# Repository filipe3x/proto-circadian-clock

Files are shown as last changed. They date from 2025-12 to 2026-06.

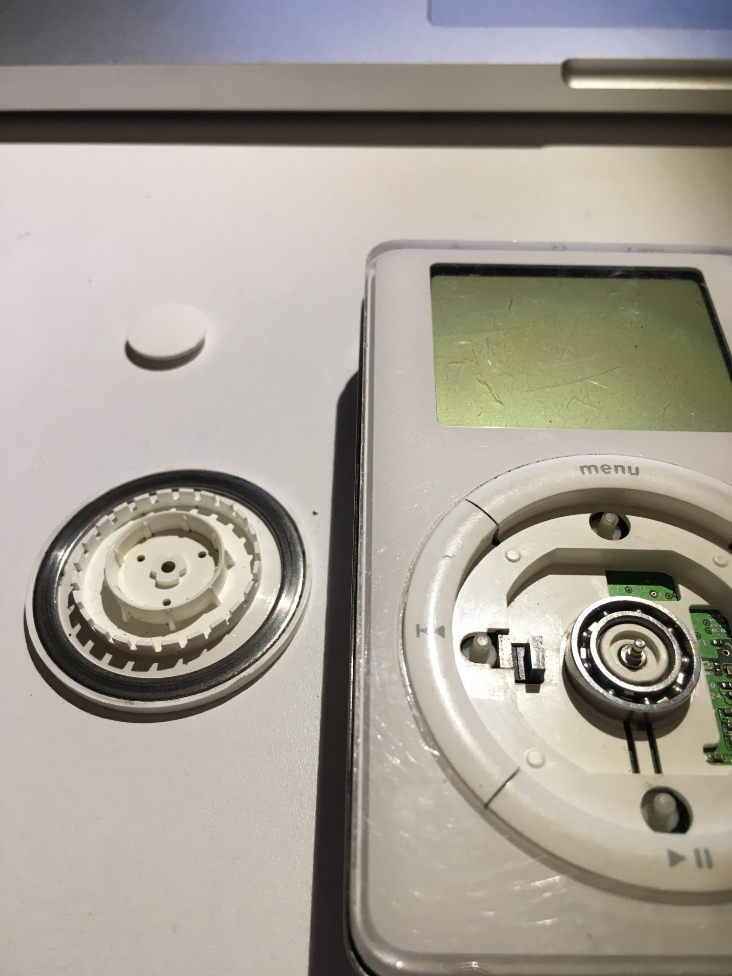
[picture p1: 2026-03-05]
product/click wheel ipod 1gen.JPG

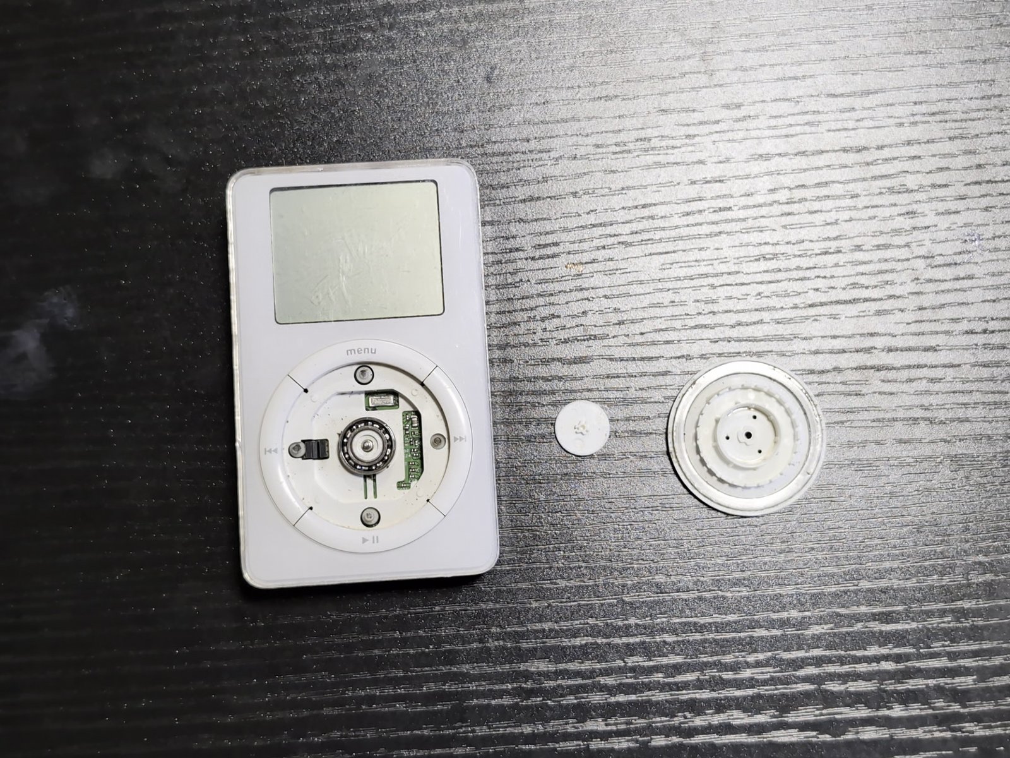
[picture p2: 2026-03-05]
product/click wheel ipod 1gen _2.jpg

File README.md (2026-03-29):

# 🌅 Proto Circadian Clock

An ESP32-powered LED clock that simulates the natural solar light cycle to support healthy circadian rhythms. The display gradually transitions from warm red tones at sunrise/sunset to bright white at midday, mimicking natural daylight patterns.

## Features

- **Automatic Solar Simulation** - Real-time color temperature based on astronomical sun position
- **Red Light Therapy Mode** - Pure red light for evening relaxation
- **Multi-WiFi Support** - Connects to multiple configured networks with automatic fallback
- **Offline Operation** - Works without internet using RTC or internal clock
- **NTP Synchronization** - Keeps time accurate via internet time servers
- **Low Power** - Disconnects WiFi after sync to save energy
- **Startup Sound & Alerts** - Retro-style 8-bit chiptune sounds on boot (can be disabled via captive portal)

## Hardware Requirements

| Component | Specification |
|---|---|
| Microcontroller | ESP32 Dev Module (4MB Flash) |
| Display | P10 32×16 RGB LED Panel (HUB75, 1/4 scan, SMD3535) |
| RTC (Optional) | DS3231 module |
| Button | Momentary push button |
| Buzzer (Optional) | MLT-5030 piezo buzzer or similar (passive, 3V, 5×5mm) |
| Power | 5V 2A minimum |

## Wiring

### Pinout Absoluto ESP32 — Todos os GPIOs

```
┌─────────────────────────────────────────────────────────────────┐
│                    ESP32-WROOM-32E  PINOUT                      │
├───────┬──────────────┬──────────┬───────────────────────────────┤
│ GPIO  │ Função       │ Direção  │ Notas                        │
├───────┼──────────────┼──────────┼───────────────────────────────┤
│       │ ── HUB75 (Painel P10 RGB) ──                           │
│  4    │ LAT          │ Output   │ Latch                        │
│  5    │ C            │ Output   │ Row select bit 2             │
│ 12    │ G2           │ Output   │ Green lower                  │
│ 13    │ B2           │ Output   │ Blue lower                   │
│ 14    │ R2           │ Output   │ Red lower                    │
│ 15    │ OE           │ Output   │ Output Enable (active LOW)   │
│ 16    │ CLK          │ Output   │ Pixel clock                  │
│ 17    │ D            │ Output   │ Row select bit 3             │
│ 19    │ B            │ Output   │ Row select bit 1             │
│ 23    │ A            │ Output   │ Row select bit 0             │
│ 25    │ R1           │ Output   │ Red upper                    │
│ 26    │ G1           │ Output   │ Green upper                  │
│ 27    │ B1           │ Output   │ Blue upper                   │
├───────┼──────────────┼──────────┼───────────────────────────────┤
│       │ ── I2C (RTC + OLED) ──                                 │
│ 21    │ SDA          │ Bidi     │ DS3231 (0x68) + SSD1306 (0x3C) │
│ 22    │ SCL          │ Bidi     │ Barramento partilhado        │
├───────┼──────────────┼──────────┼───────────────────────────────┤
│       │ ── Input (partilhado — ver INPUT_MODE) ──              │
│ 34    │ ENC_A/BTN_A  │ Input    │ Pull-up 10kΩ ext. Encoder A ou Botão A │
│ 35    │ ENC_B/BTN_B  │ Input    │ Pull-up 10kΩ ext. Encoder B ou Botão B │
│ 36    │ BTN_L        │ Input    │ Pull-up 10kΩ ext. Exclusivo DevKit     │
│ 39    │ ENC_BTN/BTN_R│ Input    │ Pull-up 10kΩ ext. Enc Click ou Botão R │
├───────┼──────────────┼──────────┼───────────────────────────────┤
│       │ ── Outros ──                                           │
│  0    │ BOOT Button  │ Input    │ INPUT_PULLUP, modo cycle     │
│  2    │ LED_BUILTIN  │ Output   │ LED azul onboard             │
│ 18    │ BUZZER       │ Output   │ PWM → R 1kΩ → Q1 MMBT2222A  │
│ 33    │ VBUS_SENSE   │ Input    │ ADC1_CH5, deteção 20V        │
│  1    │ DEBUG TX     │ Output   │ UART0 TX (USB-UART)          │
│  3    │ DEBUG RX     │ Input    │ UART0 RX (USB-UART)          │
├───────┼──────────────┼──────────┼───────────────────────────────┤
│       │ ── Não disponíveis ──                                  │
│ 6-11  │ Flash SPI    │ —        │ Reservados internamente      │
│ 20    │ Não exposto  │ —        │ Indisponível na maioria dos devkits │
│ 24    │ Não existe   │ —        │ Não existe no ESP32          │
│ 28-31 │ Não expostos │ —        │ Não expostos em devkits      │
├───────┼──────────────┼──────────┼───────────────────────────────┤
│       │ ── Livre ──                                            │
│ 32    │ RESERVA      │ I/O      │ ADC1_CH4, touch — I2S DIN ou expansão │
└───────┴──────────────┴──────────┴───────────────────────────────┘
```

**Total: 28 GPIOs utilizados, 1 livre (GPIO 32), 10 indisponíveis.**

### Input Mode — GPIOs Partilhados

Os GPIOs 34, 35 e 39 servem dois modos de input (mesmo circuito elétrico):

```cpp
#define INPUT_MODE 0  // Click Wheel — encoder magnético AS5600 I2C (brilho + modo)
#define INPUT_MODE 1  // DevKit Buttons — 4 botões táteis (A/B/L/R)
```

Ver `DEVKIT_DISPLAY_BUTTONS.md` e `product/CLICK_WHEEL.md` para detalhes.

### ESP32 → P10 Panel (HUB75)

```
ESP32          P10 Panel
─────          ─────────
GPIO 25   →    R1
GPIO 26   →    G1
GPIO 27   →    B1
GPIO 14   →    R2
GPIO 12   →    G2
GPIO 13   →    B2
GPIO 23   →    A
GPIO 19   →    B
GPIO 5    →    C
GPIO 17   →    D
GPIO 4    →    LAT
GPIO 15   →    OE
GPIO 16   →    CLK
GND       →    GND
```

### I2C — RTC DS3231 + OLED SSD1306 (barramento partilhado)

```
ESP32          DS3231 (0x68)     SSD1306 (0x3C)
─────          ──────            ──────────────
GPIO 21   →    SDA          →    SDA
GPIO 22   →    SCL          →    SCL
3.3V      →    VCC          →    VCC
GND       →    GND          →    GND
```

> **Nota:** O OLED (SSD1306) é opcional, montado no verso da PCB (modo DevKit).
> Não conflitua com o RTC — endereços I2C diferentes.

### Button

```
GPIO 0    →    Button   →    GND
```

### Buzzer (Optional)

```
ESP32          Buzzer Circuit
─────          ──────────────
GPIO 18   →    R1 (1kΩ)   →   Base (NPN)
                               │
                               ├── Collector → Buzzer+ → 5V
                               │
                               └── Emitter → GND

D1 (1N4148) across Buzzer (cathode to +5V)
```

Recommended transistor: 2N2222 or BC547

**Note:** GPIO 18 is used because GPIO 6-11 are internally connected to the ESP32 flash SPI and unavailable.

## Software Dependencies

### ESP32 Board Package

In Arduino IDE, add this URL to **File → Preferences → Additional Board Manager URLs**:
```
https://espressif.github.io/arduino-esp32/package_esp32_index.json
```

Then install **esp32** by Espressif Systems via **Tools → Board → Boards Manager**.

> ⚠️ **Important:** Use **ESP32 Arduino 2.0.x** (tested with 2.0.14), NOT version 3.x.
> The ESP32-HUB75-MatrixPanel-I2S-DMA library has compatibility issues with ESP32 Arduino 3.x
> due to breaking changes in the ESP-IDF 5.x I2S and DMA APIs. Version 2.0.x uses ESP-IDF 4.4
> which provides stable support for HUB75 LED panels.

### Arduino Libraries

Install via **Sketch → Include Library → Manage Libraries**:

| Library | Version | Author | Description |
|---|---|---|---|
| **ESP32-HUB75-MatrixPanel-I2S-DMA** | 3.0.x | mrcodetenz (mrfaptastic) | LED matrix driver |
| **RTClib** | 2.1.x | Adafruit | RTC DS3231 support |
| **Dusk2Dawn** | 1.0.x | DM Kishi | Solar calculations |
| **ESPAsyncWebServer** | 1.2.x | me-no-dev | Async web server for captive portal |
| **AsyncTCP** | 1.1.x | me-no-dev | Async TCP for ESP32 |

### Manual Installation

The P10 panel wrapper library (not in Library Manager):

```bash
cd ~/Arduino/libraries/
git clone https://github.com/filipe3x/P10_32x16_QuarterScan.git
```

## Configuration

### Location Settings

Edit these constants in `clock.ino`:

```cpp
// Your location (for solar calculations)
const float LATITUDE = 41.5362;    // Your latitude
const float LONGITUDE = -8.7813;   // Your longitude
const int TIMEZONE_OFFSET = 0;     // Hours from UTC

// Shift the solar cycle (e.g., -1 to wake up earlier)
const int SOLAR_OFFSET_HOURS = 1;
```

### WiFi Credentials

Copy `wifi_credentials.h.example` to `wifi_credentials.h` and add your networks:

```bash
cp wifi_credentials.h.example wifi_credentials.h
```

Then edit `wifi_credentials.h`:

```cpp
WiFiCredentials wifiNetworks[] = {
  {"YourNetwork1", "password1"},
  {"YourNetwork2", "password2"},
};
```

**Note:** `wifi_credentials.h` is ignored by git to keep your passwords private.

## Installation

1. Install [Arduino IDE](https://www.arduino.cc/en/software) with ESP32 board support
2. Install required libraries (see above)
3. Open `clock.ino`
4. Select board: **ESP32 Dev Module**
5. Set upload speed: **921600**
6. Configure your location and WiFi credentials
7. Upload to ESP32

## Usage

### Operating Modes

Press the button (GPIO 0) to cycle through modes:

| Mode | Description |
|---|---|
| **AUTO_SOLAR** | Automatic color based on sun position |
| **THERAPY_RED** | Constant red light for therapy/relaxation |
| **OFF** | Display turned off |

### Startup Sound

If buzzer is installed, the clock plays a retro-style 8-bit startup melody on boot. The sound can be:

- **Enabled/Disabled** via the captive portal web interface
- **Customized** with different chiptune melodies (NES/GameBoy style)
- **Future use** as alarm/notification sounds

The buzzer uses PWM to generate classic pulse wave tones with configurable duty cycles (12.5%, 25%, 50%) for authentic retro sound.

### Status Indicators (Boot)

| Color | Status |
|---|---|
| 🟢 Green | RTC + WiFi + NTP synced (perfect) |
| 🔵 Blue | WiFi + NTP synced (good) |
| 🟡 Yellow | RTC + WiFi, NTP failed |
| 🟣 Purple | RTC only, offline |
| 🟠 Orange | WiFi only, no valid time |
| 🔴 Red | Fully offline |

### Solar Color Schedule (Example: Winter, Portugal)

| Time | Elevation | Color | Brightness |
|---|---|---|---|
| 06:00 | -25° | Off | 0% |
| 07:30 | -12° | Deep red | 18% |
| 08:00 | -6° | Orange | 28% |
| 09:00 | 0° | Warm orange | 40% |
| 12:00 | 30° | Bright white | 100% |
| 18:00 | 0° | Warm orange | 40% |
| 21:00 | -12° | Deep red | 18% |
| 22:00 | -18° | Off | 0% |

## Troubleshooting

### Display not working
- Check 5V power supply (minimum 2A)
- Verify all HUB75 connections
- Ensure P10_32x16_QuarterScan library is installed

### RTC not detected
- System works without RTC (uses NTP)
- Check I2C connections (SDA=21, SCL=22)
- Verify 3.3V power (NOT 5V)
- Check CR2032 battery

### WiFi not connecting
- System works offline with RTC
- Check credentials in `wifiNetworks[]`
- Increase `WIFI_TIMEOUT_MS` for slow networks

### Wrong time/colors
- Verify `LATITUDE` and `LONGITUDE`
- Check `TIMEZONE_OFFSET` (0 for Portugal/UK)
- Adjust `SOLAR_OFFSET_HOURS` if needed

## Serial Monitor

Connect at **115200 baud** to see:
- Boot sequence and connectivity status
- Solar information (sunrise/sunset times)
- Elevation and color updates every 5 minutes
- Mode changes

## Roadmap

Potential future enhancements:

- **Dawn Simulator Mode** - Gradual wake-up light 30 min before alarm
- **Brightness Adjustment** - Manual or ambient sensor-based control
- **Web Interface** - Configuration via WiFi AP mode
- **Multiple Profiles** - Different settings per day of week
- **Home Assistant Integration** - MQTT control

## Authors

- **Filipe Marques** ([@filipe3x](https://github.com/filipe3x)) - Creator and maintainer
- **Claude** (Anthropic) - AI pair programming assistant

## License

MIT License - Feel free to use and modify.

## Contributing

Pull requests welcome! Please test on actual hardware before submitting.

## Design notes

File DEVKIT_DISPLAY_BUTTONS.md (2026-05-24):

# DevKit Display + Buttons — Ecrã I2C e 4 Botões no Verso da PCB

## Conceito

Transformar a PCB do Proto Circadian Clock num **kit de desenvolvimento Arduino** adicionando no lado oposto (bottom side):

- **1x Ecrã OLED monocromático** (I2C, partilha SDA/SCL com o RTC DS3231)
- **4x Copper contact pads** (A, B, L, R) com borrachas condutivas — estilo gamepad, perfil baixo, ideal para case 3D printed

OLED hand-soldered via header. Botões sem componentes a soldar — pads de cobre expostos na PCB + rubber domes (borracha condutiva) pressionados pelo case 3D printed.

> **Compatibilidade com Click Wheel:** O encoder magnético AS5600 (documentado em `product/CLICK_WHEEL.md`) usa o barramento I2C (0x36) — não consome GPIOs 34/35. Apenas o GPIO 39 (botão central do encoder) é partilhado com BTN_R. Uma flag de compilação (`INPUT_MODE`) seleciona o firmware adequado. Ver [secção 8](#8-partilha-de-pinos-com-click-wheel) para detalhes.

---

## 1. GPIOs Disponíveis (ESP32 Dev Module)

### Pinos Ocupados

| GPIO | Função | GPIO | Função |
|---|---|---|---|
| 0 | BOOT Button | 17 | HUB75 D |
| 1 | DEBUG TX | 18 | Buzzer |
| 2 | LED_BUILTIN | 19 | HUB75 B |
| 3 | DEBUG RX | 21 | I2C SDA |
| 4 | HUB75 LAT | 22 | I2C SCL |
| 5 | HUB75 C | 23 | HUB75 A |
| 6-11 | Flash SPI (N/A)  | 25 | HUB75 R1 |
| 12 | HUB75 G2 | 26 | HUB75 G1 |
| 13 | HUB75 B2 | 27 | HUB75 B1 |
| 14 | HUB75 R2 | 33 | VBUS_SENSE (ADC) |
| 15 | HUB75 OE | | |
| 16 | HUB75 CLK | | |

### Pinos Livres

| GPIO | Tipo | Notas |
|---|---|---|
| **32** | Input/Output | ADC1_CH4, touch, totalmente livre |
| **34** | Input only | ADC1_CH6, sem pull-up interno |
| **35** | Input only | ADC1_CH7, sem pull-up interno |
| **36** | Input only | SVP, ADC1_CH0, sem pull-up interno|
| **39** | Input only | SVN, ADC1_CH3, sem pull-up interno|

**Total: 5 GPIOs livres** — 4 para botões, 1 de reserva.

> **Nota:** GPIO 34-39 são input-only e **não têm pull-up interno**. Precisam de resistências pull-up externas (10kΩ) na PCB.

---

## 2. Ecrã OLED — SSD1306 0.96" 128x64 I2C

### Porquê SSD1306?

| Critério | SSD1306 0.96" |
|---|---|
| Interface | I2C (2 fios, partilha com RTC) |
| Resolução | 128×64 pixels |
| Endereço I2C | 0x3C (default) — sem conflito com DS3231 @ 0x68 |
| Alimentação | 3.3V ou 5V |
| Preço JLCPCB | ~$0.80-1.50 (módulo) |
| Tamanho | 27×27mm (ecrã ativo) |
| Biblioteca Arduino | Adafruit SSD1306 ou U8g2 (bem suportadas) |
| Consumo | ~20mA típico |

### Alternativas Consideradas

| Ecrã | Pros | Contras |
|---|---|---|
| SSD1306 0.91" 128×32 | Mais pequeno, barato | Menos resolução vertical  |
| SH1110 1.3" 128×64 | Maior, melhor leitura | Mais caro, ocupa espaço |
| ST7567 128×64 COG | Sem moldura, fino | Mais complexo, SPI melhor |

**Recomendação:** SSD1306 0.96" 128×64 — melhor relação preço/funcionalidade/disponibilidade.

### Ligação Elétrica

```
ESP32 GPIO 21 (SDA) ──── SDA  ┐
ESP32 GPIO 22 (SCL) ──── SCL  ├── OLED SSD1306 (0x3C)
3.3V ────────────────── VCC   │
GND ─────────────────── GND   ┘

(Mesmo barramento I2C que o DS3231 @ 0x68 — sem conflito)
```

**Pull-ups I2C:** O módulo DS3231 típico já inclui pull-ups de 4.7kΩ. A maioria dos módulos OLED também inclui. Se ambos tiverem, ficam em paralelo (~2.35kΩ) — funciona bem a 100/400kHz. Se usar OLED bare (sem módulo), adicionar 4.7kΩ a SDA e SCL.

---

## 3. Botões — 4x Copper Contact Pads + Rubber Domes (A, B, L, R)

### Conceito

Em vez de tactile switches soldados, cada botão é um par de **pads de cobre expostos** (sem solder mask) na PCB. Uma **borracha condutiva (rubber dome com carbon pill)** faz ponte entre os dois pads quando pressionada. É o mesmo princípio usado em comandos de TV, GameBoy, e calculadoras.

```
   Case 3D printed
   ┌─────────────────┐
   │   ┌────────┐    │  ← Botão moldado no case (guiado, solto)
   │   │  cap   │    │
   └───┤        ├────┘
       └───┬────┘
       ┌───▼────┐
       │ RUBBER │        ← Dome de borracha condutiva (carbon pill na base)
       │  DOME  │
   ────┤●  gap ●├─── PCB (bottom side)
       pad1   pad2       ← Dois pads cobre expostos, sem solder mask
```

**Vantagens para case 3D printed:**
- Perfil ultra-baixo (~1-2mm vs ~9.5mm de um tactile switch)
- Sem componentes a soldar nos botões — só as resistências pull-up
- Feel customizável pela dureza/forma da borracha
- Silencioso (sem click mecânico)
- O case 3D imprime os botões integrados ou como peças soltas guiadas

### Atribuição de Pinos

| Botão | GPIO | Tipo | Partilhado com Click Wheel? | Função Sugerida |
|---|---|---|---|---|
| **A** | 34 | Input only | Não (AS5600 usa I2C) | Confirmar / Select |
| **B** | 35 | Input only | Não (AS5600 usa I2C) | Cancelar / Back |
| **L** | 36 | Input only | Não — exclusivo DevKit | Esquerda / Menos |
| **R** | 39 | Input only | Sim — ENCODER_BTN | Direita / Mais |

> GPIO 32 fica de reserva para expansão futura (ex: I2S DIN para MAX98357A, sensor adicional).
>
> **Nota:** O encoder AS5600 da click wheel (`product/CLICK_WHEEL.md`) usa I2C (0x36) — não consome GPIOs 34/35. Apenas o GPIO 39 (botão central) é partilhado. A seleção é feita por `#define INPUT_MODE` no firmware.

### Circuito por Botão

```
3.3V ─── R (10kΩ) ──┬── GPIO 34/35/36/39
                     │
                   pad 1 ┐
                          ├── rubber dome (ponte condutiva quando premido)
                   pad 2 ┘
                     │
                    GND
```

- **Repouso:** Pull-up mantém GPIO HIGH (3.3V). Os pads não se tocam.
- **Premido:** Carbon pill na base do rubber dome faz ponte pad1↔pad2 → GPIO puxa para GND → lê LOW.

**Importante:** GPIO 34-39 **não têm pull-up interno**, portanto as resistências de 10kΩ são obrigatórias. Sem elas, o pino flutua quando o contacto está aberto.

### Debounce

Rubber domes têm transição mais suave que switches mecânicos — menos bounce. Debounce por software (20-50ms) no firmware é suficiente. Não são necessários condensadores.

---

## 4. BOM (Bill of Materials)

### Componentes na PCB (assembly JLCPCB)

| # | Componente | Qtd | JLCPCB Part | Tipo | Notas |
|---|---|-----|---|---|---|
| 1 | Resistência 10kΩ 0603 | 4 | C25804 | Basic | Pull-up para GPIO 34/35/36/39 |

> **Nota:** Os contact pads dos botões são apenas cobre exposto na PCB — não há componente a montar. A JLCPCB fabrica os pads automaticamente ao produzir a PCB (são áreas sem solder mask definidas nos Gerbers).

### Componentes hand-solder (comprados à parte)

| # | Componente | Qtd | Fonte | Preço Est. |
|---|---|-----|---|---|
| 2 | OLED 0.96" 128×64 SSD1306 I2C | 1 | AliExpress / LCSC | ~$1.00 |
| 3 | Header fêmea 1×4 2.54mm | 1 | C124413 (JLCPCB) ou AliExpress | ~$0.05 |
| 4 | Rubber dome pads 6-8mm (com carbon pill) | 4 | AliExpress "conductive rubber dome button" | ~$0.50/pack 50un |

### Custo Estimado por Placa

| Item | Custo |
|---|---|
| 4× Resistências | ~$0.01  |
| OLED SSD1306 | ~$1.00  |
| Header 1×4 | ~$0.05  |
| 4× Rubber domes | ~$0.04  |
| **Total** | **~$1.10** |

> Sem tactile switches. Sem condensadores de debounce. O custo de "botões" é essencialmente $0 na PCB — só os rubber domes comprados à parte (~$0.01/unidade em packs).

---

## 5. Implementação no KiCad

### 5.1 Esquemático

1. **Adicionar símbolos:**
   - `SSD1306` (ou genérico `OLED_I2C_128x64`) — ligar SDA, SCL, VCC, GND
   - 4× `SW_Push` — um por botão
   - 4× `R` (10kΩ) — pull-ups
   - Ligar aos global labels `SDA`, `SCL`, `3V3`, `GND` existentes
   - Criar net labels: `BTN_A` (GPIO34), `BTN_B` (GPIO35), `BTN_L` (GPIO36), `BTN_R` (GPIO39)

2. **Ligação ao ESP32:**
   ```
   OLED:
     SDA → Net "SDA" (já ligada a GPIO21)
     SCL → Net "SCL" (já ligada a GPIO22)
     VCC → 3V3
     GND → GND

   Botões:
     BTN_A → GPIO34 (via R pull-up a 3V3)
     BTN_B → GPIO35 (via R pull-up a 3V3)
     BTN_L → GPIO36 (via R pull-up a 3V3)
     BTN_R → GPIO39 (via R pull-up a 3V3)
   ```

### 5.2 Footprints e Estratégia Bottom Side

#### Footprints a usar

| Componente | Footprint KiCad | Library | Notas |
|---|---|---|---|
| Header OLED 1×4 | `Connector_PinHeader_2.54mm:PinHeader_1x04_P2.54mm_Vertical` | Built-in | THT, furos ø1.0mm |
| Contact pad (botão) | **Custom** — criar no Footprint Editor | — | 2 pads SMD expostos por botão |
| Resistência pull-up | `Resistor_SMD:R_0603_1608Metric_Pad0.98x0.95mm_HandSolder` | Built-in | SMD no bottom layer |

> O header OLED é THT — os furos atravessam a PCB e fazem de via automática entre F.Cu e B.Cu.
> Os contact pads e resistências são SMD no B.Cu (bottom).

#### Criar o footprint custom do contact pad

Não existe um footprint standard no KiCad para rubber dome pads. É fácil criar:

**Footprint Editor → File → New Footprint → nome: `ContactPad_RubberDome_8mm`**

1. **Pad 1** (sinal — GPIO):
   - Type: SMD
   - Shape: Roundrect (cantos arredondados)
   - Size: 3mm × 4mm
   - Layer: `B.Cu`
   - Net: GPIO (34/35/36/39)
   - Solder Mask: expandir 0.1mm (expõe o cobre — **essencial**)

2. **Pad 2** (GND):
   - Type: SMD
   - Shape: Roundrect
   - Size: 3mm × 4mm
   - Layer: `B.Cu`
   - Net: GND
   - Solder Mask: expandir 0.1mm

3. **Gap entre pads:** ~1mm (centro a centro: 4mm)

4. **Contornos:**
   - `B.CrtYd`: retângulo 8mm × 6mm (courtyard)
   - `B.SilkS`: label do botão (ex: "A", "B", "L", "R")
   - `B.Fab`: contorno do rubber dome (referência, ø8mm)

```
  Footprint (visto de baixo — B.Cu):
  ┌─────────────────────────┐
  │                         │  B.CrtYd (8×6mm)
  │   ┌───────┐ ┌───────┐  │
  │   │       │ │       │  │
  │   │ pad 1 │ │ pad 2 │  │  ← Cobre exposto (sem solder mask)
  │   │ GPIO  │ │  GND  │  │    3mm × 4mm cada, gap 1mm
  │   │       │ │       │  │
  │   └───────┘ └───────┘  │
  │         "A"             │  B.SilkS
  └─────────────────────────┘
```

> **Solder mask override** é o passo crítico. Sem ele, a máscara verde cobre os pads e o rubber dome não faz contacto com o cobre. No KiCad: Pad Properties → Solder Mask Override → `0.1` (mm).

#### Colocar footprints no bottom layer no KiCad

1. **Tools → Update PCB from Schematic** para importar os novos componentes
2. Os footprints aparecem no top layer por defeito
3. Selecionar o componente no PCB editor
4. Premir **`F`** (atalho para Flip) — o componente passa para B.Cu
5. Verificar: o componente aparece **espelhado** e em **azul** (cor do B.Cu)

O que acontece ao fazer Flip:
- **Silk screen** → B.SilkS (impresso no verso)
- **Courtyard** → B.CrtYd
- **Pads SMD** → B.Cu (bottom copper)
- **Pads THT** (header OLED) → mantêm furos em ambos os layers

#### Resistências SMD no bottom

As resistências 0603 ficam no B.Cu junto aos contact pads. Ao fazer Flip:
- Pads em B.Cu, silk em B.SilkS
- Traces roteados em B.Cu ligando: 3.3V → R pull-up → pad 1 (GPIO) do contact pad
- Via para ligar ao GPIO do ESP32 no top layer

### 5.3 PCB Layout (Bottom Side)

```
┌──────────────────────────────────────────┐
│              BOTTOM SIDE                 │
│          (visto de baixo)                │
│                                          │
│  R_L ─(L)                     (R)─ R_R  │  ← Contact pads + resistências
│                                          │
│           ┌──────────────┐               │
│           │    OLED      │               │
│           │   128×64     │               │
│           │   0.96"      │               │
│           │  [GND VCC    │               │
│           │   SCL SDA]   │               │  ← Header 1×4 THT
│           └──────────────┘               │
│                                          │
│  R_B ─(B)                     (A)─ R_A  │  ← Contact pads + resistências
│                                          │
└──────────────────────────────────────────┘

Legenda:
  (X)  = Contact pad (2 pads cobre expostos, ø~8mm total)
  R_X  = Resistência 10kΩ 0603 SMD (B.Cu)
  Tudo em B.Cu — perfil ~0mm (flush com a PCB)
```

#### Routing Strategy

Todos os componentes dos botões são SMD no bottom — routing inteiro em B.Cu:

```
    F.Cu (top layer)
    ┌─────────────────────────────────┐
    │  ESP32 GPIO34 ──┐               │
    │  3.3V ──────────┼──┐            │
    └─────────────────┼──┼────────────┘
                    [via][via]          ← Vias top→bottom
    ┌─────────────────┼──┼────────────┐
    │                 ▼  ▼            │
    │           ┌─[R 10k]─┐          │
    │           │          │          │
    │           ▼          │          │   B.Cu (bottom layer)
    │     ┌──────────┐     │          │
    │     │●pad1  pad2●│────┘          │
    │     │  GPIO   GND│              │   ← Contact pads (cobre exposto)
    │     └──────────┘                │
    │                                 │
    └─────────────────────────────────┘
```

Vantagem: routing dos botões **não interfere** com os traces HUB75 do top layer.

### 5.4 Passos no KiCad (Step-by-Step)

**Passo 1 — Criar o footprint custom (uma vez):**

1. **Footprint Editor → File → New Footprint**
2. Nome: `ContactPad_RubberDome_8mm`
3. **Add Pad** (pad 1):
   - Number: `1`, Type: `SMD`, Shape: `Roundrect`
   - Size X: `3`, Size Y: `4`, Layer: `B.Cu`
   - Pad Properties → Solder Mask Expansion (override): `0.1` mm
4. **Add Pad** (pad 2):
   - Number: `2`, Type: `SMD`, Shape: `Roundrect`
   - Size X: `3`, Size Y: `4`, Layer: `B.Cu`
   - Position X: `4` (offset 4mm do pad 1 → gap de 1mm)
   - Solder Mask Expansion (override): `0.1` mm
5. Adicionar contorno em `B.CrtYd` (8mm × 6mm)
6. Adicionar label em `B.SilkS` (referência: `%R`)
7. **File → Save** na library local do projeto

**Passo 2 — Esquemático:**

1. **Place → Add Symbol** → `SW_Push` → colocar 4 instâncias (representam o contacto)
2. **Place → Add Symbol** → `R` → colocar 4 instâncias (10kΩ)
3. **Place → Add Symbol** → `Conn_01x04` → colocar 1 (header OLED)
4. **Ligar** cada botão:
   ```
   3V3 ── R(10k) ──┬── net BTN_x (→ GPIO)
                    │
                  [SW]     ← Símbolo SW_Push (representa rubber dome)
                    │
                   GND
   ```
5. **Ligar** connector OLED: pin 1 → GND, pin 2 → 3V3, pin 3 → SCL, pin 4 → SDA
6. **Anotar** (Tools → Annotate Schematic)
7. **Atribuir footprints** (Tools → Assign Footprints):
   - SW1-SW4 → `ContactPad_RubberDome_8mm` (custom)
   - R → `R_0603_1608Metric_Pad0.98x0.95mm_HandSolder`
   - J_OLED → `PinHeader_1x04_P2.54mm_Vertical`

**Passo 3 — PCB:**

8. **Tools → Update PCB from Schematic** — componentes aparecem agrupados
9. **Selecionar todos os novos componentes** (contact pads + resistências + header)
10. **Premir `F`** para fazer Flip para o bottom layer
    - Contact pads e resistências: ficam em B.Cu (azul)
    - Header OLED (THT): furos visíveis em ambos os lados, silk em B.SilkS
11. **Posicionar** conforme layout da secção 5.3:
    - Header OLED centrado
    - Contact pads L/R nas laterais, A/B em baixo
    - Resistências junto ao contact pad de cada botão
12. **Rotear traces** (tecla `X`):
    - Selecionar layer B.Cu antes de começar
    - Traçar: via do GPIO (top→bottom) → R pull-up → pad 1 do contact pad
    - Traçar: pad 2 do contact pad → GND
    - Tecla `V` durante routing para adicionar via se necessário
13. **Adicionar plano GND no bottom** (se não existir): Place → Zone → B.Cu → net GND
14. **DRC** (Inspect → Design Rules Check) antes de gerar Gerbers
15. **3D Viewer** (View → 3D Viewer) — verificar:
    - Contact pads e OLED no verso (bottom)
    - Pads de cobre visíveis (cor cobre, sem máscara verde)
    - ESP32 e HUB75 no top

---

## 6. Firmware — Exemplo de Código

### Flag de Modo de Input

```cpp
// Em board_config.h — adicionar:
// ============================================================
// INPUT MODE — Seleciona hardware de input
// ============================================================
// O GPIO 39 é partilhado entre:
//   - Click Wheel (encoder magnético AS5600 I2C + botão central) — ver product/CLICK_WHEEL.md
//   - DevKit Buttons (4 botões táteis A/B/L/R)
// O AS5600 comunica via I2C (0x36), GPIO 34/35 ficam livres no modo click wheel.
// Apenas o firmware muda.
//
//   0 = INPUT_CLICK_WHEEL  — AS5600 I2C + click (brilho + modo)
//   1 = INPUT_DEVKIT_BUTTONS — 4 botões táteis (A/B/L/R)
//
#ifndef INPUT_MODE
  #define INPUT_MODE 1  // Default: DevKit buttons
#endif

#define INPUT_CLICK_WHEEL    0
#define INPUT_DEVKIT_BUTTONS 1

#if !BOARD_MATRIXPORTAL_S3
  // GPIO 36 é sempre exclusivo do DevKit (não usado pela click wheel)
  #define BTN_L_PIN   36   // Input only, pull-up externo (SVP)

  #if INPUT_MODE == INPUT_DEVKIT_BUTTONS
    #define BTN_A_PIN   34   // Partilhado com ENCODER_A
    #define BTN_B_PIN   35   // Partilhado com ENCODER_B
    #define BTN_R_PIN   39   // Partilhado com ENCODER_BTN
    #define DEVKIT_BUTTON_COUNT 4
  #elif INPUT_MODE == INPUT_CLICK_WHEEL
    #define AS5600_I2C_ADDR 0x36
    #define ENCODER_BTN_PIN 39
    #define CLICK_WHEEL_ENABLED 1
    // GPIO 34, 35, 36 ficam livres como botões auxiliares
  #endif
#endif
```

### Inicialização do OLED

```cpp
#include <Wire.h>
#include <Adafruit_GFX.h>
#include <Adafruit_SSD1306.h>

#define OLED_WIDTH  128
#define OLED_HEIGHT 64
#define OLED_I2C_ADDR 0x3C

Adafruit_SSD1306 oled(OLED_WIDTH, OLED_HEIGHT, &Wire, -1);

void setupOLED() {
  // I2C já inicializado pelo RTC (Wire.begin(21, 22))
  if (oled.begin(SSD1306_SWITCHCAPVCC, OLED_I2C_ADDR)) {
    oled.clearDisplay();
    oled.setTextSize(1);
    oled.setTextColor(SSD1306_WHITE);
    oled.setCursor(0, 0);
    #if INPUT_MODE == INPUT_DEVKIT_BUTTONS
      oled.println("DevKit Ready");
    #else
      oled.println("Click Wheel Ready");
    #endif
    oled.display();
  }
}
```

### Setup e Loop (DevKit Buttons)

```cpp
#if INPUT_MODE == INPUT_DEVKIT_BUTTONS

void setupDevKitButtons() {
  // Todos input-only com pull-up externo
  pinMode(BTN_A_PIN, INPUT);
  pinMode(BTN_B_PIN, INPUT);
  pinMode(BTN_L_PIN, INPUT);
  pinMode(BTN_R_PIN, INPUT);
}

bool readButton(uint8_t pin) {
  return digitalRead(pin) == LOW;  // Active LOW com pull-up
}

void loopDevKitButtons() {
  static uint32_t lastDebounce = 0;
  if (millis() - lastDebounce < 50) return;

  if (readButton(BTN_A_PIN)) { lastDebounce = millis(); /* Confirmar */ }
  if (readButton(BTN_B_PIN)) { lastDebounce = millis(); /* Cancelar  */ }
  if (readButton(BTN_L_PIN)) { lastDebounce = millis(); /* Esquerda  */ }
  if (readButton(BTN_R_PIN)) { lastDebounce = millis(); /* Direita   */ }
}

#endif // INPUT_DEVKIT_BUTTONS
```

> **Click Wheel mode:** Quando `INPUT_MODE == INPUT_CLICK_WHEEL`, usa-se o AS5600 via I2C (ver `product/CLICK_WHEEL.md` — setupClickWheel, handleClickWheel com polling I2C). Os GPIOs 34, 35 e 36 ficam disponíveis como botões auxiliares.

---

## 7. Considerações de Design

### Compatibilidade I2C

| Dispositivo | Endereço | Conflito? |
|---|---|---|
| DS3231 RTC  | 0x68 | Não |
| SSD1306 OLED| 0x3C | Não |
| AS5600 | 0x36 | Não |
| LIS3DH (S3) | 0x19 | N/A (outra placa) |

Os endereços não conflituam. O barramento I2C suporta múltiplos dispositivos sem problemas a 400kHz (Fast Mode).

### Consumo Energético Adicional

| Componente | Consumo |
|---|---|
| SSD1306 OLED | ~20mA |
| 4× Pull-ups | ~1.3mA total (0.33mA cada quando premido) |
| **Total extra** | **~21mA** |

Negligível comparado com o painel P10 (~2-5A).

### Mecânica e Case 3D Printed

- O OLED de 0.96" (27×27mm) cabe no verso de uma PCB para painel P10
- **Contact pads são flush com a PCB** — perfil ~0mm (só o cobre)
- **Rubber domes** adicionam ~1-2mm de altura — muito menos que tactile switches (~9.5mm)
- Altura total no verso: ~10mm (OLED com header) + ~2mm (rubber domes)
- O **case 3D printed** deve ter:
  - Cavidade para o OLED (recesso ~11mm de profundidade)
  - Botões moldados ou peças soltas que pressionam os rubber domes
  - Guias para alinhar os rubber domes com os contact pads

```
Case 3D (corte lateral):

   ┌────────────┐
   │  Botão cap │ ← Peça solta no case, guiada por paredes
   └─────┬──────┘
         │
   ┌─────▼──────┐
   │ Rubber dome│ ← Assente sobre os contact pads
   └────────────┘
   ═══●══gap══●═══ ← PCB bottom (pads cobre expostos)
   ════════════════ ← PCB top
   ┌────────────┐
   │  ESP32 /   │ ← Componentes top side
   │  HUB75     │
   └────────────┘
```

### Riscos e Mitigações

| Risco | Mitigação |
|---|---|
| Pull-ups duplos (RTC + OLED módulo) | Valor efetivo ~2.35kΩ, OK para I2C 400kHz |
| GPIO 36/39 glitch (errata ESP32) | Resolvido em rev. 3 do ESP32; adicionar 100nF |
| OLED interfere com refresh do P10 | I2C opera a 400kHz, P10 usa HUB75 paralelo — sem interferência |
| Rubber dome desalinhado | Case 3D deve ter guias de posicionamento para os domes |
| Oxidação dos contact pads | Aplicar ENIG (gold) ou HASL nos pads; solder mask override garante cobre exposto |

---

## 8. Partilha de Pinos com Click Wheel

### Mapa de Partilha

| GPIO/Bus | Pull-up | Click Wheel (`INPUT_MODE=0`) | DevKit Buttons (`INPUT_MODE=1`) |
|---|---|---|---|
| **I2C** (21/22) | Já existente (RTC) | AS5600 @ 0x36 (rotação) | — |
| **34** | 10kΩ externo | _(livre)_ | BTN_A (confirmar) |
| **35** | 10kΩ externo | _(livre)_ | BTN_B (cancelar)  |
| **36** | 10kΩ externo | _(livre)_ — BTN extra | BTN_L (esquerda)  |
| **39** | 10kΩ externo | ENCODER_BTN (click central)  | BTN_R (direita) |

### Porquê funciona sem conflito

1. **AS5600 no barramento I2C** — O encoder magnético comunica via I2C (endereço 0x36), partilhando o barramento com RTC (0x68) e OLED (0x3C). Sem conflito de endereços.
2. **GPIO 39 partilhado** — O botão central do click wheel e o BTN_R do DevKit partilham o mesmo GPIO com circuito idêntico (pull-up 10kΩ + active LOW).
3. **GPIO 34/35 livres no modo click wheel** — Com AS5600 no I2C, os GPIO 34/35 ficam livres e podem ser usados como botões auxiliares.
4. **Seleção por firmware** — `#define INPUT_MODE 0` ou `1` em `board_config.h`. Sem alteração de hardware para o botão central.

### PCB: AS5600 no I2C, botão no GPIO 39

```
              3.3V
               │
            R 10kΩ         ← Pull-up GPIO 39 (partilhado)
               │
         ┌─────┼─────┐
         │     │     │
      [DOME]  [SW]   ├── GPIO 39
      (BTN_R) (knob) │
         │     │     │
        GND   GND    │
                     ESP32

    I2C Bus (GPIO 21/22):
    ┌────┬────┬────┐
    │RTC │OLED│AS5600│  ← 0x68, 0x3C, 0x36
    └────┴────┴────┘
```

### GPIO 34/35/36 — Livres no modo Click Wheel

O AS5600 usa I2C para rotação + GPIO 39 para click. Os GPIOs 34, 35 e 36 ficam todos disponíveis como botões auxiliares no modo click wheel (ex: toggle OLED, menu rápido, presets de brilho).

---

## 9. Resumo

Esta adição transforma a PCB existente num kit de desenvolvimento versátil:

- **Custo:** ~$1.14 extra por placa (botões) | ~$1.60 extra (click wheel AS5600 + ímã)
- **Pinos usados:** 4 GPIOs (34, 35, 36, 39) — todos input-only
- **Partilha:** Apenas GPIO 39 partilhado com click wheel (botão central). AS5600 usa I2C (0x36)
- **I2C:** OLED + AS5600 partilhados com RTC, sem conflito de endereços (0x3C / 0x36 / 0x68)
- **Funcionalidade original:** 100% preservada
- **GPIO 32:** Livre para expansão futura (I2S DIN, sensor, output)

| Modo | Componentes | Input |
|---|---|---|
| `INPUT_DEVKIT_BUTTONS` | OLED (header hand-solder) + 4 rubber domes sobre contact pads (bottom) | A, B, L, R — navegação tipo gamepad |
| `INPUT_CLICK_WHEEL` | AS5600 encoder magnético (top, SMD) + ímã + OLED (bottom) | Rotação (brilho) + click (modo) + 3 BTN extra |

O ecrã OLED permite debug visual, menus de configuração, e display de informações sem necessitar de Serial Monitor. A mesma PCB serve como relógio circadiano (com click wheel AS5600) ou como dev board Arduino (com contact pads + rubber domes e ecrã), com case 3D printed.

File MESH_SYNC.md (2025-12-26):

# Proto Circadian Clock - Mesh Sync

Sistema de sincronização automática entre múltiplos dispositivos Proto Circadian Clock usando ESP-NOW.

## Visão Geral

Quando tens vários Proto Circadian Clocks na mesma casa/espaço, eles sincronizam-se automaticamente:
- **Mudança de modo instantânea** - Quando mudas o modo num dispositivo, todos os outros mudam imediatamente
- **Descoberta automática** - Novos dispositivos são detectados automaticamente
- **Sem configuração** - Funciona out-of-the-box, sem router WiFi necessário
- **Economia de energia** - WiFi desliga-se automaticamente quando não há outros dispositivos

## Modo Híbrido (Economia de Energia)

O mesh usa uma **máquina de estados adaptativa** para poupar energia:

```
┌─────────────────────────────────────────────────────────────────┐
│                     MÁQUINA DE ESTADOS                          │
├─────────────────────────────────────────────────────────────────┤
│                                                                 │
│   ┌──────────────┐                      ┌──────────────┐        │
│   │   MESH_OFF   │◄────────────────────►│ MESH_ACTIVE  │        │
│   │  (WiFi OFF)  │    encontrou peers   │  (WiFi ON)   │        │
│   │   ~0mA WiFi  │◄────────────────────►│   ~95mA      │        │
│   └──────┬───────┘    perdeu peers      └──────────────┘        │
│          │            (5 min timeout)          ▲                │
│          │ Timer 60s                           │                │
│          ▼                                     │                │
│   ┌──────────────┐                             │                │
│   │MESH_SCANNING │─────────────────────────────┘                │
│   │ (WiFi ON 3s) │     peers responderam                        │
│   │   ~95mA      │                                              │
│   └──────────────┘                                              │
│                                                                 │
└─────────────────────────────────────────────────────────────────┘
```

### Configuração

```cpp
#define MESH_SCAN_INTERVAL_MS 60000   // Scan a cada 60s quando sozinho
#define MESH_SCAN_DURATION_MS 3000    // 3s de escuta durante scan normal
#define MESH_INITIAL_SCAN_MS 65000    // 65s no primeiro scan (garante descoberta)
#define MESH_IDLE_TIMEOUT_MS 300000   // 5 min sem peers = desligar mesh
```

### Scan Inicial Longo

Para garantir que dispositivos se encontram mesmo que os scans estejam dessincronizados:

```
Boot:     ████████████████████████████████████████████████████████████████░░░░░░███░░░░░░
          ←───────────────── 65s ────────────────────────────────────────→     ←3s→
          Primeiro scan (longo, > 1 ciclo)                                     Seguintes
```

**Porquê 65s?** É maior que o intervalo de scan (60s), garantindo que apanha pelo menos um ciclo completo de qualquer outro dispositivo na rede.

### Consumo por Estado

| Estado | WiFi | Consumo | Duração |
|---|---|---|---|
| MESH_OFF | Desligado | ~20mA (só CPU+display) | 57s |
| MESH_SCANNING (inicial) | Ligado | ~95mA | 65s (só no boot) |
| MESH_SCANNING (normal) | Ligado | ~95mA | 3s |
| MESH_ACTIVE | Ligado | ~95mA | Contínuo |

**Consumo médio quando sozinho (após boot):**
```
(20mA × 57s + 95mA × 3s) / 60s = 23.75mA ≈ 24mA
```

**Comparação:**
| Cenário | Antes | Agora | Redução |
|---|---|---|---|
| 1 dispositivo sozinho | 95mA | 24mA | **75%** |
| 2+ dispositivos | 95mA | 95mA | 0% |

## Como Funciona

### Device ID Único

Cada ESP32 tem um identificador único de fábrica (eFuse MAC):
```
Chip ID: A4:CF:12:XX:XX:XX
```
Este ID é gravado no chip durante o fabrico e nunca muda.

### Timestamp de Primeira Instalação

Na primeira vez que o dispositivo arranca, guarda um timestamp em memória não-volátil (NVS):
```cpp
myFirstBootTime = now.unixtime() - 1577836800;  // Segundos desde 2020
```
Este timestamp determina a "antiguidade" do dispositivo.

### Eleição de Master

O dispositivo **mais antigo** (com o `firstBootTime` mais baixo) torna-se automaticamente o **Master**:

```
Dispositivo A: firstBootTime = 1000  → MASTER
Dispositivo B: firstBootTime = 2000  → SLAVE
Dispositivo C: firstBootTime = 3000  → SLAVE
```

Se o Master desaparecer (desligado >5 min), o próximo mais antigo assume.

## Protocolo ESP-NOW

### Porquê ESP-NOW?

| Característica | ESP-NOW | WiFi tradicional |
|---|---|---|
| Necessita router | Não | Sim |
| Latência | <10ms | 50-200ms |
| Alcance | ~200m | ~50m |
| Consumo | Baixo | Alto |
| Setup | Zero | Configuração |

### Tipos de Mensagem

```cpp
MSG_DISCOVERY  // Anúncio de presença (broadcast a cada 30s)
MSG_SETTINGS   // Definições + modo atual
MSG_REQUEST    // Pedido de definições (novo dispositivo)
MSG_ACK        // Confirmação de receção
```

### Estrutura da Mensagem

```cpp
struct MeshMessage {
  uint32_t magic;          // "PCLK" - identifica mensagens nossas
  uint8_t version;         // Versão do protocolo
  uint8_t msgType;         // Tipo de mensagem
  uint8_t senderId[6];     // ID do remetente
  uint32_t firstBootTime;  // Antiguidade do dispositivo
  uint16_t msgId;          // ID para ACKs
  SyncSettings payload;    // Dados (modo, lat, lon, etc)
};
```

**Tamanho total:** ~32 bytes por mensagem

## Fluxo de Sincronização

### 1. Descoberta

```
┌──────────────────────────────────────────────┐
│  Dispositivo A (novo) arranca                │
│                                              │
│  A → Broadcast DISCOVERY ─────────────────►  │
│                           ┌─────────────┐    │
│                           │ B (master)  │    │
│                           │ C (slave)   │    │
│                           └─────────────┘    │
│                                              │
│  A ← DISCOVERY de B e C ◄─────────────────   │
│  A regista B e C como peers                  │
│  A determina: B é mais antigo → B é master   │
│  A → REQUEST settings a B ─────────────────► │
│  A ← SETTINGS de B ◄───────────────────────  │
└──────────────────────────────────────────────┘
```

### 2. Mudança de Modo (Sync Imediato)

```
┌──────────────────────────────────────────────┐
│  Utilizador pressiona botão no dispositivo C │
│                                              │
│  C: currentMode = THERAPY_RED                │
│  C → Broadcast SETTINGS (modo=THERAPY_RED)   │
│                                              │
│  A recebe: aplica modo imediatamente         │
│  B recebe: aplica modo imediatamente         │
│                                              │
│  A → ACK (com backoff aleatório)             │
│  B → ACK (com backoff aleatório)             │
│                                              │
│  Resultado: Todos em THERAPY_RED em <50ms    │
└──────────────────────────────────────────────┘
```

### 3. Prevenção de Colisões (ACKs)

Quando múltiplos dispositivos recebem um broadcast, usam **backoff baseado no ID** para evitar colisões:

```cpp
uint8_t slot = deviceId[5] % 10;  // 0-9 baseado no ID
int backoff = 10 + (slot * 15) + random(0, 20);  // 10-170ms
```

```
t=0ms    Master envia SETTINGS
t=25ms   Slave A (slot 1) → ACK
t=55ms   Slave B (slot 3) → ACK
t=85ms   Slave C (slot 5) → ACK
         ↑ Sem colisões!
```

## Definições Sincronizadas

| Definição | Sync imediato | Fonte |
|---|---|---|
| Modo (AUTO/RED/OFF) | Sim | Qualquer dispositivo |
| Latitude | Eventual | Só master |
| Longitude | Eventual | Só master |
| Timezone | Eventual | Só master |
| Solar Offset | Eventual | Só master |

---

## Análise de Tráfego de Rede (Spam)

### Configuração Atual

| Parâmetro | Valor |
|---|---|
| `BROADCAST_INTERVAL_MS` | 30.000ms (30s) |
| Tamanho mensagem | ~32 bytes |
| Timeout de peer | 300.000ms (5 min) |

### Tráfego por Dispositivo

| Tipo | Frequência | Quem envia | Bytes/msg |
|---|---|---|---|
| DISCOVERY | 30s | Todos | 32 |
| SETTINGS | 30s | Só master | 32 |
| ACK | Por SETTINGS | Slaves | 32 |

### Cálculo de Tráfego Total

**Cenário: 1 Master + 4 Slaves (5 dispositivos)**

```
Por ciclo de 30s:
├── 5× DISCOVERY (todos)     = 160 bytes
├── 1× SETTINGS (master)     = 32 bytes
├── 4× ACK (slaves)          = 128 bytes
└── Total por ciclo          = 320 bytes

Por hora:  320 × 120 = 38.4 KB
Por dia:   38.4 × 24 = 922 KB ≈ 0.9 MB
```

### Escala com Número de Dispositivos

| Dispositivos | Msgs/hora | KB/hora | MB/dia |
|---|---|---|---|
| 2 | 360 | 11.5 | 0.27 |
| 5 | 840 | 26.9 | 0.65 |
| 10 | 1560 | 49.9 | 1.20 |
| 20 | 2880 | 92.2 | 2.21 |

### Avaliação

| Métrica | Estado | Comentário |
|---|---|---|
| Largura de banda | ✅ OK | <100 KB/hora é negligível |
| Colisões 802.11 | ⚠️ Baixo risco | Backoff mitiga |
| Interferência WiFi | ✅ OK | Canal 1 fixo, baixo duty cycle |
| Bateria (se aplicável) | ⚠️ Problema | Ver secção de energia |

### Otimizações Possíveis

#### Opção 1: Aumentar Intervalo de Broadcast
```cpp
#define BROADCAST_INTERVAL_MS 60000  // 60s em vez de 30s
```
**Impacto:** Reduz tráfego 50%, aumenta tempo de descoberta

#### Opção 2: Adaptive Broadcast
```cpp
// Se não há peers, broadcast mais frequente (descoberta)
// Se há peers estáveis, broadcast menos frequente
if (numPeers == 0) {
  interval = 10000;   // 10s - modo descoberta
} else if (allPeersStable) {
  interval = 120000;  // 2min - modo estável
} else {
  interval = 30000;   // 30s - modo normal
}
```

#### Opção 3: Eliminar ACKs para Broadcasts
Os ACKs para broadcasts periódicos são redundantes - a próxima mensagem serve como heartbeat implícito.
```cpp
// Em handleSettings:
// Não enviar ACK para broadcasts periódicos
// Só enviar ACK para mudanças de modo explícitas
```

#### Opção 4: Compressão de Discovery
Combinar DISCOVERY + SETTINGS numa só mensagem:
```cpp
// Reduz msgs/ciclo de 2 para 1 (master)
MSG_HEARTBEAT = DISCOVERY + modo atual
```

---

## Análise de Consumo de Energia

### Estados de Energia do ESP32

| Estado | Corrente | Descrição |
|---|---|---|
| Active (CPU + WiFi TX) | ~240mA | A transmitir |
| Active (CPU + WiFi RX) | ~95-100mA | A escutar |
| Modem Sleep | ~20mA | CPU ativo, WiFi off |
| Light Sleep | ~0.8mA | CPU pausado, WiFi off |
| Deep Sleep | ~10µA | Quase tudo off |

### Consumo Atual (Modo Híbrido Implementado)

**Solução implementada:** Máquina de estados que desliga WiFi quando não há peers.

```
Quando SOZINHO (1 dispositivo):
├── MESH_OFF: ~20mA (57s)
├── MESH_SCANNING: ~95mA (3s)
└── Consumo médio: ~24mA

Quando COM PEERS (2+ dispositivos):
├── MESH_ACTIVE: ~95mA contínuo
└── Sync instantâneo (<50ms)
```

### Impacto em Bateria

| Bateria | Capacidade | Autonomia (95mA) |
|---|---|---|
| 18650 (1S) | 2500mAh | 26 horas |
| 2× 18650 | 5000mAh | 52 horas |
| USB powerbank 10Ah | 10000mAh | 4-5 dias |

**Conclusão:** Inviável para operação a bateria sem otimizações.

### Comparação: Com vs Sem Mesh

| Modo | Corrente média | Autonomia (2500mAh) |
|---|---|---|
| Sem mesh (display only) | ~50mA | 50 horas |
| Com mesh (atual) | ~95mA | 26 horas |
| Com mesh otimizado | ~25mA | 100 horas |

### Estratégias de Otimização

#### Nível 1: Modem Sleep entre Broadcasts (Fácil)
```cpp
// Após enviar/receber, desligar modem por 25s
WiFi.setSleep(WIFI_PS_MAX_MODEM);

// Problema: Perde mensagens durante sleep
// Solução: Janelas de escuta sincronizadas
```
**Redução:** 95mA → ~30mA

#### Nível 2: Light Sleep com Wake Periódico (Médio)
```cpp
// Dormir 29s, acordar 1s para escutar/enviar
esp_sleep_enable_timer_wakeup(29000000);  // 29s
esp_light_sleep_start();

// Ao acordar:
initMeshSync();
delay(1000);  // Janela de escuta
sendDiscovery();
```
**Redução:** 95mA → ~5mA médio

#### Nível 3: Deep Sleep com ESP-NOW Wake (Avançado)
```cpp
// O ESP32 pode acordar com ESP-NOW em deep sleep
// mas requer configuração específica do RTC
esp_now_set_wake_window(50);  // 50ms janela
esp_wifi_set_inactive_time(ESP_IF_WIFI_STA, 1);
```
**Redução:** 95mA → ~0.5mA médio

### Trade-offs

| Otimização | Consumo | Latência sync | Complexidade |
|---|---|---|---|
| Atual | 95mA | <50ms | Baixa |
| Modem Sleep | 30mA | <1s | Baixa |
| Light Sleep | 5mA | <30s | Média |
| Deep Sleep | 0.5mA | <60s | Alta |

### Recomendação por Caso de Uso

| Caso | Alimentação | Recomendação |
|---|---|---|
| Ligado à corrente | 5V USB | Manter atual (simplicidade) |
| Powerbank ocasional | USB | Modem Sleep |
| Bateria permanente | 18650 | Light Sleep mínimo |
| Solar/bateria longa | Painel | Deep Sleep obrigatório |

---

## Debug Serial

O sistema produz logs detalhados via Serial (115200 baud):

```
=== DEVICE ID ===
Chip ID: A4:CF:12:XX:XX:XX
Raw: 0xXXXXXXXXXXXX
Primeira instalacao! Timestamp: 157234567

=== MESH SYNC ===
[MESH] ESP-NOW inicializado
[MESH] Device ID: A4:CF:12:XX:XX:XX
[MESH] First Boot: 157234567
[MESH] Estado: MASTER (default)
[MESH] Discovery broadcast (age: 157234567, peers: 0)

[MESH] Novo peer: B8:27:EB:XX:XX:XX (age: 157234590)
[MESH] Peer ESP-NOW adicionado
[MESH] Estado alterado: MASTER

[MESH] Mode change broadcast: 1
[MESH] Modo sync: AUTO_SOLAR -> THERAPY_RED
```

## Limitações

1. **Máximo 10 peers** - Pode ser aumentado em `MAX_PEERS`
2. **Canal fixo (1)** - Todos os dispositivos devem usar o mesmo canal
3. **Sem encriptação** - Mensagens não são cifradas (podia adicionar-se)
4. **Alcance ~200m** - Linha de vista; paredes reduzem significativamente
5. **Consumo elevado** - Não otimizado para bateria (ver análise acima)

## Resumo de Impacto

| Vetor | Estado Atual | Severidade | Ação Recomendada |
|---|---|---|---|
| Spam de rede | ~40 KB/hora | ✅ Baixa | Nenhuma (aceitável) |
| Colisões | Backoff implementado | ✅ Baixa | Monitorar em produção |
| Consumo energia (sozinho) | ~24mA | ✅ OK | Modo híbrido implementado |
| Consumo energia (com peers) | ~95mA | ⚠️ Média | Aceitável para sync instantâneo |
| Latência sync | <50ms | ✅ Excelente | Manter |

## Extensões Futuras

- [ ] Encriptação de mensagens (ESP-NOW suporta CCMP)
- [ ] Modo "follow the sun" - Um dispositivo partilha elevação solar calculada
- [ ] Sync de brightness individual
- [ ] OTA update coordenado entre dispositivos
- [ ] Heartbeat visual (LED pisca quando recebe de peer)
- [ ] **Light Sleep entre broadcasts** (prioridade se bateria)
- [ ] **Adaptive broadcast interval** (menos tráfego quando estável)
- [ ] **Eliminar ACKs redundantes** (heartbeat implícito)

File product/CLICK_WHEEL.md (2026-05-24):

# Click Wheel — Design & Implementação

## Contexto

Click wheel ao estilo iPod para o relógio circadiano. Controla brilho (rotação) e modo (botão central).

O iPod 1G era **capacitivo e completamente liso** — sem detents mecânicos. O "click" era o botão central. O prazer vinha do **momentum em software**. Este design segue o mesmo princípio: encoder magnético + ímã, sem detents.

> **Nota histórica:** A versão anterior deste design usava **2× ITR8307** (sensores ópticos reflectivos IR) com um disco óptico de 96 slots para gerar quadratura em GPIO 34/35. Após avaliação mais atenta, o AS5600 foi escolhido por ser mais simples (1 chip I2C vs 2 sensores + disco + 2 resistências), sem partes mecânicas de precisão (disco óptico), e com resolução 12-bit nativa (4096 posições) sem necessidade de quadratura em software. O custo é semelhante (~$1.50 vs ~$0.20 sensores + disco custom de ~€5–15).

---

## Hardware

### AS5600 — Encoder magnético absoluto 12-bit

O AS5600 (ams-OSRAM) é um encoder rotativo magnético contactless com saída I2C. Mede o ângulo absoluto (0–360°, resolução 0.0879°) de um ímã diametralmente magnetizado posicionado acima do chip.

| Parâmetro | Valor |
|---|---|
| Resolução | 12-bit (4096 posições/volta) |
| Interface | I2C (endereço fixo **0x36**) |
| Alimentação | 3.3V (VDD: 3.0–3.6V) |
| Consumo | ~6.5mA típico |
| Air gap (ímã ↔ chip) | 0.5–3.0mm |
| Ímã recomendado | Diametralmente magnetizado, ø6mm × 2.5mm |
| Package | SOIC-8 (SOP-8) |
| Tempo de resposta | ~150µs (modo rápido I2C 400kHz) |
| Temperatura | -40°C a +125°C |
| Saída alternativa | Analógica (0–VDD) ou PWM no pin OUT |

### Pinout do AS5600 (SOIC-8)

```
         ┌────────┐
   SCL  1│        │8  DIR
   SDA  2│ AS5600 │7  VDD
   PGO  3│        │6  (pad GND)
   GND  4│        │5  OUT
         └────────┘
```

| Pin | Nome | Ligação |
|-----|---|---|
| 1 | SCL | GPIO 22 (barramento I2C partilhado) |
| 2 | SDA | GPIO 21 (barramento I2C partilhado) |
| 3 | PGO | Não ligado (flutuante) — só para programação OTP |
| 4 | GND | GND |
| 5 | OUT | Não ligado (usa-se I2C para leitura) |
| 6 | (pad) | GND (pad térmico/eléctrico) |
| 7 | VDD | 3.3V (com 100nF decoupling) |
| 8 | DIR | GND (CW incrementa ângulo) ou VDD (CCW) |

### Esquemático — Typical Application

```
ESP32 GPIO 21 (SDA) ──┬── DS3231 SDA
                       ├── SSD1306 SDA
                       └── AS5600 pin 2 (SDA)

ESP32 GPIO 22 (SCL) ──┬── DS3231 SCL
                       ├── SSD1306 SCL
                       └── AS5600 pin 1 (SCL)

3.3V ──┬── AS5600 pin 7 (VDD)
       └── C_DEC 100nF ── GND

GND ─── AS5600 pin 4 (GND)
GND ─── AS5600 pin 6 (pad GND)

AS5600 pin 8 (DIR) ── GND       ← CW = ângulo incrementa
AS5600 pin 5 (OUT) ── N/C       ← Não usado (leitura via I2C)
AS5600 pin 3 (PGO) ── flutuante
```

**Pull-ups I2C:** Já existentes no barramento (do módulo RTC DS3231 — 4.7kΩ). Não adicionar novos.

**DIR pin:** Ligado a GND → rotação CW incrementa o ângulo. Para inverter, ligar a VDD.

### Ímã

| Parâmetro | Valor |
|---|---|
| Tipo | **Diametricamente magnetizado** (N–S através do diâmetro) |
| Material | NdFeB (neodímio) N35 ou superior |
| Tamanho | 6mm diâmetro × 2.5mm altura (standard) |
| Air gap | 0.5–3mm entre topo do ímã e topo do IC |
| Montagem | Colado no eixo do knob, centrado sobre o IC |
| Tolerância | ±0.5mm lateral (o AS5600 é tolerante) |
| Fonte | AliExpress "6x2.5mm diametric magnet" (~€0.05–0.15/un) |

> **IMPORTANTE:** O ímã deve ser **diametricamente magnetizado** (campo N–S perpendicular ao eixo de rotação). Ímãs axiais (N–S paralelo ao eixo) **não funcionam**.

```
Vista lateral:                Vista topo (campo magnético):

  ┌──────────┐ Knob
  │  ┌────┐  │                    N ←──── S
  │  │ímã │  │ ← 6mm Ø             (diametric)
  │  └────┘  │
  ═══════════  ← air gap 1-2mm
  ┌──────────┐
  │  AS5600  │ ← SOIC-8 no PCB
  └──────────┘
```

### BOM — Componentes Click Wheel (AS5600)

| Ref | Componente | LCSC | Basic/Extended | Qtd | Preço | Notas |
|-----|---|---|---|-----|---|---|
| U4 | AS5600-ASOM | C526588 | Extended | 1 | ~$1.50 | SMD assembly JLCPCB |
| C_AS | 100nF 0402 | — | Basic | 1 | ~$0.001 | Decoupling VDD |
| MAG | Ímã diametral ø6×2.5mm | — | Hand place | 1 | ~$0.10 | AliExpress, colado no knob |

**Custo total: ~$1.60** (vs ~€5–15 da solução óptica anterior com disco custom)

**GPIOs consumidos: 0** — reutiliza o barramento I2C existente (GPIO 21/22).

Footprint JLCPCB em falta? Usar:
```bash
python3 -m easyeda2kicad --symbol --footprint --3d --lcsc_id=C526588
```

### Botão Central (Click)

O botão central do encoder continua no **GPIO 39** (SENSOR_VN) com pull-up externo 10kΩ — partilhado com BTN_R do modo DevKit.

```
3.3V ─── 10kΩ ──┬── GPIO 39
                 │
              [SWITCH]    ← Botão central (click do knob)
                 │
                GND
```

### Compatibilidade I2C — Endereços no Bus

| Dispositivo | Endereço I2C | Função | Conflito? |
|---|---|---|---|
| DS3231 RTC | 0x68 | Relógio tempo-real | Não |
| SSD1306 OLED | 0x3C | Ecrã DevKit | Não |
| AS5600 | 0x36 | Encoder magnético | Não |

Todos coexistem no mesmo barramento I2C a 400kHz (Fast Mode) sem conflito.

---

## Firmware (TO DO — ainda não implementado)

> O código abaixo é referência de design. Ainda **não foi aplicado** ao `clock.ino` / `board_config.h`.

### Registos I2C do AS5600

| Registo | Endereço | Tipo | Descrição |
|---|---|---|---|
| RAW ANGLE | 0x0C (H) + 0x0D (L) | Read | Ângulo raw 12-bit (0–4095) |
| ANGLE | 0x0E (H) + 0x0F (L) | Read | Ângulo com offset aplicado |
| STATUS | 0x0B | Read | Bit 5: magnet detected, Bit 4: too weak, Bit 3: too strong |
| AGC | 0x1A | Read | Automatic Gain Control (0–255) — indica qualidade do sinal |
| MAGNITUDE | 0x1B (H) + 0x1C (L) | Read | Magnitude do campo magnético |

### TO DO 1: board_config.h — adicionar defines do click wheel AS5600

```c
// ============================================================
// CLICK WHEEL (AS5600 Encoder Magnético + Botão Central)
// ============================================================
// Rotação = brilho (leitura de ângulo via I2C)
// Click central = change mode (GPIO 39)
// BOOT (GPIO0) mantém-se livre para flash/debug
// AS5600 no barramento I2C existente (0x36, sem conflito)
#define AS5600_I2C_ADDR       0x36
#define AS5600_RAW_ANGLE_REG  0x0C   // Registos 0x0C:0x0D (12 bits)
#define AS5600_STATUS_REG     0x0B   // Bit 5: magnet detected
#define AS5600_AGC_REG        0x1A   // Automatic gain control

#if BOARD_MATRIXPORTAL_S3
  #define ENCODER_BTN_PIN 11
#else
  // GPIO 39: input-only, pull-up externo 10kΩ a 3.3V
  #define ENCODER_BTN_PIN 39   // SENSOR_VN — click do encoder
#endif

// INPUT_MODE seleciona entre click wheel e devkit buttons (ver DEVKIT_DISPLAY_BUTTONS.md)
#define CLICK_WHEEL_ENABLED    1    // 1 = click wheel activa, 0 = desactivada
#define ENCODER_INVERT_DIR     0    // 1 = inverter CW/CCW (ou trocar DIR pin)
#define BRIGHTNESS_STEP        10   // Incremento base por unidade de rotação
#define BRIGHTNESS_MIN         10   // Brilho mínimo
#define ENCODER_BTN_DEBOUNCE_MS 200 // Debounce do click central
#define AS5600_POLL_MS         20   // Intervalo de polling I2C (20ms = 50Hz)
#define AS5600_ANGLE_THRESHOLD 30   // Ângulo mínimo (de 4096) para registar 1 tick
```

### TO DO 2: clock.ino — variáveis globais e leitura I2C

```c
// ============= CLICK WHEEL (AS5600 Encoder Magnético) =============
#if CLICK_WHEEL_ENABLED
#include <Wire.h>

int           lastAngle         = -1;    // Último ângulo lido (-1 = não inicializado)
int           accumAngle        = 0;     // Ângulo acumulado desde último tick
unsigned long lastWheelPollMs   = 0;
volatile bool encoderBtnPressed = false;
volatile unsigned long encoderBtnLastMs = 0;

void IRAM_ATTR encoderBtnISR() {
  unsigned long now = millis();
  if ((now - encoderBtnLastMs) >= ENCODER_BTN_DEBOUNCE_MS) {
    encoderBtnPressed = true;
    encoderBtnLastMs  = now;
  }
}

// Lê ângulo raw 12-bit do AS5600 via I2C
int readAS5600Angle() {
  Wire.beginTransmission(AS5600_I2C_ADDR);
  Wire.write(AS5600_RAW_ANGLE_REG);
  if (Wire.endTransmission(false) != 0) return -1;  // NACK → sensor ausente

  Wire.requestFrom((uint8_t)AS5600_I2C_ADDR, (uint8_t)2);
  if (Wire.available() < 2) return -1;

  int high = Wire.read();
  int low  = Wire.read();
  return ((high & 0x0F) << 8) | low;  // 12-bit: 0–4095
}

// Verifica se o ímã está detectado
bool as5600MagnetOK() {
  Wire.beginTransmission(AS5600_I2C_ADDR);
  Wire.write(AS5600_STATUS_REG);
  if (Wire.endTransmission(false) != 0) return false;

  Wire.requestFrom((uint8_t)AS5600_I2C_ADDR, (uint8_t)1);
  if (Wire.available() < 1) return false;

  uint8_t status = Wire.read();
  return (status & 0x20) != 0;  // Bit 5 = MD (Magnet Detected)
}

#endif
```

### TO DO 3: clock.ino — setupClickWheel()

```c
void setupClickWheel() {
  // I2C já inicializado pelo RTC (Wire.begin(21, 22))

  // Verificar presença do AS5600 no bus I2C
  Wire.beginTransmission(AS5600_I2C_ADDR);
  if (Wire.endTransmission() == 0) {
    Serial.println("[WHEEL] AS5600 detectado no I2C (0x36)");

    if (as5600MagnetOK()) {
      Serial.println("[WHEEL] Ímã detectado — OK");
    } else {
      Serial.println("[WHEEL] AVISO: Ímã não detectado (verificar posição/air gap)");
    }

    lastAngle = readAS5600Angle();
  } else {
    Serial.println("[WHEEL] ERRO: AS5600 não encontrado no I2C!");
  }

  // Botão central — GPIO 39 input-only, pull-up externo
  pinMode(ENCODER_BTN_PIN, INPUT);
  attachInterrupt(digitalPinToInterrupt(ENCODER_BTN_PIN), encoderBtnISR, FALLING);

  Serial.println("[WHEEL] Click wheel AS5600 inicializada");
}
```

Chamar em `setup()`, após `Wire.begin(21, 22)`.

### TO DO 4: clock.ino — handleClickWheel()

```c
void handleClickWheel() {
  // --- Polling do ângulo (não-bloqueante, 50Hz) ---
  unsigned long now = millis();
  if (now - lastWheelPollMs < AS5600_POLL_MS) return;
  lastWheelPollMs = now;

  int angle = readAS5600Angle();
  if (angle < 0 || lastAngle < 0) {
    lastAngle = angle;
    return;  // Sensor não disponível
  }

  // Calcular delta com wrap-around (0 ↔ 4095)
  int delta = angle - lastAngle;
  if (delta > 2048)  delta -= 4096;
  if (delta < -2048) delta += 4096;

  #if ENCODER_INVERT_DIR
    delta = -delta;
  #endif

  lastAngle = angle;

  // Acumular ângulo — só dispara tick quando passa o threshold
  accumAngle += delta;

  int ticks = accumAngle / AS5600_ANGLE_THRESHOLD;
  if (ticks != 0) {
    accumAngle -= ticks * AS5600_ANGLE_THRESHOLD;  // Manter resto

    int newBrightness = constrain(
      configBrightness + ticks * BRIGHTNESS_STEP,
      BRIGHTNESS_MIN, MAX_BRIGHTNESS_CAP
    );

    if (newBrightness != configBrightness) {
      configBrightness = newBrightness;
      setSafeBrightness(configBrightness);

      // Feedback visual: barra nas 2 linhas inferiores
      int barWidth = map(configBrightness, BRIGHTNESS_MIN, MAX_BRIGHTNESS_CAP, 0, 32);
      uint16_t barColor;
      if (configBrightness < MAX_BRIGHTNESS_CAP / 2) {
        barColor = display->color565(0, 200, 80);
      } else if (configBrightness < MAX_BRIGHTNESS_CAP * 3 / 4) {
        barColor = display->color565(251, 191, 36);
      } else {
        barColor = display->color565(255, 60, 20);
      }
      display->fillRect(0, 14, 32, 2, display->color565(0, 0, 0));
      display->fillRect(0, 14, barWidth, 2, barColor);

      Serial.printf("[WHEEL] Brilho: %d/%d (angle=%d)\n",
                    configBrightness, MAX_BRIGHTNESS_CAP, angle);
    }
  }

  // --- Click central: change mode ---
  if (encoderBtnPressed) {
    encoderBtnPressed = false;
    buttonPressed = true;  // Dispara handleButton() no próximo ciclo
  }
}
```

### TO DO 5: clock.ino — forward declarations e integração

Adicionar forward declarations:
```c
#if CLICK_WHEEL_ENABLED
void setupClickWheel();
void handleClickWheel();
#endif
```

Integrar no `setup()` e `loop()`:
```c
// Em setup(), após Wire.begin(21, 22):
#if CLICK_WHEEL_ENABLED
  setupClickWheel();
#endif

// Em loop(), após handleButton():
#if CLICK_WHEEL_ENABLED
  handleClickWheel();
#endif
```

---

## O que torna a click wheel viciante

A diferença entre "funciona" e "não consigo parar de girar":

### Hardware
- **Sem detents** — knob liso, rotação contínua sem clicks mecânicos
- **Alta resolução** — AS5600: 4096 posições/revolução (12-bit nativo)
- **Sem desgaste** — contactless, sem peças mecânicas a degradar
- **Posição absoluta** — ao ligar, sabe imediatamente o ângulo
- **Resposta rápida** — polling a 50Hz via I2C, ~150µs por leitura

### Software (a implementar)

```
Velocidade angular   →  incremento variável
Lenta               →  ±1 (fino)
Média               →  ±15 (médio)
Rápida (flick)      →  ±60 (salto grande)
```

**Momentum/inércia** — após soltar, o valor continua e desacelera. É isto que faz o iPod parecer mágico.

**Snap** — no final do movimento, encaixa no valor mais próximo com micro-efeito visual.

Algoritmo sugerido:
```c
// Medir velocidade angular (delta/intervalo)
float velocity = abs(delta) / (float)AS5600_POLL_MS;

// Aceleração: quanto mais rápido, maior o step
int step = BRIGHTNESS_STEP;
if (velocity > 2.0) step *= 3;
if (velocity > 6.0) step *= 6;

// Aplicar com momentum (decaimento exponencial)
momentum = delta * step + momentum * 0.7;
configBrightness = constrain(configBrightness + (int)momentum, BRIGHTNESS_MIN, MAX_BRIGHTNESS_CAP);
```

---

## Vantagens do AS5600 vs alternativas

### vs Encoder óptico (ITR8307 + disco)

| | Óptico (anterior) | AS5600 (actual) |
|--|---|---|
| Resolução | 96 PPR (384 c/ quadratura) | **4096/rev (12-bit)** |
| Disco custom | Sim (3D print, ~€5–15) | **Não (ímã €0.10)** |
| Alinhamento | Crítico (2 sensores + disco ±0.1mm) | **Fácil (ímã ±0.5mm)** |
| GPIOs | 2 (GPIO 34, 35) | **0 (I2C partilhado)** |
| Desgaste | Possível (pó, disco) | **Nenhum (contactless)** |
| Posição absoluta | Não | **Sim** |
| Custo total | ~€5–15 (com disco) | **~$1.60** |

### vs Encoder mecânico (EC11)

| | EC11 mecânico | AS5600 magnético |
|--|---|---|
| Feel | Click-click-click (tátil) | Fluído, sem resistência |
| Resolução | 20–30 PPR | 4096 posições (12-bit) |
| Momentum possível | Limitado pelos detents | Sim, total |
| Desgaste | 15k–30k ciclos | Sem desgaste (sem contacto) |
| Interface | 2× GPIO (quadratura + ISR) | I2C (partilhado) |
| Componentes | 1 encoder + 2 pull-ups | 1 IC + 1 cap + 1 ímã |
| Custo | ~$0.30 | ~$1.50 (IC) + ~$0.10 (ímã) |
| Veredito | Bom para prototipagem rápida | Melhor para produto final iPod-style |

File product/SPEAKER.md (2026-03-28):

# SPEAKER.md — Áudio no Proto Circadian Clock

## Estado actual (clockv7)

### Hardware: BZ1 — Piezo Passivo

```
GPIO18 → R6 (1kΩ) → Q1 Base (MMBT2222A)
                      Q1 Collector → 5V_OUT → BZ1(+) (TMB12A05 / C252948)
                                               BZ1(-) → GND
                      D5 (MMBD4148SE) → back-EMF protection
```

- Componente: TMB12A05 (aliexpress C252948), frequência ressonante 4–5 kHz
- Alimentação: 5V via Q1 (não directamente do GPIO)
- Geração: **LEDC PWM** (square wave) — `BUZZER_PIN = GPIO18`
- Volume: limitado; apenas variação do duty cycle tem algum efeito em piezo

### Hardware: U9 — MAX98357AEWL+T (DNP)

O MAX98357A já está presente no esquemático e PCB clockv7 como **DNP** (`exclude_from_bom yes`). Footprint e traces pré-roteadas para facilitar clockv8. Não consta no BOM nem na montagem JLCPCB.

Ligações actuais no esquemático clockv7 (U9 DNP):

```
GPIO18 (BUZZER) → R47K → R47K → SD_MODE (A1)    [controlo shutdown via GPIO]
5V_OUT  ───────────────────────► VDD     (A2)     [alimentação 5V]
IO32    ───────────────────────► DIN     (B1)     [I2S data]
IO33    ───────────────────────► BCLK    (C1)     [I2S bit clock]
IO2     ───────────────────────► LRCLK   (C3)     [I2S word select]
GND     ───────────────────────► GND/EP  (C2)     [+ vias térmicas]
GND     ───────────────────────► GAIN_SLOT (B2)   [15 dB]
                                 OUT+ (A3) ──► speaker+
                                 OUT- (B3) ──► speaker-
```

**Decoupling VDD:** 100nF + 10µF ao GND, o mais próximo possível do U9.

### Circuito SD_MODE — Análise

```
GPIO18 → R47K → R47K → SD_MODE (A1)
          94K total
```

- **GPIO18 = HIGH (3.3V):** SD_MODE ≈ 3.3V → **ON, canal esquerdo**
- **GPIO18 = LOW (0V):** GPIO puxa activamente a 0V → SD_MODE ≈ 0V → **shutdown** (~1 µA)

Reutiliza o pin BUZZER: no clockv7 (piezo montado, U9 DNP) o PWM não afecta nada; no clockv8 (piezo DNP, U9 montado) GPIO18 vira puro controlo ON/OFF.

**Pitfall — falta pull-down no SD_MODE:**
Durante o boot do ESP32 (~100-300ms), os GPIOs estão em alta impedância. Sem pull-down dedicado, o pull-up interno fraco do MAX98357A pode ligar o amp brevemente → **pop no speaker**. Referência: consola com MAX98357A usa R (51K) de SD_MODE → GND como rede de segurança.

**Recomendação — adicionar 1 resistor:**
```
GPIO18 → R47K → R47K → SD_MODE (A1)
                            ↓
                        R (47K-51K) → GND    ← ADICIONAR
```

Opcionalmente, incluir **footprint DNP** para C (4.7µF) entre SD_MODE e GND como anti-pop / soft-start.

### Firmware: Motor Chiptune LSDJ-inspirado (`sound.h` / `sound.cpp`)

| Componente | Detalhes |
|---|---|
| Oscilador | LEDC channel 0, timer 0, 8-bit |
| Frame sequencer | Timer ISR a **512 Hz** (idêntico ao Game Boy) |
| Polifonia | Arpeggio por time-division (simula acordes) |
| Noise | LFSR 15-bit (Game Boy CH4) clocked ~4 kHz |
| BPM | `ticks_per_step = (512 × 60) / (bpm × 4)` |

**Formato de dados (inspirado em LSDJ):**

```
Song → Chain[] → Pattern[] → Step {note, cmd, val, inst}
```

**Comandos de efeito:**

| Cmd | Hex | Descrição |
|-----|-----|---|
| CMD_NONE | 0x00 | Sem efeito |
| CMD_ARP  | 0x01 | Arpeggio: `val = 0xXY` (semi1 \| semi2) |
| CMD_VIB  | 0x02 | Vibrato: `val = 0xSD` (speed \| depth) |
| CMD_DUTY | 0x03 | Duty cycle: val = 0–3 (12/25/50/75%) |
| CMD_ENV  | 0x04 | Volume envelope: `val = 0xAD` |
| CMD_POR  | 0x05 | Portamento (glide) |
| CMD_HOP  | 0x0F | Hop para step destino |

**Melodias predefinidas:**

- `snd_play_startup()` — escala pentatónica ascendente + arpejo final C-E-G
- `snd_play_alarm()` — "Aurora": 3 fases (pulso suave → melodia → alerta máximo)
- `SONG_CIRCADIAN` — tema de demonstração LSDJ-style (melodia + baixo + percussão LFSR)

---

## Upgrade planeado (clockv8) — MAX98357A I2S

### Motivação

O piezo passivo tem limitações severas de qualidade sonora. Para o alarme circadiano gradual funcionar como pretendido (aurora suave), é necessário um speaker real com amplificador I2S.

### Módulo: MAX98357AEWL+T

- Amplificador I2S digital Class D, mono, 3 W @ 4 Ω
- Alimentação: 5V_OUT (2.5V–5.5V range; 5V maximiza potência de saída)
- Interface: I2S digital (sem DAC externo necessário)
- LCSC: **C2682619**
- Package: WLP-9 (3×3, 0.4mm pitch) — 1.595mm × 1.415mm
- **Footprint KiCad:** `Maxim_WLP-9_1.595x1.415_Layout3x3_P0.4mm_Ball0.27mm_Pad0.25mm_NSMD`
  - ✅ Usar este default do KiCad — dimensões exactas do datasheet Maxim
  - ❌ Não usar `WLP-9_1.468x1.448mm` (genérico, ligeiramente pequeno)
  - ❌ Não usar o easyeda2kicad `WLP-9_L1.4-W1.3-P0.40-R3-C3-BR` (1.4×1.3mm, pequeno)

### Pinout completo MAX98357AEWL+T (WLP-9, 3×3 grid, 0.4mm pitch)

```
        Col 1      Col 2        Col 3
Row A:  SD_MODE    VDD          OUT+ (OUTP)
Row B:  DIN        GAIN_SLOT    OUT- (OUTN)
Row C:  BCLK       GND/EP       LRCLK
```

| Pin | Nome | Tipo | Ligação clockv7 (DNP) |
|-----|---|---|---|
| A1  | SD_MODE | Shutdown / ch. select | GPIO18 → 2× R47K (94K total). ON com HIGH, shutdown com LOW |
| A2  | VDD | Alimentação | 5V_OUT + decoupling 100nF ∥ 10µF |
| A3  | OUT+ (OUTP) | Saída BTL + | Pad speaker + |
| B1  | DIN | I2S data in | IO32 (livre no clockv7) |
| B2  | GAIN_SLOT | Ganho analógico | GND directo → 15 dB |
| B3  | OUT− (OUTN) | Saída BTL − | Pad speaker − |
| C1  | BCLK | I2S bit clock | IO33 (libertar de VBUS_SENSE → mover para IO36) |
| C2  | GND / EP | GND + thermal pad | GND + vias térmicas (≥4× 0.3mm drill) |
| C3  | LRCLK | I2S word select | IO2 (sem LED físico na PCB custom) |

**Notas por pino:**

- **SD_MODE (A1):** Shutdown e selecção de canal:
  - GND → Shutdown (~1 µA)
  - VDD → ON, canal esquerdo
  - Float → ON, canal esquerdo (pull-up interno fraco)
  - 100kΩ → GND → canal direito
  - 1.5MΩ → VDD → mono mix (L+R)/2
  - **Actual (clockv7):** GPIO18 → 2× R47K → SD_MODE — permite shutdown por software
  - **Recomendação:** adicionar R (47K-51K) pull-down → GND para garantir shutdown durante boot ESP32
- **VDD (A2):** 2.5V–5.5V. Usar **5V_OUT** para potência máxima (3W @ 4Ω). Decoupling: 100nF + 10µF o mais próximo possível.
- **OUT+ (A3) / OUT− (B3):** Saída BTL (bridge-tied load). Ligar directamente ao speaker (4Ω ou 8Ω). **Não ligar ao GND.** Sem capacitor de acoplamento necessário (BTL).
- **DIN (B1):** I2S data. → IO32 (livre no clockv7).
- **GAIN_SLOT (B2):** Programação de ganho por resistor ou ligação directa:
  - GND directo → **15 dB** ← actual
  - Float (pull-up interno) → 12 dB
  - VDD → 9 dB
  - Resistores específicos → 6 / 3 / 0 dB
- **GND/EP (C2):** Pad térmico central. Ligar a GND com **mínimo 4 vias térmicas** (0.3mm drill). Crítico para dissipar calor (3W @ 4Ω).
- **BCLK (C1):** I2S bit clock. → IO33 (libertar de VBUS_SENSE → mover para IO36 no clockv8).
- **LRCLK (C3):** Word select (44.1kHz ou 22.05kHz). → IO2 (liberto em clockv8, sem LED físico na PCB custom).

### Pinout I2S no ESP32 custom PCB

| GPIO | Função I2S | Notas |
|---|---|---|
| **IO32** | I2S DIN (dados) | Livre no clockv7 |
| **IO33** | I2S BCLK (bit clock) | Libertar de VBUS_SENSE → mover para IO36 |
| **IO2**  | I2S LRCLK (word select) | Sem LED físico na PCB custom |
| **IO18** | SD_MODE (enable/shutdown) | Reutiliza pin BUZZER (piezo DNP no clockv8) |

### Questão: IO2 e o Error LED

No clockv7, `ERROR_LED_PIN = 2` (LED de diagnóstico). No clockv7, o ESP32 é genérico — **não há NeoPixel** (`HAS_NEOPIXEL = false`).

**Solução para clockv8:** Como o clockv7/v8 é uma **PCB custom**, o IO2 não tem de ter um LED físico. Basta **não rotear IO2 para um LED na PCB** (DNP — Do Not Populate). Os erros de sistema já estão reflectidos na cor do display via `currentStatus` (6 estados com cores distintas: verde/azul/amarelo/roxo/laranja/vermelho).

### VBUS_SENSE — mover IO33 → IO36

Para libertar IO33 para I2S BCLK:

```
IO36 (VP) = ADC1_CH0 = input-only, sem output
→ Perfeito para VBUS_SENSE (só leitura ADC)
```

Ajuste na PCB: redirigir o divisor resistivo (47kΩ + 5.6kΩ) de IO33 para IO36.

### Ligação física MAX98357A (clockv8)

```
ESP32          MAX98357A (U9)             Passivos
------         ---------------            --------
IO32  ───────► DIN    (B1)
IO33  ───────► BCLK   (C1)
IO2   ───────► LRCLK  (C3)
IO18  → R47K → R47K → SD_MODE (A1)       + R 47K-51K pull-down → GND (ADICIONAR)
5V_OUT ──────► VDD    (A2)                + C 100nF ∥ C 10µF → GND
GND   ───────► GND/EP (C2)               + vias térmicas (≥4×)
GND   ───────► GAIN_SLOT (B2)            → 15 dB
               OUT+ (A3) ──► speaker+    (4Ω ou 8Ω)
               OUT- (B3) ──► speaker-
```

### Firmware — alterações para clockv8

```c
// board_config.h — secção ESP32 custom PCB
#define VBUS_SENSE_PIN      36              // movido de IO33 → IO36 (VP, ADC1_CH0)
#define VBUS_SENSE_CHANNEL  ADC1_CHANNEL_0  // IO36 = ADC1_CH0

// I2S MAX98357A
#define HAS_I2S_SPEAKER    true
#define I2S_DIN_PIN        32
#define I2S_BCLK_PIN       33
#define I2S_LRCLK_PIN      2
#define I2S_SD_MODE_PIN    18   // reutiliza BUZZER_PIN (piezo DNP no clockv8)

// Error LED — sem LED físico na PCB clockv8
// (diagnóstico via display currentStatus)
#define ERROR_LED_PIN      -1   // DNP
```

```c
// sound_i2s.h — novo módulo para clockv8
#include <driver/i2s.h>

#define I2S_PORT          I2S_NUM_0
#define I2S_SAMPLE_RATE   22050   // Hz — suficiente para alarme/voz
#define I2S_BITS          16
#define I2S_CHANNELS      1       // Mono (MAX98357A é mono)
```

---

## Comparação piezo vs I2S

| Critério | BZ1 Piezo (clockv7) | MAX98357A I2S (clockv8) |
|---|---|---|
| Qualidade | Square wave, limitada | PCM 16-bit, real |
| Frequências reproduzíveis | ~1–8 kHz (ressonância 4-5 kHz) | 20 Hz – 20 kHz |
| Volume | Baixo (~70 dB) | 85–90 dB @ 3 W/4 Ω (a 5V) |
| Alarme gradual | Apenas variação duty/envelope | Fade-in real via amplitude PCM |
| Custo PCB | ~0.30 € (Q1 + BZ1) | ~1.50 € (módulo) + speaker |
| Complexidade firmware | LEDC + timer ISR | driver I2S (ESP-IDF) |
| Pinos GPIO | 1 (GPIO18) | 3 (DIN + BCLK + LRCLK) + 1 (SD_MODE via GPIO18) |
| Shutdown | N/A | GPIO18 LOW → ~1 µA |

---

## Componentes em falta (comparação com design de referência)

Análise baseada em esquemático de consola com MAX98357AEWL+T:

| Componente | Valor | Função | Estado | Prioridade |
|---|---|---|---|---|
| R pull-down SD_MODE → GND | 47K–51K | Garante shutdown durante boot ESP32 (anti-pop) | **Em falta** | **Alta** |
| C SD_MODE → GND | 4.7µF (DNP) | Soft-start / anti-pop opcional | **Em falta** | Baixa — incluir footprint DNP |

---

## Plano de implementação clockv8

1. **PCB:**
   - Mover divisor VBUS de IO33 → IO36
   - Adicionar R pull-down (47K-51K) de SD_MODE → GND
   - Opcionalmente adicionar footprint DNP para C 4.7µF em SD_MODE
   - Rotear IO32/IO33/IO2 para U9 (traces já pré-roteadas)
   - DNP error LED em IO2
   - DNP piezo BZ1 + Q1 + R6 + D5
   - Pad para speaker 4 Ω (ex: 28 mm × 28 mm, ~1 W)

2. **Firmware:**
   - Novo ficheiro `sound_i2s.cpp` com driver I2S
   - Manter `sound.cpp` (piezo) activo para clockv7 via `#if !HAS_I2S_SPEAKER`
   - Reescrever `snd_play_alarm()` com buffer PCM para fade-in suave
   - Controlo SD_MODE: `digitalWrite(I2S_SD_MODE_PIN, HIGH/LOW)` para ON/OFF
   - Opção: manter motor chiptune para efeitos curtos (boot beep) mesmo com I2S

3. **Compatibilidade:**
   - `board_config.h` controla qual stack de áudio compila
   - clockv7 = piezo LEDC como agora
   - clockv8 = I2S MAX98357A

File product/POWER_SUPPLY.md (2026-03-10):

# Power Supply - Circadian Clock PCB

**Data:** Março 2026
**Versão:** 4.2 - CH224K + SY8388ARHC (Bulletproof, BUCK1 removido)
**Esquemático KiCad:** `product/kicad/clockv7/psu.kicad_sch`

---

## Changelog

| Data | Versão | Alterações |
|---|---|---|
| Mar 2026 | 4.0 | **Design final**: CH224K (PD 20V) + SY8388ARHC (Buck 8A). Documento único — substitui POWER_SUPPLY v1/v2/v3 e PSU_20V_SCHEMA_DESIGN. |
| Mar 2026 | 4.1 | **Bulletproof**: Worst-case VOUT analysis, correcção TVS D6 (SMBJ24CA), specs protecção SY8388ARHC, alinhamento BOM↔KiCad (caps 1206/C12891). |
| Mar 2026 | 4.2 | **BUCK1 removido**: Removido BUCK1 (L1=2.2µH) — PFM noise. Só BUCK2 (L2=4.7µH) montado. Ripple recalculado. |

---

## 1. Visão Geral

### 1.1 Arquitectura

```
USB-C VBUS ──► CH224K (PD 20V) ──► SY8388ARHC (Buck 8A) ──► 5V Rail
               (C970725)            (C5110279)
```

O design final utiliza apenas **2 ICs** para a PSU:

| IC | Função | LCSC | Preço |
|----|---|---|---|
| **CH224K** | USB PD 3.0 Sink — pede 20V | C970725 | ~$0.32 |
| **SY8388ARHC** | Buck síncrono 8A, 24V in | C5110279 | ~$0.53 |

**Total ICs PSU: ~$0.85** (vs ~$1.40+ com IP2721 + TPS56838)

### 1.2 Especificações

| Parâmetro | Mínimo | Típico | Máximo | Notas |
|---|---|---|---|---|
| Potência entrada | 27W | 30W | 45W | USB-C PD |
| Tensão entrada | 5V | 20V | 24V | PD negociado |
| Tensão saída | 4.9V | 5.0V | 5.1V | ±2% regulação |
| Corrente saída | — | 5A | 8A | Picos HUB75 |
| Eficiência | 90% | 93% | — | @ 20V→5V, 3A |

### 1.3 Perfis de Potência

```
Estratégia de Negociação PD (CH224K com CFG1 NC = 20V):
═══════════════════════════════════════════════════════

  PRIORIDADE 1: 20V (Preferido) ★
  ────────────────────────────────
  • 20V @ 1.5A = 30W → 5V @ 5.6A (após buck 93%)
  • 20V @ 3A = 60W → 5V @ 11A (limitado pelo buck a 8A)
  ✓ Disponível em ~85% das fontes PD
  ✓ Menor corrente no cabo = menores perdas I²R

  PRIORIDADE 2: 15V (Fallback automático)
  ────────────────────────────────────────
  • 15V @ 2A = 30W → 5V @ 5.6A
  ✓ Ratio 3:1, eficiência ~93%

  PRIORIDADE 3: 9V (Fallback)
  ───────────────────────────
  • 9V @ 3A = 27W → 5V @ 4.8A (após buck 90%)
  ⚠️ Brilho máximo ~80% (capado em software)

  FALLBACK FINAL: 5V (Emergência / USB básico)
  ─────────────────────────────────────────────
  • 5V @ 3A = 15W → Bypass directo (buck pass-through)
  ⚠️ Brilho máximo ~40%
═══════════════════════════════════════════════════════
```

---

## 2. Porquê CH224K + SY8388ARHC

### 2.1 Comparação PD Trigger: CH224K vs IP2721

| Parâmetro | CH224K (escolhido) | IP2721 (anterior) |
|---|---|---|
| **Tensões suportadas** | **5V, 9V, 12V, 15V, 20V** | 5V, 15V, 20V (sem 9V/12V!) |
| **Protocolos** | PD 3.0/2.0 + BC1.2 + QC2.0/3.0 | PD 2.0 apenas |
| **MOSFET externo** | **Não necessário** | Sim (AO3400A) |
| **Power Good pin** | **Sim (PG, open-drain)** | Não |
| **Rd interno (5.1kΩ)** | **Sim** | Não (R externas) |
| **Package** | ESSOP-10 (compacto) | TSSOP-16 |
| **LCSC** | C970725 | C603176 |
| **Preço** | **~$0.32** | ~$0.40 |
| **Config tensão** | Resistência única ou 3 GPIOs | Jumper SEL |

**Vantagens concretas do CH224K:**

1. **Suporta todas as 5 tensões PD** — o IP2721 saltava 9V e 12V, o que fazia com que fontes que só tinham 9V/12V não funcionassem
2. **Sem MOSFET externo** — VBUS liga directo ao buck. O IP2721 precisava de AO3400A + circuito de gate drive. Menos 1 componente, menos 1 ponto de falha
3. **PG (Power Good)** — LED de erro hardware indica imediatamente se o PD falhou, sem esperar pelo ESP32
4. **Rd internos** — não precisa de R3/R4 5.1kΩ externas nos CC1/CC2. Menos 2 componentes
5. **Mais barato** — $0.32 vs $0.40 + $0.03 (MOSFET) + $0.02 (resistências) = ~$0.45
6. **Config simples para 20V fixo** — CFG1/CFG2/CFG3 todos NC. Zero componentes de configuração

### 2.2 Comparação Buck: SY8388ARHC vs TPS56838 vs SY8368AQQC

| Parâmetro | SY8388ARHC (escolhido) | TPS56838 (anterior) | SY8368AQQC (v1) |
|---|---|---|---|
| **VIN máx** | 24V | 28V | 18V |
| **IOUT** | 8A | 8A | 8A |
| **Modo** | **PWM + auto-skip** com FCCM disponível | FCCM nativo | PFM a light load |
| **Compensação** | **Interna** | D-CAP3 (interna) | Externa (COMP pin) |
| **Frequência** | 600kHz (fixa) | 500/800/1200kHz | ~600kHz |
| **Package** | **QFN-16 2.5x2.5mm** | VQFN-HR 10-pin 3x3mm | QFN-20 3x3mm |
| **LCSC** | **C5110279** | C37533416 | C207642 |
| **Preço** | **~$0.53** | ~$1.00+ | ~$0.40 |
| **Coil whine** | **Não** (PWM contínuo) | Não (FCCM) | **Sim!** (PFM) |
| **Thermal pad** | QFN-16 EP (melhor) | 10-pin EP | QFN-20 EP |

**Vantagens concretas do SY8388ARHC:**

1. **Custo** — ~$0.53 vs ~$1.00+ do TPS56838. Quase metade do preço para especificações equivalentes
2. **Sem coil whine** — ao contrário do SY8368AQQC que entrava em pulse-skipping (PFM) a carga leve, causando frequência audível nos kHz. O SY8388ARHC mantém PWM contínuo a 600kHz (inaudível)
3. **Compensação interna** — sem necessidade de rede RC externa no loop de compensação. Menos componentes, mais simples de rotear
4. **QFN-16 compacto** — 2.5x2.5mm com exposed pad generoso para dissipação térmica
5. **Disponibilidade JLCPCB** — Extended mas com bom stock e preço baixo
6. **Silergy** — marca reconhecida em power management, amplamente usada em produtos consumer

### 2.3 O Problema do Pulse-Skipping (PFM) — Porquê NÃO o SY8368

```
O Problema: Pulse Skipping (PFM) a carga leve
══════════════════════════════════════════════

  PWM normal (600kHz):
  ██░░░░░░██░░░░░░██░░░░░░██░░░░░░  → Frequência FIXA, inaudível ✓

  Pulse skipping (carga leve, SY8368):
  ██░░░░░░░░░░░░░░░░░░░░██░░░░░░░░░░░░░░░░░░░░██
    ↑                      ↑
    Pulsos espaçados → frequência cai para kHz AUDÍVEL!

  O SY8368AQQC não tem pin MODE para forçar PWM contínuo.
  A light load (ex: ESP32 sozinho, sem painel), entra em PFM
  e o indutor vibra na gama audível (1-20kHz) → coil whine.

  Solução SY8388ARHC:
  ██░░░░░░██░░░░░░██░░░░░░██░░░░░░  → PWM contínuo SEMPRE ✓

  O SY8388ARHC mantém frequência de switching constante a 600kHz
  mesmo com carga muito leve. Trade-off: eficiência ligeiramente
  menor a no-load (~mA extra), mas SILÊNCIO garantido.
══════════════════════════════════════════════════
```

### 2.4 Resumo de Vantagens do Design Final

| Métrica | Design Anterior (IP2721 + TPS56838) | Design Final (CH224K + SY8388ARHC) |
|---|---|---|
| **Custo ICs** | ~$1.40 (IC + MOSFET) | **~$0.85** (-39%) |
| **N.º componentes PSU** | ~18 | **~14** (-4 componentes) |
| **Tensões PD** | 3 (5/15/20V) | **5 (5/9/12/15/20V)** |
| **Coil whine** | Não (FCCM) | **Não (PWM contínuo)** |
| **MOSFET externo** | Sim (AO3400A) | **Não** |
| **Resistências CC** | 2× 5.1kΩ | **0** (Rd interno) |
| **Compensação externa** | Não (D-CAP3) | **Não** (interna) |
| **Power Good LED** | Não | **Sim** |
| **Simplicidade** | Média | **Alta** |

---

## 3. Circuito CH224K (U5) — PD Sink Controller

### 3.1 Configuração

Para pedir **20V fixo**, usa-se o modo resistência com CFG1 floating:

- **CFG1 (pin 2)** = NC → 20V
- **CFG2 (pin 3)** = NC
- **CFG3 (pin 9)** = NC

### 3.2 Pinout e Ligações

```
         ┌──────────────────────────┐
         │      CH224K (ESSOP-10)    │
         │                          │
    VDD ─┤1                    10├─ PG (Power Good, open-drain)
   CFG1 ─┤2                     9├─ CFG3
   CFG2 ─┤3                     8├─ VBUS
     DP ─┤4                     7├─ CC2
     DM ─┤5                     6├─ CC1
         │                          │
         │     [EPAD = GND]         │
         └──────────────────────────┘
```

| Pin | Nome | Liga a | Notas |
|-----|---|---|---|
| 1 | VDD | VBUS via R1 1kΩ + C_VDD 1µF→GND | Regulador interno 3.3V |
| 2 | CFG1 | NC (floating) | 20V (resistor mode) |
| 3 | CFG2 | NC | Ignorado em resistor mode |
| 4 | DP | NC | Não usado (só PD via CC) |
| 5 | DM | NC | Não usado |
| 6 | CC1 | USB-C CC1 directo | Rd interno 5.1kΩ |
| 7 | CC2 | USB-C CC2 directo | Rd interno 5.1kΩ |
| 8 | VBUS | NC | Só necessário para BC1.2/QC legacy |
| 9 | CFG3 | NC | Ignorado em resistor mode |
| 10 | PG | Pull-up 10kΩ + NPN → Error LED | Open-drain, LOW = PD OK |
| EPAD | GND | GND | Thermal pad |

### 3.3 Circuito de Aplicação

```
                        USB-C Connector
                       ┌─────────────────┐
        VBUS ──────────┤ VBUS            │
                       │                 │
        CC1 ───────────┤ CC1             │
        CC2 ───────────┤ CC2             │
                       │                 │
        D+/D- ─────────┤ D+/D-           │──► CH340C (dados USB)
                       │                 │
        GND ───────────┤ GND             │
                       └─────────────────┘
                              │
              ┌───────────────┼───────────────┐
              │               │               │
              ▼               ▼               ▼

  VBUS ──[R1 1kΩ]──► VDD(1) ──[C_VDD 1µF]── GND      ← Alimentação CH224K

                CFG1(2) ── NC                          ← 20V fixo
                CFG2(3) ── NC
                  DP(4) ── NC
                  DM(5) ── NC
                 CC1(6) ── USB-C CC1 (directo)         ← Rd interno
                 CC2(7) ── USB-C CC2 (directo)
                VBUS(8) ── NC
                CFG3(9) ── NC
                 PG(10) ── Error LED (NPN inverter)

  VBUS ──┬──────────────────────────────► SY8388ARHC VIN
         │ (DIRECTO, sem MOSFET)
         │
      [D6 TVS]  SMBJ24CA (Vrwm=24V, bidirecional)
         │
        GND
```

### 3.4 Error LED (PG + NPN)

```
  VDD ──[R_PU 10kΩ]──┬── PG (CH224K pin 10)
                      │
                 [R_BASE 10kΩ]
                      │
                      B
                     /
  VDD ──[330Ω]──LED──C  Q (MMBT2222A)
                      \
                       E
                       │
                      GND

  Sem PD: PG = HIGH-Z (pull-up) → NPN ON → LED ON (erro!)
  PD OK:  PG = LOW              → NPN OFF → LED OFF
```

### 3.5 Fallback Automático

| Carregador | Tensão obtida | PG pin | Error LED |
|---|---|---|---|
| PD 20V/15V/12V/9V/5V | 20V | LOW | OFF |
| PD só 15V/12V/9V/5V | 15V fallback | LOW | OFF |
| PD só 12V/9V/5V | 12V fallback | LOW | OFF |
| PD só 9V/5V | 9V fallback | LOW | OFF |
| PD só 5V | 5V PD | LOW | OFF |
| USB sem PD (USB-A, Mac) | 5V default | HIGH-Z | ON |

---

## 4. Circuito SY8388ARHC (U1) — Buck Converter

### 4.1 Especificações

| Parâmetro | Valor | Notas |
|---|---|---|
| VIN | 4.5V - 24V | Suporta 20V PD com margem |
| VOUT | Ajustável via FB | 5.0V configurado |
| IOUT | 8A contínuo | |
| VFB | 0.6V ±1% | Tensão referência feedback |
| Frequência | 600kHz (fixa) | Sem coil whine |
| Controlo | Compensação interna | Sem rede RC externa |
| RDS(ON) HS | ~20mΩ | High-side MOSFET |
| RDS(ON) LS | ~10mΩ | Low-side MOSFET |
| Soft-start | Integrado | |
| Proteções | OVP, OCP, OTP, UVLO | |
| Package | QFN-16-EP 2.5x2.5mm | Thermal pad |
| LCSC | C5110279 | Extended |

### 4.2 Pinout

```
              ┌──────────────────────┐
              │  SY8388ARHC (top)    │
              │   QFN-16 2.5×2.5mm  │
              │                      │
         BS ─┤1                  16├─ NC
     IN(1) ─┤2                  15├─ NC
     IN(2) ─┤3                  14├─ EN
     IN(3) ─┤4                  13├─ SS
   PGND(1) ─┤5                  12├─ FB
   PGND(2) ─┤6                  11├─ COMP (NC)
   PGND(3) ─┤7                  10├─ PG
     LX(1) ─┤8                   9├─ LX(2)
              │                      │
              │   [THERMAL PAD]      │
              │      PGND            │
              └──────────────────────┘
```

### 4.3 Ligações

| Pin | Nome | Liga a | Notas |
|-----|---|---|---|
| 1 | BS | C_BOOT 100nF → LX | Bootstrap high-side driver |
| 2,3,4 | IN | VBUS + C_VIN | Entrada 5-20V |
| 5,6,7 | PGND | GND (power) | Power ground |
| 8,9 | LX | L2 (4.7µH) | Switch node — minimizar cobre! |
| 10 | PG | NC ou ESP32 GPIO | Power-good (open-drain) |
| 11 | COMP | NC | Compensação interna |
| 12 | FB | Divisor R_FB3/R_FB4 | Feedback (0.6V ref) |
| 13 | SS | C_SS ou float | Soft-start |
| 14 | EN | VIN (float = always-on) | Enable |
| 15,16 | NC | — | Não usados |
| PAD | PGND | GND via vias térmicas | 4-6 vias 0.3mm |

### 4.4 Rede de Feedback — R_FB3 (22kΩ) e R_FB4 (3kΩ)

O SY8388ARHC tem uma referência interna de **0.6V** no pino FB. O divisor
resistivo reduz a tensão de saída (5V) para 0.6V, permitindo ao IC regular:

- Se VOUT sobe acima de 5V → FB > 0.6V → IC reduz duty cycle
- Se VOUT desce abaixo de 5V → FB < 0.6V → IC aumenta duty cycle

```
                    VOUT = 5V
                        │
                   [R_FB3] 22kΩ (1%)   ← "upper" (LCSC: C31850)
                        │
                        ├────────────► FB (pin 12 SY8388ARHC)
                        │
                   [R_FB4] 3kΩ (1%)    ← "lower" (LCSC: C4211)
                        │
                       GND

Cálculo:
  V_FB = VOUT × R_FB4 / (R_FB3 + R_FB4) = 5 × 3k / 25k = 0.6V ✓
  VOUT = 0.6V × (1 + R_FB3/R_FB4) = 0.6 × (1 + 22/3) = 5.0V ✓
```

### 4.5 Circuito de Aplicação Completo

```
                     VIN = 5-20V (VBUS directo do CH224K)
                              │
              ┌───────────────┼──────────────────┐
              │               │                  │
             ═╧═             ═╧═                ═╧═
         C_VIN1          C_VIN2             C_HF
        22µF/25V        22µF/25V          100nF/50V
         (1210)          (1210)            (0402)
              │               │                  │
              └───────┬───────┴──────────────────┘
                      │
                      │   ┌──────────────────────────────────┐
                      │   │        SY8388ARHC (U12)          │
                      │   │        QFN-16 2.5×2.5mm          │
                      │   │                                  │
                      ├───┤ IN (2,3,4)            LX (8,9) ──┤──┐
                      │   │                                  │  │
                      │   │ EN (14) ◄── VIN (float = on)     │  │
                      │   │                                  │  │
                      │   │ SS (13) ── float (default)       │  │
                      │   │                                  │  │
                      │   │ BS (1) ──[C_BOOT 100nF]── LX     │  │
                      │   │                                  │  │
                      │   │ FB (12) ◄── divisor R_FB3/R_FB4    │  │
                      │   │                                  │  │
                      │   │ PG (10) ─○ (opcional)            │  │
                      │   │                                  │  │
                      │   │ PGND (5,6,7,PAD) ── GND          │  │
                      │   │                                  │  │
                      │   └──────────────────────────────────┘  │
                      │                                          │
                     GND                     ┌───────────────────┘
                                             │
                                             │  L2 (4.7µH)
                                            ═╪═ ~~~~~ ═╪═
                                             │         │
                                             │         ├─── VOUT (5V)
                                             │         │
                                   ┌────┴────┬────┬────┐
                                   │         │    │    │
                                  ═╧═       ═╧═  ═╧═  ═╧═
                               C_OUT5    C_OUT6 C_OUT7 C_OUT8
                              22µF/25V  22µF   22µF   22µF
                               (1210)   (1210) (1210) (1210)
                                   │         │    │    │
                                  GND       GND  GND  GND

  C_OUT (4× 22µF 25V em paralelo = 88µF total):
  ───────────────────────────────────────────────
  • Filtrar ripple de 600kHz → <20mV na saída
  • Resposta transitória: fornecem corrente instantânea quando o
    painel HUB75 muda de linha (picos 0→2A em µs), enquanto o
    loop de feedback do SY8388ARHC reage
  • 4 em paralelo → ESR total ~1mΩ (4× menor que 1 cap sozinho)
  • Sem capacitância suficiente → voltage sag → flickering/reset ESP32
```

### 4.6 Layout PCB

```
Regras de layout para SY8388ARHC:
═══════════════════════════════════

1. LOOP DE ALTA CORRENTE (minimizar):
   VIN → C_VIN → IC(IN→LX) → L2 → C_OUT → GND
   C_HF (100nF) junto a IN e PGND para HF bypass

2. PLACEMENT:
   C_VIN + C_HF: Imediatamente junto aos pinos IN (2,3,4) e PGND (5,6,7)
   L2: Adjacente aos pinos LX (8,9), ≤2mm
   C_OUT: Distribuídos após L2
   C_BOOT: Entre pino BS (1) e LX (8)

3. GROUND:
   - Plano contínuo na layer inferior
   - 4-6 vias (0.3mm) no thermal pad, sem thermal relief
   - Minimizar impedância do return path

4. ⚠️ ZONE KEEPOUT SOB L2:
   - SEM copper pour (top NEM bottom) sob L2
   - SEM vias na zona sob L2
   - Evita correntes de eddy e acoplamento magnético

5. ⚠️ MINIMIZAR COBRE NO NÓ LX:
   - Trace curto e direto de LX ao pad do indutor
   - NÃO incluir LX em copper pour
   - Alta dV/dt → funciona como antena EMI se grande

6. THERMAL:
   - Copper pour em VIN, VOUT e GND para dissipação
   - Vias térmicas 0.3mm com espaçamento 1mm
   - Bottom layer copper pour para dissipação adicional
```

---

## 5. Proteção VBUS

### 5.1 TVS Diode D6 — Rail VBUS

O rail VBUS (até 20V) é protegido por TVS bidirecional:

| Parâmetro | Valor |
|---|---|
| Componente | SMBJ24CA |
| Vrwm | 24V (suporta 20V VBUS) |
| Vbr | 26.7V min |
| Vc (clamp @ 15.4A) | 38.9V |
| Ppk | 600W (pulso) |
| Package | SMB (DO-214AA) |
| LCSC | C19077558 |

### 5.2 TVS Diode D7 — Rail 5V (NOVO)

O rail 5V (exposto no header J2) é protegido por TVS bidirecional:

| Parâmetro | Valor | Notas |
|---|---|---|
| Componente | **SMBJ5.0CA** | Mesma família/footprint que D6 |
| **Vrwm** | **5.0V** | Não conduz a 5V nominal |
| **Vbr** | 5.25–6.50V | Margem sobre 5V |
| **Vc (clamp @ 30.4A)** | **9.2V** | Transientes ESD ns/µs |
| Ppk | 600W | |
| Package | **SMB (DO-214AA)** | Mesmo footprint que D6 — zero mudança KiCad |
| LCSC | Pesquisar "SMBJ5.0CA" | Verificar com parâmetros abaixo |

**Como pesquisar no LCSC — parâmetros por ordem de importância:**

1. **Vrwm (Reverse Stand-Off Voltage)** = **5.0V** — o mais importante. Deve ser ≥ 5V para não conduzir durante operação normal. Não usar < 5V.
2. **Package** = **SMB / DO-214AA** — mantém o mesmo footprint que D6 no KiCad
3. **Ppk** ≥ 400W — 600W preferido (mesmo que D6)
4. **Tipo** = CA (bidirecional) — indicado para rails DC

> **Vc (Clamping Voltage) não precisa de ser ≤ 5.5V.** Parece contra-intuitivo, mas é correcto: o TVS só actua durante transientes de nanosegundos — os ICs downstream (CH340C Vmax=5.5V, SN74AHCT245 Vmax=5.5V) suportam picos momentâneos muito acima do seu Vmax contínuo. A função do TVS é absorver a energia do surge, não limitar a tensão a 5.5V exactos. Para sobretensão sustentada, o OVP do SY8388ARHC (~5.75V) é a primeira linha de defesa.

**Ligação D7:**
```
Saída SY8388ARHC (5V rail)
        │
        ├──────────────────────── J2 (header +5V/GPIO)
        │
   [D7 SMBJ5.0CA]   ← paralelo, bidirecional (CA)
        │
       GND
```
Colocar D7 **junto ao J2**, no lado do rail 5V, para interceptar ESD antes de se propagar.

### 5.3 Três Camadas de Proteção

1. **F1 PTC (ASMD2920, 3A)** — série em VBUS, protecção overcurrent
2. **D6 TVS (SMBJ24CA, VBUS)** — clamp VBUS, ESD e surges
3. **D7 TVS (SMBJ5.0CA, 5V)** — clamp 5V rail exposto em J2

---

## 6. BOM da Power Supply

### 6.1 ICs

| Ref | Componente | Valor | LCSC | Tipo | Footprint |
|-----|---|---|---|---|---|
| U5 | CH224K (WCH) | PD 3.0 Sink | **C970725** | Extended | ESSOP-10-1EP |
| U1 | SY8388ARHC (Silergy) | Buck 8A 24V | **C5110279** | Extended | QFN-16-EP 2.5x2.5mm |

### 6.2 Indutor

| Ref | Componente | Valor | LCSC | Tipo | Footprint |
|-----|---|---|---|---|---|
| L2 | Bourns SRP1265A-4R7M | 4.7µH 16A | **C780205** | Extended | 12.5x6.5mm |

### 6.3 Condensadores

| Ref | Componente | Valor | LCSC | Tipo | Footprint |
|-----|---|---|---|---|---|
| C24, C25 | MLCC (VIN) | 22µF 25V | **C12891** | Basic | 1206 |
| C_OUT5-8 | MLCC (×4, VOUT) | 22µF 25V | **C12891** | Basic | 1206 |
| C_BOOT3 | MLCC (bootstrap) | 100nF 50V | **C307331** | Basic | 0402 |
| C_FIL1 | MLCC (HF bypass) | 100nF 50V | **C307331** | Basic | 0402 |
| C_FF2 | MLCC (feedforward) | 22pF 50V | **C1555** | Basic | 0402 |
| C14 | MLCC (CH224K VDD) | 1µF 50V | **C15849** | Basic | 0603 |
| C27 | MLCC (bypass) | 1µF 50V | **C15849** | Basic | 0603 |
| C26 | MLCC (VBUS filter) | 10µF 50V | **C13585** | Basic | 1206 |

### 6.4 Resistências

| Ref | Componente | Valor | LCSC | Tipo | Footprint |
|-----|---|---|---|---|---|
| R_FB3 | Feedback upper | 22kΩ 1% | **C31850** | Basic | 0603 |
| R_FB4 | Feedback lower | 3kΩ 1% | **C4211** | Basic | 0603 |
| R14 | VBUS→VDD CH224K | 1kΩ | **C4410** | Basic | 1206 |
| R_PU1 | PG pull-up | 10kΩ | **C25744** | Basic | 0402 |
| R_BASE1 | NPN base | 10kΩ | **C25744** | Basic | 0402 |
| R_ERR1 | Error LED | 330Ω | **C25104** | Basic | 0402 |
| R_DIV1 | VBUS divider upper | 47kΩ | **C25792** | Basic | 0402 |
| R_DIV2 | VBUS divider lower | 5.6kΩ | **C23189** | Basic | 0603 |
| R_VBUS1 | VBUS sense pull-down | 10kΩ | **C25744** | Basic | 0402 |

### 6.5 Díodos e TVS

| Ref | Componente | Valor | LCSC | Tipo | Footprint |
|-----|---|---|---|---|---|
| D6 | SMBJ24CA (TVS bidirecional) | Vrwm=24V, 600W | **C19077558** | Extended | SMB (DO-214AA) |
| D7 | SMBJ5.0CA (TVS 5V rail) | Vrwm=5V, 600W | Pesquisar LCSC | Extended | SMB (DO-214AA) |
| D1 | LED Vermelho (Error) | — | **C2286** | Basic | 0603 |

### 6.6 Outros

| Ref | Componente | Valor | LCSC | Tipo | Footprint |
|-----|---|---|---|---|---|
| F1 | PTC Fuse | 3A 30V | **C2982291** | Extended | 2920 |
| Q2 | MMBT2222A | NPN transistor | **C8512** | Basic | SOT-23 |

### 6.7 Resumo de Custos

| Bloco | Componentes | Custo estimado |
|---|---|---|
| PD Trigger (CH224K + passivos) | 5 | ~€0.45 |
| Buck (SY8388ARHC + L2 + caps + FB) | 11 | ~€0.95 |
| Proteção (TVS + PTC) | 2 | ~€0.10 |
| Error LED (NPN + R + LED) | 3 | ~€0.05 |
| **Total PSU** | **~22** | **~€1.70** |

### 6.8 Componentes Extended (taxa JLCPCB)

| Componente | Taxa |
|---|---|
| CH224K (C970725) | $3 |
| SY8388ARHC (C5110279) | $3 |
| L2 SRP1265A-4R7M (C780205) | $3 |
| D6 SMBJ24CA (C19077558) | $3 |
| F1 PTC (C2982291) | $3 |
| **Total taxa Extended PSU** | **$15** |

---

## 7. Alimentação CH224K — Detalhes

### 7.1 R1 1kΩ (VBUS → VDD)

O CH224K é alimentado através de R1 1kΩ de VBUS ao pin VDD.
O regulador interno (LDO série) gera 3.3V estável.

```
Cálculo a 20V:
  I_chip = ~5mA (típico)
  V_drop = 5mA × 1kΩ = 5V
  V_VDD  = 20V - 5V = 15V (entrada LDO, dentro de 4-22V ✓)
  P_R1   = 5mA × 5V = 25mW (0603 suporta 100mW ✓)
```

### 7.2 VBUS Pin (pin 8) — NC

O pino VBUS serve apenas para detectar tensão em protocolos legacy (BC1.2/QC).
Para USB PD puro via CC1/CC2, é desnecessário.

### 7.3 5V USB Pass-Through

Sem MOSFET no power path, um carregador USB 5V básico (Mac, etc.) fornece
5V directamente ao buck. O SY8388ARHC tem soft-start integrado e aceita VIN
desde 4.5V. Isto garante que o ESP32 pode ser flashado via USB sem fonte PD.

---

## 8. Análise Worst-Case — Bulletproof PSU

### 8.1 Tolerância de Saída (VOUT)

Com resistências FB de 1% e VFB ±1%:

```
Parâmetros:
  VFB  = 0.600V ±1% → [0.594V, 0.606V]
  R_FB3 = 22kΩ ±1% → [21.78kΩ, 22.22kΩ]
  R_FB4 = 3kΩ  ±1% → [2.97kΩ, 3.03kΩ]

Nominal:
  VOUT = 0.600 × (1 + 22k/3k) = 0.600 × 8.333 = 5.000V

Worst-case HIGH (VFB↑, R_FB3↑, R_FB4↓):
  VOUT = 0.606 × (1 + 22.22k/2.97k) = 0.606 × 8.485 = 5.142V (+2.8%)

Worst-case LOW (VFB↓, R_FB3↓, R_FB4↑):
  VOUT = 0.594 × (1 + 21.78k/3.03k) = 0.594 × 8.188 = 4.864V (-2.7%)

Resultado: VOUT ∈ [4.86V, 5.14V] (±2.8%)
═══════════════════════════════════════

  ✓ ESP32: opera 2.3-3.6V (via LDO 3.3V) — margem enorme
  ✓ HUB75: opera 4.2-5.5V típico — dentro de spec
  ✓ CH340C: opera 3.0-5.5V — OK
  ✓ SN74AHCT245: opera 4.5-5.5V — OK (4.86V > 4.5V mín)
```

### 8.2 Protecções SY8388ARHC (Datasheet)

| Protecção | Threshold | Comportamento |
|---|---|---|
| **UVLO (Under-Voltage)** | VIN < ~3.8V (rising ~4V) | Desliga, hysteresis ~0.3V |
| **OVP (Over-Voltage)** | VOUT > ~115% nominal | Latch-off (requer power cycle) |
| **OCP Peak** | ~17.5A typ (high-side) | Cycle-by-cycle current limit |
| **OCP Valley** | Configurável via ILMT pin | Float = 10A typ valley limit |
| **OTP (Over-Temp)** | ~160°C junction | Latch-off |
| **UVP (Under-Voltage Output)** | VOUT < ~70% nominal | Hiccup mode |
| **Soft-Start** | Interno, ~2ms | Limita inrush current |

### 8.3 Análise Térmica

```
Pior caso: 20V → 5V @ 8A (40W output, ~93% eficiência)

  P_input  = 40W / 0.93 = 43W
  P_loss   = 43W - 40W = 3W (total no IC + indutor)

  SY8388ARHC (QFN-16 2.5×2.5mm):
    RθJA ≈ 40°C/W (com thermal pad + vias)
    P_IC ≈ 1.5W (FET losses + driver + quiescent)
    ΔT = 1.5W × 40°C/W = 60°C
    Tj_max = 85°C (ambiente) + 60°C = 145°C (< 150°C limite) ⚠️ MARGEM BAIXA

  Recomendação: Garantir 4-6 vias térmicas 0.3mm no exposed pad
  e copper pour generoso em ambas as faces do PCB.

  L2 (SRP1265A-4R7M):
    P_L2 ≈ I²×DCR = 8²×0.0074 = 0.47W (DCR=7.4mΩ)
    ΔT ≈ 25°C (com airflow natural)
    ✓ Isat = 16A >> 8A — sem risco de saturação
```

### 8.4 Ripple de Saída

```
  f_sw = 600kHz
  L = 4.7µH (L2 — BUCK1 removido, só BUCK2 montado)
  VIN = 20V, VOUT = 5V, IOUT = 8A

  Duty cycle: D = VOUT/VIN = 5/20 = 0.25
  ΔI_L = (VIN - VOUT) × D / (f_sw × L)
       = (20 - 5) × 0.25 / (600k × 4.7µ)
       = 3.75 / 2.82 = 1.33A p-p

  Ripple voltage (ESR-dominated, 4×22µF em paralelo):
    ESR_total ≈ 3mΩ / 4 = 0.75mΩ
    V_ripple ≈ ΔI_L × ESR_total = 1.33 × 0.75m = 1.0mV

  Ripple voltage (capacitivo):
    V_ripple_cap = ΔI_L / (8 × f_sw × C_total)
                 = 1.33 / (8 × 600k × 88µ) = 3.1mV

  Total ripple ≈ √(1.0² + 3.1²) ≈ 3.3mV p-p ✓✓ (< 20mV target, excelente)
```

### 8.5 Capacitor Derating

```
  C_VIN (22µF 25V 1206):
    VIN_max = 20V → 80% rating → OK para MLCC X5R/X7R
    ⚠️ Capacitância efectiva a 20V DC bias ≈ 12-15µF (X5R perde ~35%)
    Com 2× em paralelo: ~24-30µF efectivo → suficiente

  C_OUT (22µF 25V 1206):
    VOUT = 5V → 20% rating → quase capacitância total mantida
    Com 4× em paralelo: ~80-85µF efectivo → excelente

  ✓ Output caps com margem de derating muito boa
  ⚠️ Input caps perdem capacitância a 20V — 2× em paralelo compensa
```

### 8.6 Margem de Protecção TVS (D6)

```
  SMBJ24CA specs:
    Vrwm  = 24V   ← VBUS normal 20V → 4V margem (83% derating) ✓
    Vbr   = 26.7V ← TVS não conduz a 20V nominal ✓
    Vc    = 38.9V ← Clamp voltage em surge
    Ppk   = 600W  ← Protecção robusta contra surges

  SY8388ARHC VIN_max = 24V
    ⚠️ Vc (38.9V) > VIN_max (24V) → Durante um surge forte,
    o IC pode ver até 38.9V momentaneamente antes do TVS clampar.
    PORÉM: surges são de µs/ns de duração. Os C_VIN absorvem a
    energia antes que o IC sofra dano.

  Conclusão: Proteção adequada para USB PD com 2 camadas:
    1. C_VIN (absorção µs) + 2. D6 TVS (clamp ns)
```

---

## 9. Alinhamento KiCad ↔ Documentação (v4.1)

Todas as referências, LCSC codes e footprints neste documento correspondem ao
esquemático KiCad (`psu.kicad_sch`), que é a **source of truth** (PCB encomendado na JLCPCB).

| Item | Correcção v4.1 | Status |
|---|---|---|
| SY8388ARHC Ref | ~~U12~~ → **U1** | ✅ Alinhado |
| TVS Ref | ~~D3~~ → **D6** | ✅ Alinhado |
| TVS Value | ~~SMBJ5.0A~~ → **SMBJ24CA** | ✅ Alinhado |
| Caps C_VIN/C_OUT | ~~C52306 (1210)~~ → **C12891 (1206)** | ✅ Alinhado |
| Q_NPN Ref + LCSC | ~~Q_NPN/C916372~~ → **Q2/C8512** | ✅ Alinhado |
| L2 (4.7µH) | Adicionado ao BOM (C780205) | ✅ Documentado |
| L1 (2.2µH) | **Removido** — BUCK1 eliminado (PFM noise). Só L2=4.7µH montado. | ✅ Resolvido |
| VBUS divider (R_DIV1/R_DIV2) | Adicionado ao BOM | ✅ Documentado |
| Cap refs | Alinhados com KiCad (C24/C25, C_BOOT3, C_FIL1, C_FF2, C14, C26, C27) | ✅ |
| Resistor refs | Alinhados com KiCad (R14, R_PU1, R_BASE1, R_ERR1) | ✅ |
| D3 (USB data TVS) | C20615788 (H7VN10B), footprint D_SOD-123 | ⚠️ **DNP** — protecção D+/D−, não montado nesta revisão |

---

## 10. Referências

- [CH224K Datasheet (WCH)](https://www.wch.cn/downloads/file/301.html)
- [CH224K LCSC](https://www.lcsc.com/product-detail/C970725.html)
- [SY8388ARHC Datasheet (Silergy)](https://datasheet.lcsc.com/lcsc/2207201830_Silergy-Corp-SY8388ARHC_C5110279.pdf)
- [SY8388ARHC JLCPCB](https://jlcpcb.com/partdetail/SilergyCorp-SY8388ARHC/C5110279)
- [Beyondlogic CH224 Review](https://www.beyondlogic.org/review-usb-c-power-delivery-trigger-board-ch224/)

---

*Documento criado: Março 2026*
*Versão: 4.1 — Bulletproof CH224K + SY8388ARHC*
*Substitui: POWER_SUPPLY.md (v1), POWER_SUPPLY_v2.md, POWER_SUPPLY_v3.md, PSU_20V_SCHEMA_DESIGN.md*

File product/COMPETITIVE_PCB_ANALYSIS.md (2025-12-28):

# Competitive PCB Analysis - HUB75 Interface Controllers

## Sumário Executivo

Este documento analisa os principais projetos de PCB open-source para interface com painéis LED HUB75, comparando abordagens de design e identificando lacunas para a solução Proto Circadian Clock.

---

## 1. ESP32-Trinity (Brian Lough / WitnessMeNow)

**Repositório:** [github.com/witnessmenow/ESP32-Trinity](https://github.com/witnessmenow/ESP32-Trinity)

### 1.1 Visão Geral

O ESP32-Trinity é uma placa open-source certificada (OSHW) projetada especificamente para controlar painéis HUB75. É atualmente o projeto mais popular e bem documentado neste espaço.

### 1.2 Características Técnicas

| Aspecto | Implementação |
|---|---|
| **MCU** | ESP32-WROOM (soldado na placa) |
| **Level Shifters** | **NÃO INCLUÍDOS** - ligação direta 3.3V |
| **Alimentação** | Barrel jack 5.5x2.1mm + USB-C |
| **Proteção Inversão** | Limitada (poly fuse interno USB) |
| **Proteção ESD** | Não especificada |
| **Proteção Sobretensão** | Não especificada |
| **Conector HUB75** | Header 2x8 standard |
| **Painéis Testados** | 64x32 P3, 64x64 P3 |
| **Software** | ESP32-HUB75-MatrixPanel-I2S-DMA |

### 1.3 Design de Alimentação

```
USB-C ──[Poly Fuse interno]──┬── 5V para ESP32
                             │
Barrel Jack 5V ──────────────┴── 5V para Painel HUB75
```

**Recomendação:** Fonte 5V 8A "laptop style" para cobrir cenários de iluminação máxima.

### 1.4 Ficheiros de Design (V1.2)

- BOM CSV (Bill of Materials)
- Schematic PDF/PNG
- Gerber files
- Interactive BOM (HTML)
- EasyEDA project backup
- Pick-and-Place files (PNP)

### 1.5 Pontos Fortes

- Open Source Hardware certificado
- Comunidade ativa (Discord, GitHub)
- Documentação extensa com exemplos
- Vem totalmente montado e testado
- Preço acessível (~$15-20 via Makerfabs)
- Compatível com biblioteca ESP32-HUB75-MatrixPanel-DMA

### 1.6 Limitações Identificadas

| Limitação | Impacto | Risco |
|---|---|---|
| **Sem level shifters** | Sinal 3.3V pode ser marginal para alguns painéis | Médio |
| **Proteções básicas** | Vulnerável a picos, inversão de polaridade | Alto |
| **Sem ESD protection** | Descargas podem danificar GPIO | Médio |
| **Sem RTC integrado** | Requer módulo externo para funcionamento offline | Baixo |
| **Sem sensor de luz** | Não ajusta brilho automaticamente | Baixo |

### 1.7 Gap para Proto Circadian Clock

```diff
- Level shifters 3.3V → 5V (74AHCT245)
- Proteção inversão polaridade (Schottky/P-MOSFET)
- Proteção curto-circuito (PTC fuse)
- Proteção ESD (SRV05-4, PESD5V0S1BA)
- Proteção sobretensão (TVS SMBJ5.0A)
- RTC DS3231 integrado com bateria CR2032
- Sensor de luz ambiente (opcional)
```

---

## 2. Adafruit MatrixPortal S3

**Repositório:** [github.com/adafruit/Adafruit-MatrixPortal-S3-PCB](https://github.com/adafruit/Adafruit-MatrixPortal-S3-PCB)

### 2.1 Visão Geral

Solução comercial de alta qualidade da Adafruit, usando o ESP32-S3 mais recente. Representa o "estado da arte" em termos de design profissional para interfaces HUB75.

### 2.2 Características Técnicas

| Aspecto | Implementação |
|---|---|
| **MCU** | ESP32-S3 (8MB Flash, 2MB SRAM) |
| **Level Shifters** | **2x 74AHCT125** (3.3V → 5V) |
| **Alimentação** | USB-C + terminais parafuso M3 |
| **Acelerómetro** | LIS3DH integrado |
| **Sensor Luz** | Previsto no schematic (ALS-PT19), não incluído |
| **LED RGB** | NeoPixel integrado para status |
| **Botões** | 2 botões dedicados |
| **GPIO Breakout** | 6 GPIO + Reset + Boot + TX debug |
| **Analog Inputs** | 4 entradas analógicas (PWM/SPI/I2S) |

### 2.3 Level Shifter Design

```
ESP32-S3 (3.3V) ──► 74AHCT125 ──► HUB75 (5V)
                    (2 ICs)
```

**Nota Importante:** O MatrixPortal S3 usa **74AHCT125** (quad buffer) em vez de **74AHCT245** (octal transceiver). Ambos funcionam para level shifting unidirecional.

| IC | Canais | Vantagem |
|----|---|---|
| 74AHCT125 | 4 | Menor, independentes |
| 74AHCT245 | 8 | Menos ICs necessários |

### 2.4 Conectores HUB75

- Socket 2x10 que encaixa em portas HUB75 2x8
- Conector IDC 2x8 adicional para cabo ribbon
- Compatível com painéis 16x32 até 64x64
- **Address E line jumper** para painéis 64x64 (default: GPIO8)

### 2.5 Design de Alimentação

```
USB-C ──────────────┬── 5V + Dados (programação)
                    │
                    ├── LED verde (indicador 3.3V)
                    │
                    └── LED verde (indicador 5V)

Terminais M3 ───────┬── 5V entrada separada (painéis grandes)
                    │
                    └── GND
```

### 2.6 Ficheiros de Design

- Adafruit MatrixPortal S3.brd (EagleCAD layout)
- Adafruit MatrixPortal S3.sch (schematic)
- PrettyPins PDF/SVG (pinout diagrams)

### 2.7 Pontos Fortes

- **ESP32-S3 dual-core** (WiFi + display em paralelo)
- **Level shifters integrados** (compatibilidade garantida)
- **Acelerómetro LIS3DH** (orientação, tap detection)
- USB nativo (HID keyboard/mouse/MIDI)
- Qualidade comercial Adafruit
- Suporte CircuitPython + Arduino
- STEMMA QT (I2C) + JST analog

### 2.8 Limitações Identificadas

| Limitação | Impacto | Notas |
|---|---|---|
| **Preço elevado** | ~$25 USD só a placa | Sem painel |
| **Sem RTC** | Depende de NTP | Precisa internet |
| **Sem proteções robustas** | Apenas poly fuses | Sem TVS/ESD explícito |
| **Sensor luz removido** | ALS-PT19 no schematic mas não montado | |
| **Sem DAC** | Requer I2S para áudio | |

### 2.9 Gap para Proto Circadian Clock

```diff
+ Level shifters já incluídos (74AHCT125)
+ Acelerómetro pode ser útil (wake on movement)
+ ESP32-S3 mais potente
- RTC DS3231 com bateria backup
- Proteção inversão polaridade
- Proteção ESD robusta
- Proteção sobretensão (TVS)
- Sensor de luz ambiente funcional
```

---

## 3. ESP32-HUB75-Driver (Rorosaurus)

**Repositório:** [github.com/rorosaurus/esp32-hub75-driver](https://github.com/rorosaurus/esp32-hub75-driver)

### 3.1 Visão Geral

Design minimalista e de baixo custo. Filosofia "faça você mesmo" com PCB simples que apenas conecta os pinos necessários.

### 3.2 Características Técnicas

| Aspecto | Implementação |
|---|---|
| **MCU** | ESP32-DEVKIT-V1 (módulo separado) |
| **Level Shifters** | **NÃO INCLUÍDOS** |
| **Latch IC Externo** | **NÃO INCLUÍDO** |
| **Alimentação** | Screw terminals opcionais (5V) |
| **Proteção** | Nenhuma |
| **Componentes** | ~46 pontos de solda |
| **Design Tool** | EasyEDA |

### 3.3 Filosofia de Design

```
MINIMALISMO EXTREMO:
━━━━━━━━━━━━━━━━━━━━

ESP32-DEVKIT-V1
      │
      └──[16 fios diretos]──► HUB75 Panel

Sem level shifters: "most panels work at 3.3V tolerant"
Sem latch IC: "uses more pins and memory"
```

### 3.4 Capacitores Opcionais

| Componente | Valor | Função |
|---|---|---|
| Cerâmico SMD | 10µF (1206) | Auto-bootloader |
| Eletrolítico THT | 1000µF | Power smoothing 5V |

### 3.5 Pontos Fortes

- Custo mínimo (~$2-3 PCB)
- Gerbers disponíveis para fabrico direto
- Suporta daisy-chain de múltiplos painéis (testado com 5!)
- Compatível com 1/8, 1/16, 1/32 scan panels
- Design simples de entender e modificar
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

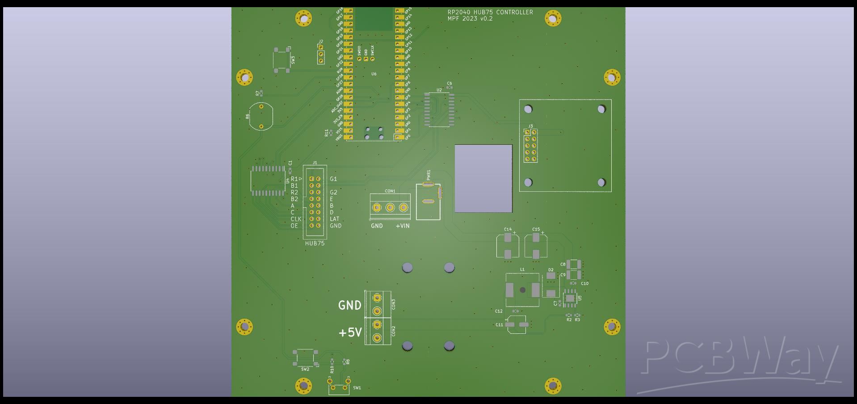
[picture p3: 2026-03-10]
product/hub75 footprint.jpg

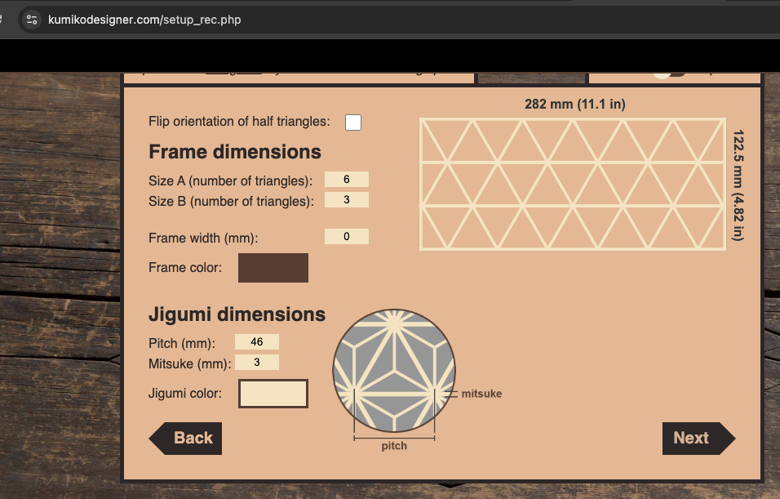
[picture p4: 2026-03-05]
product/kumiko panel configuration.png

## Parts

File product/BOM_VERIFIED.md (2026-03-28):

# BOM Verificado - Circadian Clock PCB

**Data:** Janeiro 2026
**Versão:** 4.1 - Componentes Alinhados com KiCad + PSU Bulletproof
**Fonte:** JLCPCB BOM Detection + Verificação Manual
**Total:** 24 componentes

---

## Histórico de Alterações

| Versão | Data | Alterações |
|---|---|---|
| 4.1 | Mar 2026 | **Alinhamento KiCad**: Remover componentes PSU obsoletos, alinhar refs/LCSC com KiCad. PSU v4.1 Bulletproof. |
| 3.0 | Jan 2026 | Substituição de Extended por Basic: D1→MMBD4148SE, R6→1206, U1→PCF8563T, U6→AMS1117, U2/U7→SN74AHCT245PWR |
| 2.0 | Jan 2026 | Análise completa Basic vs Extended |
| 1.0 | Jan 2026 | BOM inicial |

---

## Otimização de Custos: Basic vs Extended

### Porque Importa?

Na produção PCBA via JLCPCB, os componentes dividem-se em duas categorias fundamentais:

| Tipo | Taxa de Carregamento | Descrição |
|---|---|---|
| **Basic** | **$0** | Componentes comuns já montados nas máquinas P&P |
| **Preferred Extended** | **$0** | Extended mas isentos de taxa no Economic PCBA |
| **Extended** | **$3 por tipo único** | Requerem carregamento manual de feeders |

### Impacto Financeiro

Considerando que temos **~10 componentes Extended** no BOM atual:

```
Custo adicional Extended = 10 × $3 = $30 por encomenda
```

Este custo é **fixo por lote**, independentemente da quantidade de PCBs. Numa encomenda de 5 protótipos, são **$6 extra por placa** só em taxas de carregamento!

### Estratégia de Otimização

1. **Substituir Extended por Basic** sempre que possível
2. **Aceitar Extended inevitáveis** (ESP32, RTC, USB-C) - são críticos
3. **Avaliar alternativas** com mesmo footprint quando viável
4. **Usar Preferred Extended** - isentos de taxa no Economic PCBA

### Componentes Extended Inevitáveis

Alguns componentes não têm alternativa Basic viável:

| Componente | Razão |
|---|---|
| **ESP32-WROOM-32E** (U3) | MCU principal, sem alternativa |
| **CH340C** (U4) | USB-Serial necessário |
| **CH224K** (U5) | PD Sink — ver secção PSU |
| **SY8388ARHC** (U1) | Buck converter — ver secção PSU |

### Substituições já Aplicadas (v4.1)

| Anterior (Extended) | Atual | Economia | Nota |
|---|---|---|---|
| DS3231SN → **PCF8563T** (U6) | Preferred + Cristal Basic | **~$5** | ✅ Aplicado |
| ME6211 → **AMS1117-3.3** (U8) | Basic (SOT-223) | **$3** | ✅ Aplicado |
| IP2721 → **CH224K** (U5) | Extended mas mais barato | **$0.13** | ✅ Aplicado (PSU v4.1) |
| UMH3N → **MMBT2222A** (Q1) | Basic | **$3** | ✅ Aplicado |
| R3,R4 (5.1kΩ CC) | **Removidos** (CH224K Rd interno) | **-2 componentes** | ✅ Aplicado |

---

## Verificação de Substituições v3.0

### D1: 1N4148 → MMBD4148SE ✅ APROVADO

| Parâmetro | 1N4148 (Original) | MMBD4148SE (Novo) | Compatível? |
|---|---|---|---|
| **LCSC** | C84410 | **C17179590** | - |
| **Package** | DO-35 (THT) | **SOT-23 (SMD)** | Novo footprint |
| **Vrrm** | 100V | 100V | ✅ |
| **If(av)** | 300mA | 200mA | ✅ (suficiente) |
| **Vf** | ~0.65V | 1V max @ 10mA | ✅ |
| **trr** | 4ns | 4ns | ✅ |
| **Tipo** | Basic | Basic | ✅ |

**Nota:** MMBD4148SE é a versão SMD oficial da família 1N4148. Equivalência elétrica confirmada.

### D3: TVS para linhas D+/D− ⚠️ DNP (reservado, não montado)

| Parâmetro | C20615788 (H7VN10B) | Notas |
|---|---|---|
| **LCSC** | C20615788 | ✅ |
| **Fabricante** | hongjiacheng | |
| **Package** | DFN1006-2L | Compacto |
| **Vrwm** | ~7.5V | ✅ adequado para D+/D− (0–3.3V) |
| **Vbr** | 9V | |
| **Vc (clamp)** | 9.6V | |
| **Ipp** | 6A @ 8/20µs | |
| **Ppk** | 80W | |
| **ESD** | IEC 61000-4-2 | ✅ |
| **Tipo** | Extended | +$3 quando montado |

**Função:** Protecção ESD nas linhas USB D+ e D−. Um TVS por linha, em paralelo entre a linha e GND.

**Estado: DNP — não montado nesta revisão.** O footprint está reservado no PCB para instalação futura caso seja necessária protecção ESD nas linhas de dados USB.

> ⚠️ **Não confundir com D6 (SMBJ24CA):** D3 é para D+/D− (Vrwm~7.5V, linhas de sinal 3.3V). D6 é para VBUS (Vrwm=24V, rail de potência até 20V). Um **não** substitui o outro.

### D7: TVS para rail 5V ✅ NOVO (substitui C20615801 H3V3HD3U)

| Parâmetro | C20615801 H3V3HD3U (descartado) | SMBJ5.0CA (novo D7) | Notas |
|---|---|---|---|
| **Vrwm** | 3.3V ❌ (conduziria em 5V) | **5.0V** ✅ | Não conduz a 5V nominal |
| **Vbr** | ~3.5V | 5.25–6.50V | |
| **Vc (clamp)** | ~5V | 9.2V @ 30.4A | Transientes ns/µs |
| **Ppk** | 80W | **600W** | 7.5× mais robusto |
| **Package** | DFN1006-2L | **SMB (DO-214AA)** | Mesmo footprint que D6! |
| **Tipo** | — | Extended | +$3 (partilha feeder com D6) |

**Função:** Protecção ESD/surge no rail 5V exposto no header J2 (GPIO +5V). Liga em paralelo entre o rail 5V e GND, junto ao conector J2.

**Porquê descartado o H3V3HD3U (C20615801):**
- Vrwm=3.3V → conduziria continuamente num rail de 5V → destruído imediatamente
- Sem local adequado no design actual para 3.3V exposto externamente

**Porquê SMBJ5.0CA:**
- Mesma família e footprint que D6 (SMBJ24CA) → zero mudança de footprint no KiCad
- Vrwm=5.0V → não conduz durante operação normal a 5V
- 600W de capacidade de absorção de surges
- Protege CH340C (Vmax=5.5V), SN74AHCT245 (Vmax=5.5V) contra ESD via J2

**Ligação:**
```
5V rail (saída SY8388ARHC)
     │
     ├──────────────────────── J2 (header +5V/GPIO)
     │
 [D7 SMBJ5.0CA]   ← em paralelo, bidirecional (CA)
     │
    GND
```

**LCSC:** Pesquisar "SMBJ5.0CA" em lcsc.com — mesma família que D6 (SMBJ24CA C19077558).

> ⚠️ **Nota de clamping:** Vc=9.2V excede Vmax=5.5V de CH340C e SN74AHCT245. Isto é normal — o TVS actua em transientes de ns; a energia ESD é absorvida pelo TVS antes de danificar os ICs. Para protecção de sobretensão sustentada, o OVP do SY8388ARHC (~5.75V) é a primeira linha de defesa.

### R6: 1kΩ 0402 → 1kΩ 1206 ✅ APROVADO

| Parâmetro | Original | Novo | Status |
|---|---|---|---|
| **LCSC** | C106235 | **C4410** | ✅ |
| **Package** | 0402 | **1206** | Novo footprint |
| **Potência** | 63mW | 250mW | ✅ Melhor |
| **Tolerância** | ±1% | ±1% | ✅ |
| **Tipo** | Basic | **Basic** | ✅ |

### U1: DS3231SN → PCF8563T ✅ APROVADO

| Parâmetro | DS3231SN (Original) | PCF8563T (Novo) | Status |
|---|---|---|---|
| **LCSC** | C722469 | **C7440** | ✅ |
| **Package** | SOIC-16W | **SOIC-8** | Novo footprint |
| **Interface** | I2C | I2C | ✅ |
| **Cristal** | Integrado (TCXO) | **Externo C32346** | +1 componente |
| **Precisão** | ±2ppm | ±20ppm | Aceitável |
| **Preço** | ~$2.37 | ~$0.30 + $0.15 | ✅ Muito melhor |
| **Tipo** | Extended ($3) | **Preferred ($0)** | ✅ |

**Cristal necessário:** 32.768kHz (C32346) - **Basic** ($0 taxa)

### U2, U7: Level Shifter ✅ APROVADO

| Parâmetro | KiCad (Footprint) | BOM Real | Status |
|---|---|---|---|
| **Componente** | SN74LVC245APW | **SN74AHCT245PWR** | ✅ Pin-compatible |
| **LCSC** | - | **C10910** | ✅ |
| **Família** | LVC | **AHCT** | ✅ AHCT é o pretendido |
| **Package** | TSSOP-20 | TSSOP-20 | ✅ Mesmo footprint |
| **Pinout** | Standard 74x245 | Standard 74x245 | ✅ Idêntico |

**Nota:** No KiCad usa-se SN74LVC245APW apenas por conveniência (footprint disponível).
O componente real a encomendar é o **SN74AHCT245PWR (C10910)** - 100% pin-compatible.

**Porquê AHCT?**
- Ideal para **level shifting ESP32 (3.3V) → LED Matrix (5V)**
- Inputs TTL-compatible reconhecem 3.3V como HIGH
- Mesmo chip usado no **Adafruit MatrixPortal S3**
- Opera a 5V no lado da matriz LED

### U6: ME6211 → AMS1117-3.3 ✅ APROVADO

| Parâmetro | ME6211 (Original) | AMS1117-3.3 (Novo) | Status |
|---|---|---|---|
| **LCSC** | C82942 | **C6186** | ✅ |
| **Package** | SOT-23-5 | **SOT-223** | Novo footprint |
| **Vout** | 3.3V | 3.3V | ✅ |
| **Iout** | 600mA | 1A | ✅ Melhor |
| **Dropout** | 120mV | 1.1V | ⚠️ Maior |
| **Iq** | 60µA | 5mA | ⚠️ Maior |
| **Tipo** | Extended | **Basic** | ✅ |

**Nota:** AMS1117 é o LDO standard dos ESP32 DevKit. Dropout maior mas aceitável com USB 5V input.

### D4: Battery Backup Diode ✅ NOVO

| Parâmetro | Valor | Status |
|---|---|---|
| **Componente** | MMBD4148SE | ✅ |
| **LCSC** | C17179590 | ✅ (mesmo que D1) |
| **Package** | SOT-23 | ✅ |
| **Função** | OR díodo para backup RTC | ✅ |
| **Tipo** | Basic | ✅ |

**Circuito:** VDD (3.3V) e BT1+ ligam ao VDD do PCF8563T, com D4 no caminho da bateria.
Quando USB desliga, bateria alimenta RTC através de D4 (~2.3V após drop).

---

## Análise de Classificação por Componente

### Legenda
- **Basic** = Sem taxa adicional (já nas máquinas P&P)
- **Preferred** = Extended mas **sem taxa** no Economic PCBA (ex-Basic, agora carregado manualmente)
- **Extended** = +$3 taxa de carregamento por tipo único

---

## Problemas Críticos Detetados

| Ref | Problema | Ação Necessária |
|-----|---|---|
| **C3** | Footprint 0805, componente é 1206 | Mudar footprint para `C_1206_3216Metric` |
| **D2** | Footprint 0402, componente é 0603 | Mudar footprint para `LED_0603_1608Metric` |
| **J1** | LCSC errado (Hanxia genérico) | Mudar para **C3020560** (GCT USB4105-GF-A) |

> BZ1 Resolvido: Substituído GPC12075YB-5V (C252948, fora de stock) por TMB12A05 (C96093) - mesmo footprint Ø12mm, pitch 7.6mm

---

## Lista Completa de Componentes

### Microcontrolador

| Ref | Componente | LCSC | Tipo | Alternativa Basic | Nota |
|-----|---|---|---|---|---|
| U3 | ESP32-WROOM-32E-N8 | **C701342** | Extended | - | MCU principal, sem alternativa |

**Custo Extended:** +$3

### ICs

| Ref | Componente | LCSC | Tipo | Nota |
|-----|---|---|---|---|
| U4 | CH340C | **C84681** | Extended | USB-Serial |
| U8 | AMS1117-3.3 (LDO) | **C6186** | Basic | SOT-223, 3.3V regulador |

**Custo Extended:** +$3

> **U5** (anteriormente D3V3XA4B10LP-7 ESD) → Substituído por **CH224K** (PD Sink). Ver secção PSU.

### Transistores

| Ref | Componente | LCSC | Tipo | Nota |
|-----|---|---|---|---|
| Q1 | MMBT2222A | **C8512** | Basic | Buzzer driver (sound.kicad_sch) |
| Q4 | MMBT2222A | **C8512** | Basic | UART DTR (uart.kicad_sch) |
| Q5 | MMBT2222A | **C8512** | Basic | UART RTS (uart.kicad_sch) |

**Custo Extended:** $0 — Todos Basic!

> **Q2** (MMBT2222A, Error LED NPN) → Ver secção PSU.
> **Q1** alterado: UMH3N (C62892) → **MMBT2222A (C8512)** — simplificação do driver do buzzer.

### Díodos e LEDs

| Ref | Componente | LCSC | Tipo | Nota |
|-----|---|---|---|---|
| D2 | KT-0603R (LED Wifi Status) | **C2286** | Basic | clockv7.kicad_sch |
| D4 | MMBD4148SE (RTC backup) | **C17179590** | Basic | RTC.kicad_sch |
| D5 | MMBD4148SE (buzzer flyback) | **C17179590** | Basic | sound.kicad_sch |
| D7 | SMBJ5.0CA (TVS 5V rail) | Pesquisar LCSC | Extended | PSU — junto a J2 |

**Custo Extended:** $0 — Todos Basic!

> **D1** (anteriormente 1N4148TR) → Agora **LED_ERR** (C2286). Ver secção PSU.
> **D3** (anteriormente SMF9.0CA) → Agora **H7VN10B** (C20615788, USB data TVS). Ver secção PSU.
> **D6** (SMBJ24CA, VBUS TVS 24V) → Ver secção PSU.

### Condensadores (Não-PSU)

| Ref | Componente | LCSC | Tipo | Nota |
|-----|---|---|---|---|
| C2 | 10µF 0603 | **C19702** | Basic | ESP32 bypass (clockv7) |
| C3 | 22µF 1206 | **C12891** | Basic | LDO output (clockv7) |
| C4,C6,C8,C11,C12,C13,C18,C19 | 100nF 0402 | **C307331** | Basic | Bypass caps (vários) |
| C5 | 22µF | **C59461** | Basic | Level shifter (clockv7) |

**Custo Extended:** $0 — Todos Basic!

> Condensadores PSU (C24, C25, C_OUT5-8, C_BOOT3, C_FIL1, C_FF2, C14, C26, C27) → Ver secção PSU.

### Resistências

| Ref | Componente | LCSC | Tipo | Nota |
|-----|---|---|---|---|
| R1 | 330Ω 0402 | **C25104** | Basic | LED D2 (clockv7) |
| R2 | 100Ω 0402 | **C25076** | Basic | USB (clockv7) |
| R5 | 10kΩ 0402 | **C25744** | Basic | ESP32 pull-up (clockv7) |
| R6 | 1kΩ 1206 | **C4410** | Basic | Buzzer (sound) |
| R10 | 10kΩ 0402 | **C25744** | Basic | UART DTR (uart) |
| R11 | 10kΩ 0402 | **C25744** | Basic | UART RTS (uart) |

**Custo Extended:** $0 — Todos Basic!

> **R3,R4** (5.1kΩ CC pull-downs) → **REMOVIDOS**. CH224K tem Rd internos 5.1kΩ.
> Resistências PSU (R14, R_FB3, R_FB4, R_PU1, R_BASE1, R_ERR1, R_DIV1, R_DIV2, R_VBUS1) → Ver secção PSU.

### Fusível

> **F1** (anteriormente SMD1206P050TF/15 500mA) → Substituído por **ASMD2920-300-30V 3A** (C2982291). Ver secção PSU.

### Conectores

| Ref | Componente | LCSC | Tipo | Nota |
|-----|---|---|---|---|
| J2 | 2.54-2*8P Header (GPIO +5V) | **C30734** | Basic | clockv7.kicad_sch |

**Custo Extended:** $0

> **USBC1** (TYPE-C-31-M-12, C165948) → Ver secção PSU.
> Conectores PSU adicionais (J3, J4, J7, P1, CN1) → Ver secção PSU / KiCad.

### Amplificador I2S (DNP — reservado para clockv8)

| Ref | Componente | LCSC | Tipo | Nota |
|-----|---|---|---|---|
| U9 | MAX98357AEWL+T | **C2682619** | Extended | **DNP** — footprint reservado para clockv8; não montar, não conta no BOM |

**Footprint:** `Maxim_WLP-9_1.595x1.415_Layout3x3_P0.4mm_Ball0.27mm_Pad0.25mm_NSMD` (KiCad default)
**Estado:** DNP (`exclude_from_bom yes`, `dnp yes` no KiCad). Traces pré-roteadas IO32/IO33/IO2 + 3V3 + GND. Ver SPEAKER.md para pinout completo.

---

### Buzzer

| Ref | Componente | LCSC | Tipo | Alternativa Basic | Nota |
|-----|---|---|---|---|---|
| BZ1 | TMB12A05 | **C96093** | Extended | - | Sem alternativa Basic THT |

**Custo Extended:** +$3

### Botões

| Ref | Componente | LCSC | Tipo | Alternativa Basic | Nota |
|-----|---|---|---|---|---|
| SW1,SW2 | TS-1088-AR02016 | **C720477** | Extended | TS-1187A-B-A-B (C318884) | Verificar footprint |

**Custo Extended:** +$3

### RTC (Real-Time Clock)

| Ref | Componente | LCSC | Tipo | Alternativa Basic | Nota |
|-----|---|---|---|---|---|
| U2 | DS3231SN | **C722469** | Extended | **PCF8563T (C7563) - Preferred!** | Sem taxa, menor precisão, muito mais barato |
| R7,R8 | 4.7kΩ 0402 | **C25900** | Basic | - | Já é Basic |
| C9 | 100nF 0402 | **C307331** | Basic | - | Já é Basic |
| BT1 | CR2032 Holder | **C70377** | Extended | - | Sem alternativa |

**Custo Extended:** +$6

**Análise RTC:** O **PCF8563T (C7563)** é **Preferred Extended** + Cristal **C32346 é Basic** = SEM TAXAS!

| Característica | DS3231SN | PCF8563T + Cristal |
|---|---|---|
| Componente | ~$2.37 | ~$0.30 + $0.15 = **$0.45** |
| Cristal externo | Não precisa (TCXO) | **C32346** ($0.15, **Basic!**) |
| Precisão | ±2ppm (~1 min/ano) | ±20ppm (~10 min/ano) |
| Taxa JLCPCB | $3 (Extended) | **$0** (Preferred + Basic) |
| **Total/lote** | **$5.37** | **$0.45** |
| **Poupança** | - | **~$5/lote** |

**RECOMENDAÇÃO FORTE:**
- PCF8563T (Preferred) + Cristal C32346 (Basic) = **$0 de taxas!**
- Poupança: ~$5/lote = **$250 em 50 lotes**
- Único contra: footprint diferente (SOIC-8 vs SOIC-16W)

---

## Resumo de Custos Extended (v4.1 atualizado)

### Componentes Não-PSU Extended

| Categoria | Componentes Extended | Custo |
|---|---|---|
| Microcontrolador | ESP32 (U3) | $3 |
| ICs | CH340C (U4) | $3 |
| Buzzer | TMB12A05 (BZ1) | $3 |
| Botões | TS-1088 (SW1,SW2) | $3 |
| RTC | Battery Holder (BT1) | $3 |
| **Subtotal Não-PSU** | **5 tipos** | **$15** |

### Componentes PSU Extended

| Categoria | Componentes Extended | Custo |
|---|---|---|
| PSU | CH224K, SY8388ARHC, L2, D6 TVS, F1 PTC | $15 |

### **TOTAL Extended: 10 tipos = $30**

> **Poupanças já aplicadas vs v3.0:** DS3231→PCF8563 ($5), ME6211→AMS1117 ($3), UMH3N→MMBT2222A ($3), ESD IC removido ($3) = **~$14 poupados**

---

## Notas RTC (PCF8563T)

### Pinout SOIC-8
```
        ┌────────────┐
 OSCI  1│●           │8  VDD (3.3V)
 OSCO  2│  PCF8563T  │7  CLKOUT (NC)
  INT  3│            │6  SCL
  VSS  4│            │5  SDA
        └────────────┘
```

### Ligações
- **Pin 1 (OSCI)** ↔ **Pin 2 (OSCO)**: Cristal Y1 (C32346) - sem caps externos
- **Pin 3 (INT)**: Deixar NC (só usar para alarmes)
- **Pin 7 (CLKOUT)**: Deixar NC
- **Pin 5 (SDA)**: GPIO21 ESP32 + pull-up 4.7kΩ
- **Pin 6 (SCL)**: GPIO22 ESP32 + pull-up 4.7kΩ
- **Pin 8 (VDD)**: 3.3V + bypass 100nF + D4 para backup bateria

### Circuito Backup Bateria
```
VDD (3.3V) ─────────────────┬─── Pin 8 (VDD) PCF8563T
                            │
BT1+ (CR2032) ───►|─────────┘
                  D4
             (MMBD4148SE)

BT1- ─────────────────────────── Pin 4 (VSS/GND)
```

### Funcionamento D4
| Estado | Resultado |
|---|---|
| USB ON (VDD=3.3V) | D4 reverse bias → bateria não gasta |
| USB OFF (VDD=0V) | D4 forward → RTC recebe ~2.3V da bateria |

---

## Referência de Dimensões de Packages

| Package | Dimensões (mm) | Nome Métrico |
|---|---|---|
| 0201 | 0.6 x 0.3 | 0603 Metric |
| 0402 | 1.0 x 0.5 | 1005 Metric |
| 0603 | 1.6 x 0.8 | 1608 Metric |
| 0805 | 2.0 x 1.2 | 2012 Metric |
| 1206 | 3.2 x 1.6 | 3216 Metric |
| 1210 | 3.2 x 2.5 | 3225 Metric |
| 1812 | 4.5 x 3.2 | 4532 Metric |
| SOT-23 | 2.9 x 1.3 | - |
| SOT-23-5 | 2.9 x 1.6 | - |
| SOT-363 | 2.0 x 1.25 | SC-70-6 |
| SOD-123 | 2.7 x 1.2 | - |
| SMB | 5.3 x 3.6 | DO-214AA |

---

## Ações Necessárias no KiCad

### 1. Corrigir C3 (Condensador 22µF)
```
Footprint atual: C_0805_2012Metric (ERRADO)
Footprint correto: C_1206_3216Metric
```

### 2. Corrigir D2 (LED Vermelho)
```
Footprint atual: LED_0402_1005Metric_Red (ERRADO)
Footprint correto: LED_0603_1608Metric
```

### 3. Corrigir J1 (USB-C)
```
LCSC atual: C49261569 (Hanxia genérico - não corresponde ao footprint)
LCSC correto: C3020560 (GCT USB4105-GF-A)
```

---

## Resumo de Códigos LCSC - v4.1

```
# ══════════════════════════════════════
# COMPONENTES NÃO-PSU (clockv7 + uart + RTC + sound)
# ══════════════════════════════════════

# Microcontrolador
U3  = C701342   (ESP32-WROOM-32E-N8)     [Extended]

# ICs
U4  = C84681    (CH340C)                  [Extended]
U8  = C6186     (AMS1117-3.3) SOT-223    [Basic]

# Level Shifters (KiCad: SN74LVC245APW footprint, encomendar AHCT)
U2,U7 = C10910  (SN74AHCT245PWR)         [Extended]

# Transistores
Q1  = C8512     (MMBT2222A) — buzzer     [Basic]
Q4  = C8512     (MMBT2222A) — UART DTR   [Basic]
Q5  = C8512     (MMBT2222A) — UART RTS   [Basic]

# Díodos
D2  = C2286     (KT-0603R LED Wifi)      [Basic]
D4  = C17179590 (MMBD4148SE RTC backup)  [Basic]
D5  = C17179590 (MMBD4148SE buzzer)      [Basic]

# Condensadores
C2  = C19702    (10µF 0603)              [Basic]
C3  = C12891    (22µF 1206, LDO out)     [Basic]
C4,C6,C8,C11,C12,C13,C18,C19 = C307331 (100nF 0402) [Basic]
C5  = C59461    (22µF, level shifter)    [Basic]

# Resistências
R1  = C25104    (330Ω LED)               [Basic]
R2  = C25076    (100Ω USB)               [Basic]
R5  = C25744    (10kΩ ESP32)             [Basic]
R6  = C4410     (1kΩ 1206 buzzer)        [Basic]
R10 = C25744    (10kΩ UART DTR)          [Basic]
R11 = C25744    (10kΩ UART RTS)          [Basic]

# Conectores
J2  = C30734    (2x8 Header GPIO)        [Basic]

# Buzzer
BZ1 = C252948   (TMB12A05)               [Extended]

# I2S Amp — DNP (clockv8 placeholder, não montar, não conta no BOM)
# U9 = C2682619  (MAX98357AEWL+T)         [Extended] ← DNP

# Botões
SW1,SW2 = C720477 (TS-1088)              [Extended]

# RTC Module
U6  = C722469   (PCF8563T) SOIC-8        [Preferred]
Y1  = C32346    (32.768kHz Crystal)      [Basic]
R7,R8 = C25900  (4.7kΩ I2C pull-up)      [Basic]
C1  = C307331   (100nF RTC bypass)       [Basic]
C9  = C12891    (22µF RTC bulk)          [Basic]
BT1 = C70377    (CR2032 Holder)          [Extended]

# ══════════════════════════════════════
# COMPONENTES PSU — Ver secção PSU v4.1
# ══════════════════════════════════════
# U5  = C970725   (CH224K PD Sink)        [Extended]
# U1  = C5110279  (SY8388ARHC Buck 8A)    [Extended]
# USBC1 = C165948 (TYPE-C-31-M-12)        [Extended]
# D6  = C19077558 (SMBJ24CA TVS 24V)      [Extended]
# D3  = C20615788 (H7VN10B D+/D- TVS)     [Extended] ← DNP, não montado
# D7  = SMBJ5.0CA (TVS 5V rail)           [Extended] ← parallel 5V→GND, junto a J2
# D1  = C2286     (LED_ERR)               [Basic]
# F1  = C2982291  (PTC 3A 2920)           [Extended]
# L2  = C780205   (SRP1265A-4R7M 4.7µH)   [Extended]
# Q2  = C8512     (MMBT2222A Error LED)    [Basic]
# + Caps, resistors — ver POWER_SUPPLY.md secção 6
```

---

## Conclusão: Estado Atual (v4.1)

### Componentes Extended Finais (10 tipos = $30)

| # | Componente | Ref | Secção |
|---|---|-----|---|
| 1 | ESP32-WROOM-32E | U3 | Main |
| 2 | CH340C | U4 | UART |
| 3 | SN74AHCT245PWR ×2 | U2,U7 | Main |
| 4 | TMB12A05 (Buzzer) | BZ1 | Sound |
| 5 | TS-1088 (Botões) ×2 | SW1,SW2 | Main |
| 6 | CR2032 Holder | BT1 | RTC |
| 7 | CH224K (PD Sink) | U5 | PSU |
| 8 | SY8388ARHC (Buck) | U1 | PSU |
| 9 | SMBJ24CA (TVS VBUS) | D6 | PSU |
| 10 | ASMD2920 (PTC Fuse) | F1 | PSU |
| 11 | SMBJ5.0CA (TVS 5V) | D7 | PSU |

> **Nota:** L2 (indutor) é também Extended (+$3), totalizando **11 tipos = $33**. D3 (H7VN10B, TVS D+/D−) está **DNP** — não montado nesta revisão, não conta para a taxa Extended.

**Custo total estimado por lote de 5 PCBs:**
- Componentes: ~$15-20
- PCB: ~$5-10
- Assembly: ~$15-20
- Taxa Extended: ~$36 (12 tipos)
- **Total: ~$75-85** (ou ~$15-17 por placa)

---

## PSU Components (Secção PSU) — Design Final v4.1 (Bulletproof)

Componentes específicos da secção de alimentação. BOM detalhado em `POWER_SUPPLY.md`.

### PD Sink Controller - CH224K (substitui IP2721 + AO3404A MOSFET)

| Ref | Componente | LCSC | Tipo | Nota |
|-----|---|---|---|---|
| U5 | **CH224K** (WCH) - PD 3.0 Sink | **C970725** | Extended | ESSOP-10, pede 20V (CFG1 NC), PG pin, Rd interno |
| R14 | 1kΩ (VBUS→VDD) | C4410 | **Basic** | Alimentação CH224K |
| C14 | 1µF 50V (0603) | C15849 | **Basic** | Bypass VDD |

**Porquê CH224K em vez de IP2721 (C603176)?**
- IP2721 só suporta 3 tensões: 5V, 15V, 20V (sem 9V e 12V!)
- CH224K suporta **todas as 5 tensões PD**: 5V, 9V, 12V, 15V, 20V
- CH224K tem **PG (Power Good)** open-drain — LED de status hardware
- **Sem MOSFET externo** (Q3 removido) — VBUS liga directo ao buck
- **Rd internos 5.1kΩ** — não precisa R externas nos CC1/CC2
- Mais barato: ~$0.32 vs ~$0.40 (IP2721) + $0.03 (MOSFET) + $0.02 (R's)

### Buck Converter - SY8388ARHC (substitui TPS56838)

| Ref | Componente | LCSC | Tipo | Nota |
|-----|---|---|---|---|
| U1 | **SY8388ARHC** (Silergy) - Buck 8A | **C5110279** | Extended | QFN-16-EP 2.5×2.5mm, 24V in, 600kHz, compensação interna |
| L2 | Bourns SRP1265A-4R7M (4.7µH 16A) | C780205 | Extended | Shielded, Zone Keepout obrigatório! |
| C24,C25 | 22µF 25V MLCC (1206) | C12891 | **Basic** | Input caps |
| C_OUT5-8 | 22µF 25V MLCC ×4 (1206) | C12891 | **Basic** | Output caps (88µF total, baixo ESR) |
| C_BOOT3 | 100nF 50V (0402) | C307331 | **Basic** | Bootstrap |
| C_FIL1 | 100nF 50V (0402) | C307331 | **Basic** | HF bypass VIN→PGND |
| C_FF2 | 22pF 50V (0402) | C1555 | **Basic** | Feedforward (// R_FB3) |
| R_FB3 | 22kΩ 1% (0603) | C31850 | **Basic** | Feedback upper |
| R_FB4 | 3kΩ 1% (0603) | C4211 | **Basic** | Feedback lower |

**Porquê SY8388ARHC em vez de TPS56838 (C37533416)?**
- **Custo**: ~$0.53 vs ~$1.00+ (quase metade do preço!)
- **Sem coil whine**: PWM contínuo a 600kHz (vs SY8368 que fazia PFM a light load)
- **Compensação interna**: sem rede RC externa (simplifica layout)
- **QFN-16 compacto**: 2.5×2.5mm com thermal pad generoso
- 8A contínuo, 24V max — mesmas specs funcionais que TPS56838

### Proteção e Error LED

| Ref | Componente | LCSC | Tipo | Nota |
|-----|---|---|---|---|
| D6 | SMBJ24CA (TVS bidirecional) | C19077558 | Extended | Vrwm=24V, 600W pk, SMB pkg — proteção VBUS 20V |
| F1 | PTC Fuse 3A/30V | C2982291 | Extended | Protecção overcurrent |
| C26 | 10µF 50V (1206) | C13585 | **Basic** | Filtro entrada VBUS |
| Q2 | MMBT2222A (NPN) | C8512 | **Basic** | Inverter para Error LED |
| D1 | LED Vermelho 0603 | C2286 | **Basic** | Error LED (sem PD) |
| R_PU1 | 10kΩ (PG pull-up) | C25744 | **Basic** | Pull-up PG |
| R_BASE1 | 10kΩ (NPN base) | C25744 | **Basic** | Base NPN |
| R_ERR1 | 330Ω (LED) | C25104 | **Basic** | Corrente LED |

### Resumo Custos PSU

| Bloco | Taxa Extended | Nota |
|---|---|---|
| CH224K | $3 | PD Sink |
| SY8388ARHC | $3 | Buck |
| L2 (Bourns) | $3 | Indutor |
| D6 (TVS) | $3 | Proteção |
| F1 (PTC) | $3 | Fuse |
| **Total PSU Extended** | **$15** | 5 tipos Extended |

---

*Documento atualizado: Março 2026*
*Análise de custos Basic/Extended incluída*
*PSU v4.1 Bulletproof: CH224K (PD 20V) + SY8388ARHC (Buck 8A) — worst-case analysis, caps/TVS aligned with KiCad*

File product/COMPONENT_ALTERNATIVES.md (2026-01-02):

# Component Alternatives - JLCPCB Stock Issues

**Date:** January 2026
**Issue:** Several extended parts unavailable at JLCPCB SMT assembly

---

## Summary of Issues

| Ref | Original Part | LCSC | Status | Issue |
|-----|---|---|---|---|
| U1 | ESP32-WROOM-32E | C701342 | **Wrong variant** | N8 (8MB) not N4 (4MB) |
| BZ1 | CMT-7525-80-SMT-TR | C3151660 | Extended | 6 shortfall |
| D2 | YLED0805R | C19171391 | Extended | 20 shortfall |
| F1 | JK-NSMD050-13.2V | C369159 | Extended | 20 shortfall |
| J2 | AP2305GN-HF | C124516 | **BOM ERROR** | Wrong part type! |
| U6 | AP2112K-3.3TRG1 | C51118 | Extended | 7 shortfall |

---

## ⚠️ JLCPCB Assembly Type Note

**Standard PCBA Required** (not Economic) for ESP32-WROOM-32E module:
- Extra setup fee: **+$25 per side**
- Minimum board size: **70mm x 70mm** (edge rails added automatically)
- Reason: Package size constraints (0201 components, temperature requirements)

---

## 0. U1 - ESP32-WROOM-32E Module

### Original Issue
- **Part:** ESP32-WROOM-32E-N8 (8MB)
- **LCSC:** C701342
- **Problem:** Wrong variant (N8 = 8MB, need N4 = 4MB), 3D model misaligned

### Correct Part

| Part | LCSC | Flash | Stock | Notes |
|---|---|---|---|---|
| **ESP32-WROOM-32E-N4** | **C701341** | 4MB | Available | ✅ Correct version |
| ESP32-WROOM-32E-N4(4MB) | C7463334 | 4MB | Check | Alternative listing |

**Recommendation:** Use **C701341** - ESP32-WROOM-32E-N4 (4MB)

⚠️ **Requires Standard PCBA** - see note above

---

## 1. BZ1 - Buzzer

### Original
- **Part:** CMT-7525-80-SMT-TR (CUI Devices)
- **LCSC:** C3151660
- **Specs:** 7.5x7.5mm SMD, passive piezo, 80dB

### Recommended Alternatives

| Part | LCSC | Type | Size | SPL | Stock | Notes |
|---|---|---|---|-----|---|---|
| ~~MLT-5030~~ | ~~C95297~~ | Passive | 5.2x5.7mm | 80dB | ❌ OOS | Design guide spec - OUT OF STOCK |
| **HYG9605C** | **C438342** | Passive | 9.6x5mm | 85dB | Check | Louder, good alternative |
| **KLJ-1102** | **C201047** | Passive | 9x11mm | 70dB | Check | KELIKING |
| **GPC12075YB-5V** | **C252948** | Passive | 12mm | 80dB | Check | INGHAi, 4kHz resonance |
| FUET-1230 | C391037 | Passive | 12x12mm | 75dB | Check | 4kHz |
| PKM13EPYH4000 | C94599 | Passive | 13mm | 70dB | Extended | Murata, better high freq |

⚠️ **Do NOT use TMB12A05 (C96093)** - it's an ACTIVE buzzer (won't work with transistor+PWM driver)

**Recommendation:** Try **HYG9605C (C438342)** or **GPC12075YB-5V (C252948)** - passive buzzers, verify stock before ordering.

**Footprint Change:** Will vary - check datasheet for chosen part

---

## 2. D2 - Red LED (WiFi Status)

### Original
- **Part:** YLED0805R
- **LCSC:** C19171391
- **Specs:** 0805, Red, 615-630nm, 120mcd

### Recommended Alternatives

| Part | LCSC | Package | Color | Vf | mcd | Stock | Notes |
|---|---|---|---|-----|-----|---|---|
| **17-21SURC/S530-A3/TR8** | **C2286** | 0805 | Red | 2.0V | 150 | **Basic** | Standard, well-stocked |
| XL-1608URC | C965799 | 0603 | Red | 2.0V | 100 | Basic | Smaller option |
| 19-217/R6C-AL1M2VY/3T | C965804 | 0805 | Red | 2.0V | 110 | Basic | Everlight |
| KT-0805R | C2290 | 0805 | Red | 2.0V | 100 | Basic | KingTai |

**Recommendation:** Use **C2286** - JLCPCB basic part, high stock, same 0805 footprint.

**Footprint Change:** None required (same 0805 package)

---

## 3. F1 - PTC Resettable Fuse

### Original
- **Part:** JK-NSMD050-13.2V
- **LCSC:** C369159
- **Specs:** 1206 package, 500mA hold, 1A trip, 13.2V

### Design Note
The PCB_DESIGN_GUIDE.md specifies **MF-MSMF300** (3A hold, 6A trip, 1812 package) for main power protection. The 500mA fuse may be for a different application.

### Recommended Alternatives

**For 500mA (original spec):**

| Part | LCSC | Package | Hold | Trip | Voltage | Stock |
|---|---|---|---|---|---|---|
| **SMD1206P050TF/15** | **C106264** | 1206 | 500mA | 1A | 15V | Available |
| nSMD050-30V | C2836575 | 1206 | 500mA | 1A | 30V | Extended |

**For 3A (design guide spec):**

| Part | LCSC | Package | Hold | Trip | Voltage | Stock |
|---|---|---|---|---|---|---|
| **MF-MSMF250-2** | **C17313** | 1812 | 2.5A | 5A | 15V | Basic |
| SMD1812P200TF/16 | C106265 | 1812 | 2A | 4A | 16V | Available |
| nSMD300-8V | C262674 | 1812 | 3A | 6A | 8V | Extended |

**Recommendation:**
- If protecting USB 5V/3A rail: Use **MF-MSMF250-2 (C17313)** - 2.5A hold, 1812, basic part
- If original 500mA spec needed: Use **SMD1206P050TF/15 (C106264)**

**Footprint Change:** Check if 1206 or 1812 footprint is on PCB

---

## 4. J2 - 2x08 Pin Header (BOM ERROR!)

### Problem
The BOM lists **AP2305GN-HF (C124516)** which is a **P-channel MOSFET**, NOT a pin header!

This appears to be a BOM file error - wrong LCSC part number was assigned.

### Required Part
- **Type:** 2x8 (16-pin) pin header
- **Pitch:** 2.54mm
- **Mounting:** Through-hole vertical

### Correct Alternatives

| Part | LCSC | Pitch | Rows | Pins | Stock | Notes |
|---|---|---|---|---|---|---|
| **2.54-2*8P** | **C68234** | 2.54mm | 2 | 16 | Available | BOOMELE, gold pins, 3A rated |
| 2.54-2*8P H8.5mm | C124404 | 2.54mm | 2 | 16 | Available | Gold plated |
| PM2.54-2X8 | C65114 | 2.54mm | 2 | 16 | Available | Boom Precision |

**Recommendation:** Use **C68234** - standard 2x8 pin header from BOOMELE.

**Action Required:** Fix BOM file to replace C124516 with correct pin header part number!

---

## 4b. J2 (Alt) - Screw Terminal for Panel Power (BOM ERROR!)

### Problem
The design guide references **C430646** for a 2-pin screw terminal, but this is actually a **DORABO DB2ERC-7.62-5P-GN** (5-pin terminal, wrong pitch)!

### Required Part
- **Type:** 2-pin screw terminal block
- **Pitch:** 5.0mm or 5.08mm
- **Current:** 10A minimum (for LED panel power)
- **Mounting:** Through-hole

### Correct Alternatives

| Part | LCSC | Pitch | Pins | Current | Stock | Notes |
|---|---|---|---|---|---|---|
| **KF301-5.0-2P** | **C474881** | 5.0mm | 2 | 10A | Available | Cixi Kefa, standard |
| WJ301-5.0-2P | C8465 | 5.0mm | 2 | 10A | Check | Wanjie |
| MG301-5.0-2P | C8269 | 5.0mm | 2 | 10A | Check | DIBO |

**Recommendation:** Use **KF301-5.0-2P (C474881)** - standard 2-pin 5.0mm screw terminal.

**Action Required:** Fix PCB_DESIGN_GUIDE.md and POWER_SUPPLY_v2.md to replace C430646 with C474881!

---

## 5. U6 - AP2112K-3.3 LDO Regulator

### Original
- **Part:** AP2112K-3.3TRG1 (Diodes Inc)
- **LCSC:** C51118
- **Specs:** 3.3V 600mA LDO, SOT-23-5, 250mV dropout

### Note on Reference Designator
In PCB_DESIGN_GUIDE.md, the AP2112K-3.3 is designated as **U3**, not U6. U6 is the 74AHCT245 level shifter. Please verify the correct reference designator.

### Recommended Alternatives

| Part | LCSC | Package | Iout | Dropout | Iq | Stock | Notes |
|---|---|---|---|---|-----|---|---|
| **ME6211C33M5G-N** | **C82942** | SOT-23-5 | 500mA | 100mV | 40µA | **Basic** | Best stock |
| RT9013-33GB | C47773 | SOT-23-5 | 500mA | 200mV | 25µA | Basic | Low Iq |
| XC6220B331MR-G | C86534 | SOT-23-5 | 1A | 300mV | 8µA | Available | Better specs |
| HT7333-A | C21583 | SOT-89 | 250mA | 100mV | 4µA | Basic | Different package |
| AP2112K-3.3TRG1 | C460204 | SOT-23-5 | 600mA | 250mV | 55µA | Available | Same part, alt vendor |

**Recommendation:** Use **ME6211C33M5G-N (C82942)** - JLCPCB basic part, same pinout, adequate current.

**Alternative:** **XC6220B331MR-G (C86534)** - superior specs (1A, 8µA Iq) if extended parts acceptable.

**Footprint Change:** None required (same SOT-23-5 package)

---

## Quick Reference - Recommended Replacements

| Ref | Original LCSC | Replace With | New LCSC | Part Type |
|-----|---|---|---|---|
| U1 | C701342 ❌ | ESP32-WROOM-32E-N4 | **C701341** | Standard PCBA |
| BZ1 | C3151660 | HYG9605C (passive) | **C438342** | Check stock |
| D2 | C19171391 | 17-21SURC/S530-A3/TR8 | **C2286** | Basic |
| F1 | C369159 | SMD1206P050TF/15 | **C106264** | Available |
| J2 | C124516 ❌ | 2.54-2*8P Header | **C68234** | Available |
| J2 | C430646 ❌ | KF301-5.0-2P Screw Term | **C474881** | Available |
| U6 | C51118 | ME6211C33M5G-N | **C82942** | Basic |

---

## BOM Update Instructions

Update your BOM CSV file with these replacements:

```csv
# Original → Replacement
U1,C701342 → C701341  # ESP32: N8 (8MB) → N4 (4MB) - requires Standard PCBA!
BZ1,C3151660 → C438342  # HYG9605C passive buzzer (verify stock!)
D2,C19171391 → C2286
F1,C369159 → C106264
J2,C124516 → C68234  # CRITICAL: Wrong part (was MOSFET, need header)
J2,C430646 → C474881  # CRITICAL: Wrong part (was 5-pin, need 2-pin screw terminal)
U6,C51118 → C82942
```

---

## Notes

1. **Footprint Updates Required:**
   - BZ1: Update footprint from 7.5x7.5mm to 5.2x5.7mm for MLT-5030

2. **Verify Reference Designators:**
   - U6 in your BOM is AP2112K-3.3, but design guide has this as U3
   - U6 in design guide is 74AHCT245 level shifter
   - Please verify which is correct for your schematic

3. **Stock Verification:**
   - Always verify stock before ordering at [JLCPCB Parts](https://jlcpcb.com/parts)
   - Basic parts have lower assembly fees than Extended parts

---

## Sources

- [JLCPCB Parts Library](https://jlcpcb.com/parts)
- [JLCPCB Resettable Fuses](https://jlcpcb.com/parts/2nd/Circuit_Protection/Resettable_Fuses_3294)
- [JLCPCB LED Indication](https://jlcpcb.com/parts/2nd/Optoelectronics/LED_Indication_Discrete_71)
- [JLCPCB Basic Parts](https://jlcpcb.com/parts/basic_parts)

*Document generated: January 2026*

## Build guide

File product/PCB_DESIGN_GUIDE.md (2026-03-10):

# PCB Design Guide - Circadian Clock v2.1

## Sumário

Este documento descreve o design de uma PCB integrada profissional para o Circadian Clock, incluindo proteções robustas contra inversão de polaridade, curto-circuito, ESD e sobretensão.

---

## 1. Bill of Materials (BOM) Completo

### 1.1 Microcontrolador e Módulos

| Ref | Componente | Especificação | Package | Qty | Preço Unit. | LCSC |
|-----|---|---|---|-----|---|---|
| U1 | ESP32-WROOM-32E | 4MB Flash, WiFi+BLE | Module | 1 | €2.50 | **C701342** |
| U2 | DS3231SN | RTC I2C, ±2ppm, TCXO integrado | SOIC-16W | 1 | €2.37 | **C722469** |
| R7,R8 | 4.7kΩ | I2C pull-up resistors | 0402 | 2 | €0.01 | **C25900** |
| C9 | 100nF | RTC bypass capacitor | 0402 | 1 | €0.01 | **C307331** |
| BT1 | CR2032 Holder | Backup battery holder | THT | 1 | €0.10 | **C70377** |

> **Nota:** O DS3231SN tem cristal TCXO integrado (32.768kHz) - não precisa de cristal externo.
> O pino ~RST tem pull-up interno de 50kΩ - não precisa de pull-up externo.

#### Alternativa RTC: PCF8563T (Preferred Extended - SEM TAXA!)

| Ref | Componente | Especificação | Package | Qty | Preço Unit. | LCSC |
|-----|---|---|---|-----|---|---|
| U2 | **PCF8563T** | RTC I2C, ±20ppm | **SOIC-8** | 1 | **€0.30** | **C7563** |

> **Análise de Custo:** PCF8563T é **Preferred** + Cristal C32346 é **Basic** = **SEM TAXAS!**
>
> | Característica | DS3231SN | PCF8563T + Cristal |
> |----------------|----------|-------------------|
> | Componente | ~€2.37 | ~€0.30 + €0.15 = **€0.45** |
> | Cristal externo | Não precisa (TCXO) | **C32346** (€0.15, **Basic!**) |
> | Taxa JLCPCB | $3 (Extended) | **$0** (Preferred + Basic) |
> | **Total/lote** | **~€5.50** | **~€0.45** |
> | Precisão | ±2ppm (~1 min/ano) | ±20ppm (~10 min/ano) |
> | Package | SOIC-16W | **SOIC-8** |
> | **Poupança** | - | **~€5/lote** |
>
> **RECOMENDAÇÃO:** Substituir por **PCF8563T + Cristal C32346**:
> - Poupança: **~€5/lote** (€2 componente + $3 taxa)
> - Para 50 lotes: **€250 de poupança!**
> - Único trabalho: mudar footprint SOIC-16W → SOIC-8
> - Precisão de ±20ppm é suficiente para relógio circadiano

### 1.2 Alimentação e Regulação (USB-C Power Delivery)

> **Referência:** Arquitetura baseada em [POWER_SUPPLY_v2.md](./POWER_SUPPLY_v2.md) - USB-C Power Delivery
> com duas estratégias possíveis: 5V Direto ou Alta Tensão + Buck Converter.

#### Estratégia A: 5V Direto (Simples - Prototipagem)

| Ref | Componente | Especificação | Package | Qty | Preço Unit. | Notas |
|-----|---|---|---|-----|---|---|
| J1 | USB-C Receptacle | 16-pin, USB 2.0 | SMD | 1 | €0.40 | Alimentação + dados |
| R_CC1, R_CC2 | Resistor 5.1kΩ | 1% 0.1W | 0402 | 2 | €0.01 | USB-C sink detection (5V/3A) |
| U3 | **AP2112K-3.3** | LDO 3.3V 600mA | SOT-23-5 | 1 | €0.15 | Para ESP32 (baixo dropout) |
| C_IN | Capacitor | 10µF 10V X5R | 0603 | 1 | €0.02 | Entrada LDO |
| C_OUT | Capacitor | 10µF 10V X5R | 0603 | 1 | €0.02 | Saída LDO |
| J2 | Screw Terminal | 2-pin 5.0mm 10A | THT | 1 | €0.10 | Alimentação painel LED |

> **Nota:** O AP2112K-3.3 foi escolhido em vez do AMS1117 por ter menor dropout (0.4V vs 1.0V),
> pino de enable para soft-start, e package compacto (SOT-23-5). Usado no Adafruit MatrixPortal S3.

#### Estratégia B: Alta Tensão + Buck Converter (Robusto - Produto Final)

| Ref | Componente | Especificação | Package | Qty | Preço Unit. | Notas |
|-----|---|---|---|-----|---|---|
| J1 | USB-C Receptacle | 16-pin, USB 2.0 | SMD | 1 | €0.40 | Alimentação + dados |
| U_PD | IP2721 | PD Controller 5-20V | DFN-10 | 1 | €0.35 | Negociação USB PD |
| R_SET | Resistor | Ver tabela tensão | 0402 | 1 | €0.01 | Seleção tensão PD |
| U_BUCK | MP1584EN | Buck 3A module | Module | 1 | €0.80 | Step-down para 5V |
| U3 | **AP2112K-3.3** | LDO 3.3V 600mA | SOT-23-5 | 1 | €0.15 | Para ESP32 |
| C_BUCK_IN | Capacitor | 100µF 35V electrolítico | Φ8mm | 1 | €0.15 | Entrada buck |
| C_BULK | Capacitor | 470µF 10V electrolítico | Φ10mm | 1 | €0.15 | Bulk capacitor saída |
| J2 | Screw Terminal | 2-pin 5.0mm 10A | THT | 1 | €0.10 | Alimentação painel LED |

**Resistor SET para IP2721 (Seleção de Tensão PD):**

| Tensão Desejada | Resistor SET | Corrente Cabo | Notas |
|---|---|---|---|
| 20V | 0Ω (curto) | 1.25A @ 25W | Menor corrente, menos perdas |
| 15V | 10kΩ | 1.67A @ 25W | Boa compatibilidade |
| 12V | 20kΩ | 2.08A @ 25W | **Recomendado** |
| 9V | 33kΩ | 2.78A @ 25W | Compatível com muitas fontes |
| 5V | 56kΩ | 5A @ 25W | Não recomendado (alta corrente) |

### 1.3 Proteções (CRÍTICO)

> **Referência:** Proteção USB-C completa baseada em [POWER_SUPPLY_v2.md](./POWER_SUPPLY_v2.md) secção 2.3.1

#### Proteção VBUS (Linha de Alimentação)

| Ref | Componente | Especificação | Package | Qty | Preço Unit. | Função |
|-----|---|---|---|-----|---|---|
| **F1** | **MF-MSMF300** | PTC Fuse 3A hold, 6A trip | 1812 | 1 | €0.15 | **Proteção curto-circuito/overcurrent** |
| **D1** | **SMBJ5.0A** | TVS 5V 600W unidirectional | SMB | 1 | €0.20 | **Proteção sobretensão VBUS** |
| **D1_HV** | **SMBJ24A** | TVS 24V (só Estratégia B) | SMB | 1 | €0.25 | **Proteção sobretensão alta tensão** |

#### Proteção Linhas de Dados e CC (USB-C)

| Ref | Componente | Especificação | Package | Qty | Preço Unit. | Função |
|-----|---|---|---|-----|---|---|
| **D2** | **D3V3XA4B10LP** | TVS Array 4-ch ESD ±15kV | UDFN2510 | 1 | €0.25 | **Proteção ESD D+/D-/CC1/CC2** |

> **Porquê D3V3XA4B10LP?**
> - 4 canais num único chip (protege D+, D-, CC1, CC2)
> - Capacitância ultra-baixa: 0.28pF (não afeta USB 2.0 a 480Mbps)
> - ESD rating: ±15kV (HBM), ±8kV (contacto)
> - Package compacto UDFN2510 (2.5x1.0mm)
> - LCSC: C2827654

#### Proteção Terminais de Parafuso (Saída para Painel)

| Ref | Componente | Especificação | Package | Qty | Preço Unit. | Função |
|-----|---|---|---|-----|---|---|
| **Q_REV** | **Si2301CDS** | P-MOSFET -20V -2.8A | SOT-23 | 1 | €0.10 | **Proteção inversão polaridade** |
| **D_BODY** | (integrado) | Body diode Si2301 | - | 0 | - | Bloqueio polaridade invertida |

#### Proteção Adicional (I2C, GPIOs)

| Ref | Componente | Especificação | Package | Qty | Preço Unit. | Função |
|-----|---|---|---|-----|---|---|
| **U5** | **SRV05-4** | TVS Diode Array | SOT-23-6 | 1 | €0.25 | **Proteção ESD I2C** |
| **Z1** | **PESD5V0S1BA** | ESD protection | SOD-323 | 2 | €0.08 | **ESD GPIO0 (botão), EN** |
| **D3** | **1N5819** | Schottky flyback | SOD-123 | 2 | €0.05 | **Proteção indutiva (futuro)** |

### 1.4 Condensadores

| Ref | Valor | Especificação | Package | Qty | Notas |
|-----|---|---|---|-----|---|
| C1, C2 | 100µF | Electrolítico 16V | 8x10mm | 2 | Entrada/saída power |
| C3, C4 | 22µF | Cerâmico X5R 10V | 0805 | 2 | Bypass LDO |
| C5-C10 | 100nF | Cerâmico X7R 16V | 0402 | 6 | Decoupling |
| C11, C12 | 10µF | Cerâmico X5R 10V | 0603 | 2 | ESP32 bypass |
| C13 | 1µF | Cerâmico X7R 16V | 0402 | 1 | RTC bypass |

### 1.5 Resistências

| Ref | Valor | Especificação | Package | Qty | Notas |
|-----|---|---|---|-----|---|
| R1, R2 | 4.7kΩ | 1% 0.1W | 0402 | 2 | I2C pull-up |
| R3 | 10kΩ | 1% 0.1W | 0402 | 1 | ESP32 EN pull-up |
| R4 | 10kΩ | 1% 0.1W | 0402 | 1 | Button pull-up (backup) |
| R5, R6 | 5.1kΩ | 1% 0.1W | 0402 | 2 | USB-C CC1/CC2 |
| R7 | 0Ω | Jumper | 0402 | 1 | Opcional bypass |
| R8-R10 | 330Ω | 5% 0.1W | 0402 | 3 | LED indicators |

### 1.6 LEDs Indicadores

| Ref | Cor | Especificação | Package | Qty | Função |
|-----|-----|---|---|-----|---|
| LED2 | Vermelho | 3.2V 20mA | 0603 | 1 | WiFi status |

### 1.7 Botões e Interface

| Ref | Componente | Especificação | Package | Qty | Notas |
|-----|---|---|---|-----|---|
| SW1 | Tactile Switch | 6x6mm, 160gf | Through-hole | 1 | Mode button (GPIO0) |

### 1.8 Buzzer e Audio (NOVO - Startup Sound)

| Ref | Componente | Especificação | Package | Qty | Preço Unit. | Função |
|-----|---|---|---|-----|---|---|
| **BZ1** | **MLT-5030** | Piezo passivo 3V 4kHz 80dB | SMD 5.2x5.7mm | 1 | €0.20 | Startup sound/alarme |
| **Q2** | **2N2222** | NPN transistor 40V 800mA | SOT-23 | 1 | €0.05 | Driver buzzer |
| **R11** | **1kΩ** | Resistência 1% 0.1W | 0402 | 1 | €0.01 | Base transistor |
| **D4** | **1N4148** | Diodo switching 100V 150mA | SOD-123 | 1 | €0.02 | Proteção flyback |

**Código LCSC MLT-5030:** `C95297`

**Alternativas:**
- PKM13EPYH4000 (Murata) - LCSC C94599 - Melhor para >5kHz
- CMT-5023S-SMT (CUI) - Mais alto, 90dB

**Funcionalidades:**
- Startup sound retro estilo NES/GameBoy (pulse waves 8-bit)
- Configurável via captive portal (enable/disable)
- Suporta melodias customizáveis e arpeggios
- Futuro: alarmes e notificações sonoras

### 1.9 Conectores

| Ref | Componente | Especificação | Package | Qty | Função |
|-----|---|---|---|-----|---|
| J3 | HUB75 Header | 2x8 pins 2.54mm | Through-hole | 1 | Painel LED P10 |

### 1.10 Conectores HUB75 (Painel LED)

| Pin HUB75 | Sinal | GPIO ESP32 |
|---|---|---|
| 1 | R1 | GPIO 25 |
| 2 | G1 | GPIO 26 |
| 3 | B1 | GPIO 27 |
| 4 | GND | GND |
| 5 | R2 | GPIO 14 |
| 6 | G2 | GPIO 12 |
| 7 | B2 | GPIO 13 |
| 8 | GND | GND |
| 9 | A | GPIO 23 |
| 10 | B | GPIO 19 |
| 11 | C | GPIO 5 |
| 12 | D | GPIO 17 |
| 13 | CLK | GPIO 16 |
| 14 | LAT | GPIO 4 |
| 15 | OE | GPIO 15 |
| 16 | GND | GND |

### 1.11 Level Shifters (NOVO - Baseado em Adafruit MatrixPortal S3)

> **Referência:** O design do [Adafruit MatrixPortal S3](https://github.com/adafruit/Adafruit-MatrixPortal-S3-PCB)
> utiliza level shifting integrado para converter sinais 3.3V do ESP32 para 5V do painel HUB75.

| Ref | Componente | Especificação | Package | Qty | Preço Unit. | Função |
|-----|---|---|---|-----|---|---|
| **U6** | **74AHCT245PW** | Octal bus transceiver | TSSOP-20 | 1 | €0.30 | Level shift sinais RGB + Row |
| **U7** | **74AHCT245PW** | Octal bus transceiver | TSSOP-20 | 1 | €0.30 | Level shift CLK, LAT, OE, C, D |
| U8 | CH340C | USB-UART bridge | SOP-16 | 1 | €0.40 | Programação via USB |
| C14, C15 | 100nF | Cerâmico X7R 16V | 0402 | 2 | €0.02 | Bypass level shifters |

**Porquê 74AHCT245?**
- Aceita entrada 3.3V (Vih = 2.0V) ✓
- Saída 5V quando alimentado a 5V ✓
- 8 canais bidirecionais (usamos unidirecional) ✓
- Propagation delay: ~7ns (rápido para LEDs) ✓
- Disponível e barato na LCSC ✓

**Alternativas:**
| Componente | Canais | Vantagem | Desvantagem |
|---|---|---|---|
| 74AHCT245 | 8 | Standard, barato | Precisa 2 ICs |
| 74HCT245 | 8 | Ainda mais barato | Mais lento |
| TXB0108 | 8 | Bidirecional auto | Mais caro, sensível |
| SN74LV1T34 | 1 | Pequeno | Precisa 13 ICs! |

### 1.12 USB-UART Bridge e Auto-Reset

> **Nota:** O ESP32-WROOM-32E **não tem USB nativo**. Precisa de um chip externo
> para converter USB ↔ UART para programação via Arduino IDE/PlatformIO.

#### Componentes USB-UART

| Ref | Componente | Especificação | Package | Qty | Preço Unit. | Função |
|-----|---|---|---|-----|---|---|
| **U8** | **CH340C** | USB-UART bridge | SOP-16 | 1 | €0.30 | Converte USB para UART |
| **Q1** | **UMH3N** | Dual NPN digital transistor | SOT-363 | 1 | €0.05 | Auto-reset (DTR/RTS) |
| C16 | 100nF | Cerâmico X7R 16V | 0402 | 1 | €0.01 | Bypass CH340C |

**Alternativas ao CH340C:**

| Chip | Preço | Vantagem | Desvantagem |
|---|---|---|---|
| CH340C | €0.30 | Barato, sem cristal externo | Driver Windows pode ser necessário |
| CP2102 | €0.80 | Drivers universais | Mais caro |
| FT232RL | €2.50 | Premium, muito compatível | Caro |

#### Porquê Auto-Reset?

```
SEM Auto-Reset:
━━━━━━━━━━━━━━━
1. Pressionar botão BOOT (GPIO0 → LOW)
2. Pressionar botão RESET (EN → LOW → HIGH)
3. Largar BOOT
4. Fazer upload no Arduino IDE
5. Repetir para cada upload... 😤

COM Auto-Reset:
━━━━━━━━━━━━━━━
1. Clicar "Upload" no Arduino IDE
2. Esperar... ✓ 😊
```

#### Circuito Auto-Reset com UMH3N

O **UMH3N** (ROHM) é um dual NPN digital transistor com resistências integradas.
Substitui 2 transistores + 4 resistências num único chip SOT-363.

```
                                VCC (3.3V)
                                    │
                                    │
        ┌───────────────────────────┴───────────────────────────┐
        │                                                       │
        │              UMH3N (SOT-363)                         │
        │           ┌───────────────────┐                       │
        │           │                   │                       │
 CH340C │           │  ┌─────┐ ┌─────┐  │                       │
  DTR ──┼───────────┤──┤ R1  ├─┤ Q1  ├──┼───────────────────────┼──► EN (ESP32)
        │           │  │ 10k │ │ NPN │  │                       │
        │           │  └─────┘ └──┬──┘  │                       │
        │           │             │     │                       │
        │           │            GND    │                       │
        │           │                   │                       │
 CH340C │           │  ┌─────┐ ┌─────┐  │                       │
  RTS ──┼───────────┤──┤ R2  ├─┤ Q2  ├──┼───────────────────────┼──► GPIO0 (ESP32)
        │           │  │ 10k │ │ NPN │  │                       │
        │           │  └─────┘ └──┬──┘  │                       │
        │           │             │     │                       │
        │           │            GND    │                       │
        │           │     (pin 5)       │                       │
        │           └───────────────────┘                       │
        │                                                       │
        └───────────────────────────────────────────────────────┘

UMH3N Pinout (SOT-363):
━━━━━━━━━━━━━━━━━━━━━━━
Pin 1: B1 (Base Q1)     ← DTR do CH340C
Pin 2: B2 (Base Q2)     ← RTS do CH340C
Pin 3: C1 (Collector Q1) → EN do ESP32
Pin 4: C2 (Collector Q2) → GPIO0 do ESP32
Pin 5: E (Emitters)     → GND
Pin 6: Common           → VCC (3.3V)
```

#### Ligações CH340C

```
CH340C (SOP-16) Pinout:
━━━━━━━━━━━━━━━━━━━━━━━

        ┌────────────────────┐
   GND ─┤1                 16├─ VCC (3.3V)
   TXD ─┤2                 15├─ UD+ (USB D+)
   RXD ─┤3                 14├─ UD- (USB D-)
   V3  ─┤4                 13├─ DTR → UMH3N pin 1
  UD+ ──┤5                 12├─ RTS → UMH3N pin 2
  UD- ──┤6                 11├─ NC
    NC ─┤7                 10├─ NC
    NC ─┤8                  9├─ NC
        └────────────────────┘

Ligações:
━━━━━━━━━
CH340C Pin 2 (TXD) → ESP32 RX (GPIO3)
CH340C Pin 3 (RXD) → ESP32 TX (GPIO1)
CH340C Pin 13 (DTR) → UMH3N Pin 1 (B1)
CH340C Pin 12 (RTS) → UMH3N Pin 2 (B2)
CH340C Pin 1 (GND)  → GND
CH340C Pin 4 (V3)   → 3.3V  ← ⚠️ MODO 3.3V: V3 liga a VCC, NÃO a GND
CH340C Pin 16 (VCC) → 3.3V
CH340C Pin 5 (UD+)  → USB-C D+
CH340C Pin 6 (UD-)  → USB-C D-

Bypass capacitor:
C16 (100nF) entre VCC (pin 16) e GND (pin 1)

Modo de operação — porquê 3.3V e não 5V:
━━━━━━━━━━━━━━━━━━━━━━━━━━━━━━━━━━━━━━━━
O CH340C suporta VCC = 5V ou 3.3V. O comportamento do pino V3 muda:

  VCC = 5V  → V3 = saída do LDO interno (3.3V) → ligar 100nF → GND
              TXD emite 5V → ❌ destrói ESP32 RX (GPIO3 não é 5V-tolerant)

  VCC = 3.3V → V3 = VCC = 3.3V (bypassa o LDO interno)
               TXD emite 3.3V → ✓ compatível com ESP32 directamente

  V3 em modo 3.3V deve ir a VCC (3.3V), nunca a GND.
  Se V3 for a GND com VCC=3.3V: o LDO tenta regular 3.3V→3.3V com
  saída em curto → comportamento indefinido, possível instabilidade.
```

#### Diagrama de Blocos USB-UART

```
┌─────────────────────────────────────────────────────────────────────┐
│                                                                     │
│   USB-C          CH340C              UMH3N           ESP32          │
│  ┌──────┐      ┌────────┐          ┌──────┐      ┌─────────┐       │
│  │      │      │        │          │      │      │         │       │
│  │  D+  ├──────┤UD+  TXD├──────────┼──────┼──────┤RX (IO3) │       │
│  │      │      │        │          │      │      │         │       │
│  │  D-  ├──────┤UD-  RXD├──────────┼──────┼──────┤TX (IO1) │       │
│  │      │      │        │          │      │      │         │       │
│  │ VBUS ├──┐   │    DTR ├──────────┤B1  C1├──────┤EN       │       │
│  │      │  │   │        │          │      │      │         │       │
│  │  GND ├──┼───┤GND RTS ├──────────┤B2  C2├──────┤GPIO0    │       │
│  │      │  │   │        │          │      │      │         │       │
│  └──────┘  │   │    VCC ├───3.3V   │  E   │      │         │       │
│            │   └────────┘          └──┬───┘      └─────────┘       │
│            │                          │                             │
│            │        5V rail           GND                           │
│            └──────────┘                                             │
│                                                                     │
└─────────────────────────────────────────────────────────────────────┘
```

#### Sequência Auto-Reset

```
Quando Arduino IDE inicia upload:
━━━━━━━━━━━━━━━━━━━━━━━━━━━━━━━━━

1. RTS → LOW  (via UMH3N: GPIO0 → LOW = boot mode)
2. DTR → LOW  (via UMH3N: EN → LOW = reset)
3. DTR → HIGH (EN → HIGH = chip inicia)
4. RTS → HIGH (GPIO0 livre, mas já em bootloader)
5. Upload do firmware via UART
6. Reset automático após upload
```

---

## 2. Circuitos de Proteção Detalhados

### 2.1 Proteção Contra Inversão de Polaridade

```
Método 1: Díodo Schottky Série (Recomendado para simplicidade)
═══════════════════════════════════════════════════════════════

    VIN+ ──────┬──────[D1 SS54]──────┬────── +5V_PROTECTED
               │                     │
              ┌┴┐                   ═╧═
         C1   │ │ 100µF             GND
              └┬┘
               │
    VIN- ──────┴─────────────────────────── GND

Características:
- Vf = 0.3-0.5V @ 2A (baixa queda)
- Se polaridade invertida: díodo bloqueia
- Perda: ~0.5W @ 1A

═══════════════════════════════════════════════════════════════

Método 2: P-MOSFET (Recomendado para eficiência)
═══════════════════════════════════════════════════════════════

    VIN+ ──────┬──────────┬──[Q1 Si2301]S────── +5V_PROTECTED
               │          │         │
               │         ┌┴┐        │G
              ┌┴┐    R1  │ │10k     │
         C1   │ │100µF   └┬┘       ─┴─ D
              └┬┘         │        Body diode
               │          │
    VIN- ──────┴──────────┴───────────────── GND

Componentes:
- Q1: Si2301CDS (P-ch MOSFET, -20V, -2.8A, Rds=80mΩ)
- R1: 10kΩ (gate pull-down)

Funcionamento:
- Polaridade correta: Vgs negativo → MOSFET conduz → Rds×I² perda mínima
- Polaridade invertida: Vgs positivo → MOSFET bloqueia
- Perda: ~0.08W @ 1A (vs 0.5W do díodo)
```

### 2.2 Proteção Contra Curto-Circuito

```
Fusível PTC Resettable
═══════════════════════════════════════════════════════════════

    +5V_IN ────[F1 MF-MSMF250]──────┬────── +5V_FUSED
                                    │
                                   ═╧═
                                   GND

Especificações F1 (MF-MSMF250):
- Corrente de hold: 2.5A (funciona normal)
- Corrente de trip: 5.0A (dispara)
- Tempo de trip: <1s @ 10A
- Auto-reset: Sim (arrefece e recupera)
- Resistência: 0.03Ω (perda mínima)

Alternativa - Fusível + Circuito de Crowbar:
═══════════════════════════════════════════════════════════════

                    ┌─────────────────┐
    +5V ──[F1]──┬───┤ TL431 (2.5V)    ├───┐
                │   └────────┬────────┘   │
               ┌┴┐           │           ─┴─
          R1   │ │22k       ─┴─         SCR (crowbar)
               └┬┘          GND          │
                │                        │
    GND ────────┴────────────────────────┘

Se tensão > limite: TL431 dispara SCR → curto-circuito → fusível abre
```

### 2.3 Proteção ESD (Electrostatic Discharge)

#### 2.3.1 Proteção USB-C Completa (VBUS + D+/D- + CC1/CC2)

> **Referência:** [POWER_SUPPLY_v2.md](./POWER_SUPPLY_v2.md) secção 2.3.1

```
Proteção USB-C Completa:
═══════════════════════════════════════════════════════════════

  USB-C Connector
  ┌─────────────────┐
  │                 │
  │ VBUS ───────────┼───┬───[F1 PTC]───[D1 SMBJ5.0A]───┬─► +5V
  │                 │   │                              │
  │                 │   │   ┌──────────────────────────┘
  │                 │   │   │
  │                 │   │   │    ┌─────────────────────────┐
  │                 │   │   │    │    D2: D3V3XA4B10LP     │
  │                 │   │   │    │    (4-channel ESD TVS)  │
  │                 │   │   │    │                         │
  │ D+ ─────────────┼───┼───┼────┤ CH1 ────────────────────┼─► D+ (CH340C)
  │                 │   │   │    │                         │
  │ D- ─────────────┼───┼───┼────┤ CH2 ────────────────────┼─► D- (CH340C)
  │                 │   │   │    │                         │
  │ CC1 ────────────┼───┼───┼────┤ CH3 ──┬──[5.1kΩ]── GND │
  │                 │   │   │    │       │                 │
  │ CC2 ────────────┼───┼───┼────┤ CH4 ──┼──[5.1kΩ]── GND │
  │                 │   │   │    │       │                 │
  │ GND ────────────┼───┴───┴────┤ GND ──┴─────────────────┘
  │                 │            │
  └─────────────────┘            └─────────────────────────┘

═══════════════════════════════════════════════════════════════

  Componentes de Proteção:
  ────────────────────────

  ┌─────────────┬────────────────┬─────────────────────────────┐
  │ Componente  │ Protege        │ Características             │
  ├─────────────┼────────────────┼─────────────────────────────┤
  │ SMBJ5.0A    │ VBUS (5V)      │ 600W surge, alta corrente   │
  │ D3V3XA4B10LP│ D+, D-, CC1/2  │ 0.28pF, ESD ±15kV          │
  │ PTC Fuse    │ Overcurrent    │ 3A hold, 6A trip           │
  └─────────────┴────────────────┴─────────────────────────────┘

  Porque dois TVS diferentes?
  ───────────────────────────
  • VBUS: Precisa de alta capacidade de corrente (surges de rede)
         → SMBJ5.0A (600W, pode absorver grandes surges)

  • D+/D-: Precisa de baixa capacitância (USB 2.0 = 480Mbps)
         → D3V3XA4B10LP (0.28pF, não afecta sinal)

  • CC1/CC2: Comunicação com carregador PD
         → D3V3XA4B10LP (protege negociação PD)

═══════════════════════════════════════════════════════════════
```

#### 2.3.2 Proteção I2C

```
Proteção I2C com SRV05-4
═══════════════════════════════════════════════════════════════

              ┌─────────────────────────┐
    I2C_SDA ──┤1    SRV05-4 (U5)      4├─── VCC (3.3V)
    I2C_SCL ──┤2                      5├─── NC
    GND ──────┤3                      6├─── NC
              └─────────────────────────┘

Especificações SRV05-4:
- Tensão de clamping: 8.5V @ 1A
- Capacitância: 0.5pF (baixa, boa para dados)
- ESD rating: ±15kV (ar), ±8kV (contacto)
```

#### 2.3.3 Proteção GPIO Críticos (Botão, etc.)

```
Proteção GPIO0 (Botão Mode)
═══════════════════════════════════════════════════════════════

    GPIO0 (Button) ───┬───[PESD5V0S1BA]───┬─── GND
                      │                    │
                     ┌┴┐                  ═╧═
                 R4  │ │10k               GND
                     └┬┘
                      │
                     SW1 ─── GND
```

### 2.4 Proteção Contra Sobretensão (Overvoltage)

```
TVS Diode na Entrada
═══════════════════════════════════════════════════════════════

    +VIN ──[F1]──[D1]──┬────────────────┬────── +5V_PROTECTED
                       │                │
                      ─┴─              ┌┴┐
                   D2 SMBJ5.0A    C1   │ │100µF
                      ─┬─              └┬┘
                       │                │
    GND ───────────────┴────────────────┴────── GND

Especificações SMBJ5.0A:
- Standoff voltage: 5.0V (não conduz)
- Breakdown voltage: 6.4V (começa a conduzir)
- Clamping voltage: 9.2V @ 10A
- Potência: 600W (10/1000µs)

Sequência de proteção:
1. Tensão normal (5V): TVS não conduz
2. Spike até 6V: TVS começa a conduzir
3. Spike > 6V: TVS clampa, F1 limita corrente
4. Spike muito alto: F1 abre (protege tudo)
```

### 2.5 Proteção Indutiva (Flyback)

```
Para cargas indutivas (relés, motores futuros)
═══════════════════════════════════════════════════════════════

    GPIO ──────┬──────────────────┐
               │                  │
              ┌┴┐                ─┴─
          R   │ │1k           D3 1N5819 (flyback)
              └┬┘                ─┬─
               │                  │
               └────[Q NPN]───────┴───── LOAD+
                      │
                      └───────────────── LOAD- (VCC)

Quando GPIO = LOW:
- Corrente indutiva tenta continuar
- D3 conduz e dissipa energia
- Protege transistor e GPIO
```

### 2.6 Circuito Buzzer para Startup Sound (NOVO)

```
Driver Transistor para Buzzer Piezo Passivo
═══════════════════════════════════════════════════════════════

                          VCC (+5V)
                            │
                            ├────────┐
                            │        │
                        ┌───┴───┐   ─┴─ D4 (1N4148)
                        │  BZ1  │   ─┬─ Flyback diode
                        │MLT5030│    │
                        │ Piezo │    │
                        └───┬───┘    │
                            │        │
                            └────────┤
                                     │ C (Collector)
    ESP32                          ┌─┴─┐
    GPIO18 ──────[R11]─────────────┤ B │ Q2 (2N2222)
                  1kΩ               └─┬─┘ NPN SOT-23
                                     │ E (Emitter)
                                     │
                                    GND

Especificações:
───────────────
- GPIO: GPIO 18 (PWM channel 0, suporta ledcWrite)
- R11: 1kΩ (limita corrente base, Ib ≈ 3mA)
- Q2: 2N2222 (hFE ≈ 100-300, Ic_max = 800mA, mais que suficiente)
- D4: 1N4148 (proteção flyback contra picos indutivos)
- BZ1: MLT-5030 (Vop = 3V, I = 100mA @ ressonância 4kHz)

**Nota:** GPIO 18 foi escolhido porque GPIO 6-11 estão internamente
ligados à flash SPI do ESP32-WROOM-32E e não devem ser usados.

Funcionamento:
──────────────
1. GPIO18 = HIGH (3.3V via PWM):
   - Corrente base: Ib = (3.3V - 0.7V) / 1kΩ ≈ 2.6mA
   - Corrente coletor: Ic = Ib × hFE ≈ 2.6mA × 100 = 260mA (suficiente!)
   - Transistor satura → Buzzer toca

2. GPIO18 = LOW (0V):
   - Transistor corta → Buzzer silencioso
   - D4 dissipa energia indutiva residual

3. PWM para melodias:
   - Frequências: 20Hz - 40kHz (ledcWriteTone)
   - Duty cycle: 12.5%, 25%, 50% (pulse waves retro)
   - Ressonância ótima: 4kHz (MLT-5030 spec)

Técnicas de Som Retro:
──────────────────────
- **Pulse Wave 25%**: Som clássico NES (duty = 64/256)
- **Arpeggios**: C-E-G rápido = acorde "falso"
- **Pitch Bend**: Sweep de frequência (laser, power-up)
- **Vibrato**: Oscilação ±10Hz @ 20Hz

Exemplo código:
───────────────
void setup() {
  ledcSetup(0, 2000, 8);      // Canal 0, 2kHz, 8-bit
  ledcAttachPin(18, 0);        // GPIO18
}

void startupSound() {
  // Melodia: C5-C5-C5-C6 (GameBoy style)
  tone(523, 100, 64);   // C5, 100ms, duty 25%
  delay(120);
  tone(523, 100, 64);
  delay(120);
  tone(523, 150, 64);
  delay(180);
  tone(1047, 300, 64);  // C6
}

void tone(int freq, int dur, int duty) {
  ledcWriteTone(0, freq);
  ledcWrite(0, duty);
  delay(dur);
  ledcWrite(0, 0);  // Silêncio
}

Layout Tips PCB:
────────────────
1. Q2 próximo do buzzer BZ1 (minimizar trace Collector)
2. R11 próximo do GPIO18 header
3. D4 paralelo ao buzzer, o mais próximo possível
4. Ground return path curto e direto
5. Buzzer longe da antena WiFi (ruído EMI)

Configuração Captive Portal:
────────────────────────────
- Toggle ON/OFF: /api/buzzer/enable
- Volume (via duty): /api/buzzer/volume (12.5%, 25%, 50%)
- Melodia select: /api/buzzer/melody (startup, alarm, error)
```

### 2.7 Circuito RTC DS3231SN (NOVO)

```
Módulo RTC com Bateria de Backup
═══════════════════════════════════════════════════════════════

                        +3.3V
                          │
          ┌───────────────┼───────────────┐
          │               │               │
         ─┴─             ─┴─             ─┴─
     C9  ─┬─ 100nF   R7  │ │ 4.7k   R8  │ │ 4.7k
          │              └┬┘             └┬┘
          │               │               │
          │               │               │
          │        ┌──────┴───────────────┴──────┐
          │        │     SDA (pin 15)            │
          │        │     SCL (pin 16)            │
          │        │                             │
          ├────────┤ VCC (pin 2)                 │
          │        │                             │
          │        │        DS3231SN             │
          │        │                             │
          │        │ ~RST (pin 4) ── NC          │◄── Pull-up interno 50kΩ
          │        │ INT/SQW (pin 3) ── NC       │
          │        │                             │
          │        │ VBAT (pin 14)───────────────┼──── CR2032 (+)
          │        │                             │
          │        │ GND (pin 13)                │
          │        └──────────────┬──────────────┘
          │                       │
          └───────────────────────┴──────────────────── GND ── CR2032 (-)

Pinout DS3231SN (SOIC-16W):
───────────────────────────
        ┌─────────────────┐
  32KHz │ 1            16 │ SCL ──────► ESP32 GPIO22
    VCC │ 2            15 │ SDA ◄─────► ESP32 GPIO21
INT/SQW │ 3 (NC)       14 │ VBAT ◄──── CR2032 (+)
   ~RST │ 4 (NC)       13 │ GND
     NC │ 5            12 │ NC
     NC │ 6            11 │ NC
     NC │ 7            10 │ NC
     NC │ 8             9 │ NC
        └─────────────────┘

Ligações por Placa:
───────────────────
ESP32 Dev Module:
  - SDA → GPIO 21
  - SCL → GPIO 22

Matrix Portal S3:
  - SDA → GPIO 16
  - SCL → GPIO 17

Especificações DS3231SN:
────────────────────────
- Tensão VCC: 2.3V - 5.5V (usar 3.3V)
- Corrente VCC: ~200µA (típica)
- Corrente VBAT: ~0.84µA (backup mode)
- Precisão: ±2ppm (0°C a +40°C)
- Interface: I2C @ 400kHz max
- Endereço I2C: 0x68 (fixo)
- Cristal: TCXO integrado (32.768kHz)

Notas Importantes:
──────────────────
1. ~RST (pin 4): TEM pull-up interno 50kΩ → deixar NC (não conectado)
2. INT/SQW (pin 3): Só usar se precisar de alarmes → deixar NC
3. Cristal: INTEGRADO no DS3231SN → não adicionar cristal externo
4. Pull-ups I2C: 4.7kΩ para 400kHz, podem ser partilhados com outros I2C

Códigos LCSC:
─────────────
U2 (DS3231SN)............. C722469
R7, R8 (4.7kΩ 0402)....... C25900
C9 (100nF 0402)........... C307331
BT1 (CR2032 Holder)....... C70377
```

#### Alternativa: PCF8563T (Preferred Extended - SEM TAXA JLCPCB!)

```
Módulo RTC PCF8563T - Alternativa Económica
═══════════════════════════════════════════════════════════════

                        +3.3V
                          │
          ┌───────────────┼───────────────┐
          │               │               │
         ─┴─             ─┴─             ─┴─
     C9  ─┬─ 100nF   R7  │ │ 4.7k   R8  │ │ 4.7k
          │              └┬┘             └┬┘
          │               │               │
          │        ┌──────┴───────────────┴──────┐
          │        │     SDA (pin 5)             │
          │        │     SCL (pin 6)             │
          │        │                             │
          ├────────┤ VDD (pin 8)                 │
          │        │                             │
          │        │        PCF8563T             │
          │        │        SOIC-8               │
          │        │                             │
          │        │ ~INT (pin 7) ── NC          │◄── Open-drain, pull-up se usar
          │        │ CLKOUT (pin 1) ── NC        │◄── Opcional: 32.768kHz output
          │        │ OSCI (pin 2) ── XTAL        │
          │        │ OSCO (pin 3) ── XTAL        │
          │        │                             │
          │        │ VSS (pin 4)                 │
          │        └──────────────┬──────────────┘
          │                       │
          └───────────────────────┴──────────────────── GND

Pinout PCF8563T (SOIC-8):
─────────────────────────
        ┌─────────────────┐
 CLKOUT │ 1             8 │ VDD ──────► 3.3V
   OSCI │ 2     X1      7 │ ~INT ─────► NC (ou GPIO para alarmes)
   OSCO │ 3     X1      6 │ SCL ──────► ESP32 GPIO22
    VSS │ 4             5 │ SDA ◄────► ESP32 GPIO21
        └─────────────────┘
              │
        Cristal 32.768kHz
        (externo ou oscilador)

Comparação DS3231SN vs PCF8563T:
────────────────────────────────
┌─────────────────┬────────────────┬────────────────┐
│ Característica  │ DS3231SN       │ PCF8563T       │
├─────────────────┼────────────────┼────────────────┤
│ Preço LCSC      │ ~€2.37         │ ~€0.30         │
│ Taxa JLCPCB     │ $3 (Extended)  │ $0 (Preferred) │
│ Package         │ SOIC-16W       │ SOIC-8         │
│ Precisão        │ ±2ppm          │ ±20ppm         │
│ Desvio/ano      │ ~1 minuto      │ ~10 minutos    │
│ TCXO integrado  │ SIM            │ NÃO            │
│ Cristal externo │ Não precisa    │ Precisa        │
│ Endereço I2C    │ 0x68           │ 0x51           │
│ Corrente típica │ 200µA          │ 250nA (!!)     │
│ Backup current  │ 0.84µA         │ 0.25µA         │
└─────────────────┴────────────────┴────────────────┘

Poupança Real: ~€5/lote (PCF8563 Preferred + Cristal Basic = $0 taxas!)

Quando usar cada um:
────────────────────
• DS3231SN: Quando precisão ±2ppm é crítica (instrumentação, logging)
• PCF8563T: RECOMENDADO - Poupança de €5/lote, precisão ±20ppm OK para relógios

IMPORTANTE: O cristal externo (C32346) é **BASIC** - sem taxa!
Combinado com PCF8563T (Preferred) = $0 de taxas Extended.
Poupança total: ~€2 (componente) + $3 (taxa) = ~€5/lote

Códigos LCSC (alternativa):
───────────────────────────
U2 (PCF8563T)............. C7563
R7, R8 (4.7kΩ 0402)....... C25900 (mesmo)
C9 (100nF 0402)........... C307331 (mesmo)
X1 (32.768kHz crystal).... C32346 (se não usar oscilador)
BT1 (CR2032 Holder)....... C70377 (mesmo)

Nota: O PCF8563T também funciona com bateria backup CR2032.
A corrente de backup é ainda menor (0.25µA vs 0.84µA do DS3231).
```

### 2.8 Inrush Current Limiting (Soft-Start)

> **Referência:** [POWER_SUPPLY_v2.md](./POWER_SUPPLY_v2.md) secção 4.3

```
Proteção contra Inrush Current:
═══════════════════════════════════════════════════════════════

  Problema: Ao ligar, condensadores grandes causam pico de corrente
            que pode disparar proteções da fonte USB.

  Solução 1: NTC Thermistor (Simples e Económico)
  ───────────────────────────────────────────────

  +5V_USB ──[NTC 10Ω@25°C]───► +5V_LOAD
                │
               ═╧═
           C_BULK 470µF

  - Frio: alta resistência, limita corrente (~0.5A inicial)
  - Aquece: baixa resistência (<1Ω), operação normal
  - Custo: €0.10
  - Desvantagem: não recupera instantaneamente após desligar

═══════════════════════════════════════════════════════════════

  Solução 2: P-MOSFET com RC Delay (Melhor performance)
  ─────────────────────────────────────────────────────

  +5V_USB ──┬───[R1 10Ω]───┬───────────────────────► +5V_LOAD
            │               │
            │        ┌──────┴──────┐
            │        │   Q1 P-FET  │
            │        │  (Si2301)   │
            │        │   S     D   │
            │        └──────┬──────┘
            │               │
            │     ┌─────────┘
            │     │
            │     │   ┌─────────────┐
            │     │   │   RC Timer  │
            │     └───┤   100ms     │
            │         │   R=100k    │
            │         │   C=1µF     │
            │         └──────┬──────┘
            │                │
  GND ──────┴────────────────┴────────────────────────► GND

  Sequência:
  1. t=0: Fonte liga, corrente passa por R1 (limitada a 0.5A)
  2. t=100ms: Timer ativa Q1, MOSFET bypassa R1
  3. t>100ms: Corrente flui livremente pelo MOSFET (<0.1Ω)

═══════════════════════════════════════════════════════════════
```

### 2.9 Proteção nos Terminais de Parafuso (Inversão de Polaridade)

> **Referência:** [POWER_SUPPLY_v2.md](./POWER_SUPPLY_v2.md) secção 5.2

```
Proteção contra Ligação Inversa nos Terminais:
═══════════════════════════════════════════════════════════════

  ⚠️ Utilizadores podem ligar fios invertidos!

  Solução: P-MOSFET com Body Diode
  ─────────────────────────────────

  +5V_INTERNO ──┬──[Q1 Si2301]──┬──[TERMINAL +]
                │    P-MOSFET   │
                │               │
               ─┴─ D1          ═╧═ C1
            Body diode         100µF
                │               │
  GND ──────────┴───────────────┴──[TERMINAL -]

  Funcionamento:
  - Polaridade correcta: Vgs negativo → MOSFET conduz (Rds ~50mΩ)
  - Polaridade invertida: Vgs positivo → MOSFET bloqueia
  - Perda: ~0.05W @ 1A (muito menor que díodo Schottky)

═══════════════════════════════════════════════════════════════

  Componentes:
  ────────────
  Q1: Si2301CDS (P-ch MOSFET, -20V, -2.8A, Rds=80mΩ)
  R_GATE: 10kΩ (pull-down gate para GND)

  Alternativa simples (com mais perda):
  ─────────────────────────────────────

  +5V_INTERNO ──[D1 SS54 Schottky]──[TERMINAL +]

  Perda: 0.3V × 3A = 0.9W (aceitável mas gera calor)

═══════════════════════════════════════════════════════════════
```

### 2.10 Level Shifter 3.3V → 5V para HUB75

> **Baseado no design Adafruit MatrixPortal S3**
> Fonte: https://github.com/adafruit/Adafruit-MatrixPortal-S3-PCB

```
ANTES (Design Original - Ligação Direta):
═══════════════════════════════════════════════════════════════

    ESP32 (3.3V logic)              P10 Panel (5V logic)
    ─────────────────               ─────────────────────
    GPIO 25 ─────────────────────── R1   ⚠️ PROBLEMA!
    GPIO 26 ─────────────────────── G1
    GPIO 27 ─────────────────────── B1   Os painéis HUB75 esperam
    GPIO 14 ─────────────────────── R2   sinais 5V (Vih ≈ 3.5V)
    GPIO 12 ─────────────────────── G2
    GPIO 13 ─────────────────────── B2   ESP32 output = 3.3V
    GPIO 23 ─────────────────────── A    Pode funcionar, mas é
    GPIO 19 ─────────────────────── B    marginal e instável!
    GPIO 5  ─────────────────────── C
    GPIO 17 ─────────────────────── D
    GPIO 16 ─────────────────────── CLK
    GPIO 4  ─────────────────────── LAT
    GPIO 15 ─────────────────────── OE

Problemas:
- Sinais 3.3V são marginais para lógica 5V
- Painéis diferentes têm thresholds diferentes
- Pode causar flickering ou cores erradas
- Falhas intermitentes difíceis de diagnosticar

═══════════════════════════════════════════════════════════════

DEPOIS (Design Melhorado - Com Level Shifter):
═══════════════════════════════════════════════════════════════

                              VCC = 5V
                                 │
                  ┌──────────────┴──────────────┐
                  │         74AHCT245 (U6)      │
                  │           VCC=5V            │
                  │                             │
    ESP32         │                             │         HUB75
    ─────         │  DIR  OE                    │         ─────
    GPIO25 ───────┤A1  │   │                 B1├───────── R1
    GPIO26 ───────┤A2  │   │                 B2├───────── G1
    GPIO27 ───────┤A3  │   │                 B3├───────── B1
    GPIO14 ───────┤A4  │   │                 B4├───────── R2
    GPIO12 ───────┤A5  │   │                 B5├───────── G2
    GPIO13 ───────┤A6  │   │                 B6├───────── B2
    GPIO23 ───────┤A7  │   │                 B7├───────── A
    GPIO19 ───────┤A8  │   │                 B8├───────── B
                  │    │   │                    │
                  │   GND GND                   │
                  │    │   │                    │
                  └────┴───┴────────────────────┘
                       │
                      GND
                       │
                  ┌────┴───┬────────────────────┐
                  │    │   │                    │
                  │   GND GND                   │
                  │    │   │                    │
                  │  DIR  OE                    │
    GPIO5  ───────┤A1  │   │                 B1├───────── C
    GPIO17 ───────┤A2  │   │                 B2├───────── D
    GPIO4  ───────┤A3  │   │                 B3├───────── LAT
    GPIO15 ───────┤A4  │   │                 B4├───────── OE
    GPIO16 ───────┤A5  │   │                 B5├───────── CLK
    NC ────────────┤A6                       B6├───────── NC
    NC ────────────┤A7                       B7├───────── NC
    NC ────────────┤A8                       B8├───────── NC
                  │                             │
                  │         74AHCT245 (U7)      │
                  │           VCC=5V            │
                  └──────────────┬──────────────┘
                                 │
                                GND

Ligações 74AHCT245:
- Pin 1 (OE active low): GND (sempre ativo)
- Pin 19 (DIR): GND (A→B, unidirecional)
- Pin 10 (GND): GND
- Pin 20 (VCC): +5V

Condensadores bypass:
- C14: 100nF entre VCC e GND do U6 (o mais perto possível)
- C15: 100nF entre VCC e GND do U7 (o mais perto possível)

═══════════════════════════════════════════════════════════════

Vantagens do Design Melhorado:
✓ Sinais robustos 5V para o painel
✓ Compatível com qualquer painel HUB75
✓ Sem flickering ou cores erradas
✓ Protege GPIOs do ESP32 de backfeed
✓ Custo adicional: apenas €0.60

═══════════════════════════════════════════════════════════════
```

**Pinout 74AHCT245 (TSSOP-20):**

```
        ┌────────────────────┐
   OE ──┤1                 20├── VCC (5V)
   A1 ──┤2                 19├── DIR
   A2 ──┤3                 18├── B1
   A3 ──┤4                 17├── B2
   A4 ──┤5                 16├── B3
   A5 ──┤6                 15├── B4
   A6 ──┤7                 14├── B5
   A7 ──┤8                 13├── B6
   A8 ──┤9                 12├── B7
  GND ──┤10                11├── B8
        └────────────────────┘

OE = Output Enable (active LOW) → GND
DIR = Direction (LOW = A→B) → GND
```

**Layout Tips (Adafruit Style):**

```
┌─────────────────────────────────────────────────────────────┐
│                     PCB LAYOUT TIPS                         │
├─────────────────────────────────────────────────────────────┤
│                                                             │
│  1. POSICIONAMENTO                                          │
│     ┌─────────┐                                             │
│     │  ESP32  │──── curto ────┌─────────┐                   │
│     └─────────┘      <2cm     │74AHCT245│─── curto ──[HUB75]│
│                               └─────────┘     <2cm          │
│                                                             │
│  2. BYPASS CAPS - O mais perto possível do IC               │
│                                                             │
│     ┌─────────────────────────┐                             │
│     │      74AHCT245          │                             │
│     │  VCC ────┬──── GND      │                             │
│     │         ═╪═             │                             │
│     │       [100nF]           │   ← Mesmo lado do IC        │
│     │          │              │                             │
│     └──────────┼──────────────┘                             │
│               GND                                           │
│                                                             │
│  3. GROUND PLANE - Retorno de corrente direto               │
│                                                             │
│     Top Layer: Sinais                                       │
│     Bottom Layer: GND plane (contínuo sob os ICs)           │
│                                                             │
│  4. TRACE WIDTH                                             │
│     - Sinais: 0.2mm (8mil) mínimo                          │
│     - VCC/GND: 0.4mm (16mil) ou mais                       │
│     - HUB75 CLK: manter curto, evitar vias                 │
│                                                             │
└─────────────────────────────────────────────────────────────┘
```

---

## 3. Esquema de Blocos

> **Referência:** Arquitetura baseada em [POWER_SUPPLY_v2.md](./POWER_SUPPLY_v2.md)

### 3.1 Estratégia A: 5V Direto (Prototipagem)

```
┌─────────────────────────────────────────────────────────────────────────────┐
│                    CIRCADIAN CLOCK PCB v2.1 - ESTRATÉGIA A                   │
├─────────────────────────────────────────────────────────────────────────────┤
│                                                                             │
│  ┌────────────┐      ┌─────────────────────────────────────────────────┐   │
│  │            │      │                    PCB                          │   │
│  │  FONTE     │      │                                                 │   │
│  │  USB-C     │      │   ┌────────┐    ┌─────────┐    ┌────────────┐  │   │
│  │  5V/3A     ├──────┤──►│ USB-C  │───►│ FUSÍVEL │───►│ TERMINAIS  │  │   │
│  │  (15W)     │      │   │ Recept.│    │+TVS+ESD │    │ PARAFUSO   │  │   │
│  │            │      │   └────┬───┘    └────┬────┘    └─────┬──────┘  │   │
│  └────────────┘      │        │             │               │         │   │
│                      │        │  D3V3XA4B10LP               │         │   │
│                      │        │  (ESD D+/D-/CC)             ▼         │   │
│                      │        ▼             │         ┌───────────┐   │   │
│                      │   ┌────────┐         │         │  PAINEL   │   │   │
│                      │   │ CH340C │         │         │   P10     │   │   │
│                      │   │ USB-   │         │         │ 32x16 RGB │   │   │
│                      │   │ UART   │         │         └───────────┘   │   │
│                      │   └────┬───┘         ▼                         │   │
│                      │        │       ┌──────────┐                    │   │
│                      │        │       │ AP2112K  │                    │   │
│                      │        │       │  3.3V    │                    │   │
│                      │        │       └────┬─────┘                    │   │
│                      │        │            │                          │   │
│                      │        ▼            ▼                          │   │
│                      │   ┌─────────────────────┐                      │   │
│                      │   │      ESP32          │◄──► DS3231 RTC       │   │
│                      │   │   (3.3V logic)      │                      │   │
│                      │   └─────────┬───────────┘                      │   │
│                      │             │                                  │   │
│                      │             ▼                                  │   │
│                      │   ┌──────────────────┐                         │   │
│                      │   │   74AHCT245 (x2) │──► HUB75 Header        │   │
│                      │   │   3.3V → 5V      │                         │   │
│                      │   └──────────────────┘                         │   │
│                      └─────────────────────────────────────────────────┘   │
└─────────────────────────────────────────────────────────────────────────────┘
```

### 3.2 Estratégia B: Alta Tensão + Buck (Produto Final)

```
┌─────────────────────────────────────────────────────────────────────────────┐
│                    CIRCADIAN CLOCK PCB v2.1 - ESTRATÉGIA B                   │
├─────────────────────────────────────────────────────────────────────────────┤
│                                                                             │
│   ┌────────────┐                                                            │
│   │            │      ┌──────────────────────────────────────────────────┐ │
│   │  FONTE     │      │                      PCB                         │ │
│   │  USB-C PD  │      │                                                  │ │
│   │  45-65W    │      │  ┌────────┐  ┌────────┐  ┌────────┐  ┌────────┐ │ │
│   │            ├──────┤─►│ USB-C  │─►│  PD    │─►│ BUCK   │─►│TERMINAL│ │ │
│   │  9V/12V/   │      │  │ Recept.│  │IP2721  │  │MP1584EN│  │PARAFUSO│ │ │
│   │  15V/20V   │      │  └────┬───┘  └────┬───┘  └────┬───┘  └───┬────┘ │ │
│   │            │      │       │           │           │          │      │ │
│   └────────────┘      │       │  D3V3XA4B10LP         │          │      │ │
│                       │       │  (ESD D+/D-/CC)       │          ▼      │ │
│                       │       ▼           │           ▼    ┌────────┐   │ │
│                       │  ┌────────┐       │     ┌────────┐ │ PAINEL │   │ │
│                       │  │ CH340C │       │     │ +5V    │ │  P10   │   │ │
│                       │  │ USB-   │       │     │ Rail   │ │ (5V)   │   │ │
│                       │  │ UART   │       │     └───┬────┘ └────────┘   │ │
│                       │  └────┬───┘       │         │                   │ │
│                       │       │           ▼         ▼                   │ │
│                       │       │     ┌──────────┐  ┌───────────┐         │ │
│                       │       │     │ AP2112K  │  │ 74AHCT245 │         │ │
│                       │       │     │  3.3V    │  │   (x2)    │         │ │
│                       │       │     └────┬─────┘  └─────┬─────┘         │ │
│                       │       │          │              │               │ │
│                       │       ▼          ▼              ▼               │ │
│                       │  ┌────────────────────────────────────┐         │ │
│                       │  │            ESP32 + DS3231          │         │ │
│                       │  │                                    │         │ │
│                       │  │  ← UART      3.3V logic    HUB75 →│         │ │
│                       │  └────────────────────────────────────┘         │ │
│                       │                                                  │ │
│                       └──────────────────────────────────────────────────┘ │
│                                                                             │
│   Vantagens Estratégia B:                                                   │
│   ✓ Fontes 45-65W USB-C são MUITO comuns (laptops, tablets)                │
│   ✓ Menor corrente no cabo = menores perdas (I²R)                          │
│   ✓ Buck converter fornece 5V estável com alta eficiência (>90%)           │
│   ✓ Maior margem para picos de corrente                                    │
│   ✓ Brilho 100% disponível sem restrições                                  │
│                                                                             │
└─────────────────────────────────────────────────────────────────────────────┘
```

---

## 4. Software para Design de PCB

### 4.1 Opções Recomendadas

| Software | Custo | Nível | Prós | Contras | Recomendação |
|---|---|---|---|---|---|
| **KiCad 9** | Grátis | Intermédio | Open-source, completo, JLCPCB integração | Curva aprendizagem | ⭐⭐⭐⭐⭐ **RECOMENDADO** |
| **EasyEDA** | Grátis | Iniciante | Browser-based, integração JLCPCB/LCSC | Limitado offline | ⭐⭐⭐⭐ Bom para começar |
| **Altium Designer** | €3000+/ano | Profissional | Industry standard, poderoso | Caro, complexo | ⭐⭐⭐ Overkill |
| **Eagle** | €500/ano | Intermédio | Estabelecido, boas libs | Autodesk lock-in | ⭐⭐⭐ |
| **Fusion 360 Electronics** | Grátis* | Iniciante | Integrado com CAD mecânico | Limitações grátis | ⭐⭐⭐ |

### 4.2 Workflow Recomendado: KiCad 9

```
┌─────────────┐    ┌─────────────┐    ┌─────────────┐    ┌─────────────┐
│  Schematic  │───►│   Symbols   │───►│  PCB Layout │───►│   Gerbers   │
│   Editor    │    │   + Libs    │    │   Editor    │    │   Export    │
│  (Eeschema) │    │             │    │  (Pcbnew)   │    │             │
└─────────────┘    └─────────────┘    └─────────────┘    └─────────────┘
                                                               │
                                                               ▼
                                                        ┌─────────────┐
                                                        │  JLCPCB     │
                                                        │  Order      │
                                                        └─────────────┘
```

**Instalação KiCad 9:**
```bash
# Ubuntu/Debian
sudo add-apt-repository ppa:kicad/kicad-8.0-releases
sudo apt update
sudo apt install kicad

# Windows/Mac
# Download: https://www.kicad.org/download/

# Bibliotecas adicionais (ESP32, etc.)
git clone https://github.com/espressif/kicad-libraries.git
```

### 4.3 Bibliotecas Necessárias

| Biblioteca | Componentes | URL |
|---|---|-----|
| Espressif KiCad | ESP32-WROOM-32E | github.com/espressif/kicad-libraries |
| SnapEDA | DS3231, USB-C, etc. | snapeda.com |
| Ultra Librarian | Componentes LCSC | ultralibrarian.com |
| KiCad Official | Básicos | Incluído no KiCad |

### 4.4 Plugins Úteis para KiCad

| Plugin | Função |
|---|---|
| **JLCPCB Tools** | Exportar BOM e CPL para JLCPCB |
| **Interactive HTML BOM** | Gerar BOM visual interativo |
| **KiCost** | Calcular custos de componentes |
| **Teardrops** | Melhorar fiabilidade das vias |
| **RF Tools** | Para antena WiFi do ESP32 |

### 4.5 Importar Componentes LCSC com easyeda2kicad

O **easyeda2kicad** é uma ferramenta Python que permite importar símbolos, footprints e modelos 3D diretamente da biblioteca LCSC/EasyEDA para o KiCad.

**Instalação:**
```bash
pip3 install easyeda2kicad
```

**Uso básico - importar componente completo:**
```bash
# Sintaxe: python3 -m easyeda2kicad --symbol --footprint --3d --lcsc_id=CXXXXXX

# Exemplos deste projeto:
python3 -m easyeda2kicad --symbol --footprint --3d --lcsc_id=C207642   # SY8368AQQC (Buck Converter)
python3 -m easyeda2kicad --symbol --footprint --3d --lcsc_id=C2831487  # SRP1265A-2R2M (Indutor 2.2µH)
python3 -m easyeda2kicad --symbol --footprint --3d --lcsc_id=C603176   # IP2721 (PD Trigger)
python3 -m easyeda2kicad --symbol --footprint --3d --lcsc_id=C20917    # AO3400A (MOSFET)
```

**Localização dos ficheiros gerados (default):**
```
~/Documents/Kicad/easyeda2kicad/
├── easyeda2kicad.kicad_sym      # Símbolos
├── easyeda2kicad.pretty/        # Footprints (.kicad_mod)
└── easyeda2kicad.3dshapes/      # Modelos 3D (.wrl)
```

**Configurar biblioteca no KiCad:**

1. **Símbolos:** Preferences → Manage Symbol Libraries → Add `easyeda2kicad.kicad_sym`
2. **Footprints:** No **PCB Editor** → Preferences → Manage Footprint Libraries → Add:
   - Nickname: `easyeda2kicad`
   - Path: `~/Documents/Kicad/easyeda2kicad/easyeda2kicad.pretty`

**Opções úteis:**
```bash
--overwrite          # Atualizar componente existente
--output /path/      # Especificar pasta de destino
--symbol             # Só símbolo
--footprint          # Só footprint
--3d                 # Só modelo 3D
```

**Troubleshooting:**
- Se aparecer `[WARNING] This id is already in...` usa `--overwrite`
- Se o nome do footprint não corresponder ao esperado, renomeia o ficheiro `.kicad_mod` ou edita a referência no esquemático

---

## 5. Regras de Design PCB

### 5.1 Especificações para JLCPCB

| Parâmetro | Valor Mínimo | Recomendado |
|---|---|---|
| Largura de pista | 0.127mm (5mil) | 0.25mm (10mil) |
| Espaçamento | 0.127mm (5mil) | 0.2mm (8mil) |
| Via drill | 0.3mm | 0.4mm |
| Via pad | 0.6mm | 0.8mm |
| Camadas | 2 | 4 (se complexo) |
| Espessura | 1.6mm | 1.6mm |
| Cobre | 1oz | 2oz (power) |

### 5.2 Boas Práticas para ESP32

```
Layout Crítico:
═══════════════════════════════════════════════════════════════

1. ANTENA WiFi
   ┌────────────────────────────────────────────────────────┐
   │  ╔═══════════════════════════════════════════════════╗│
   │  ║                                                   ║│ ← Keep-out zone
   │  ║     [Antena ESP32]   NADA AQUI!                  ║│   15mm mínimo
   │  ║                      Sem cobre, vias, traços     ║│
   │  ╚═══════════════════════════════════════════════════╝│
   │                                                        │
   │  [ESP32-WROOM-32E]                                     │
   │                                                        │
   └────────────────────────────────────────────────────────┘

2. DECOUPLING - Condensadores o mais próximo possível dos pinos

   [ESP32]─────┬─────[100nF]─────GND
               │
               └─────[10µF]──────GND

3. POWER PLANES (se 4 camadas)
   Layer 1: Sinais + Componentes
   Layer 2: GND (plano contínuo)
   Layer 3: 3.3V / 5V
   Layer 4: Sinais + Componentes

4. I2C - Manter curto, pull-ups perto do master

   [ESP32]──────────────[4.7k]──────┬───── SDA ──────[DS3231]
           < 10cm                   │
                                   3.3V
```

### 5.3 Checklist Antes de Fabricar

- [ ] DRC (Design Rule Check) passa sem erros
- [ ] ERC (Electrical Rule Check) passa sem erros
- [ ] Verificar footprints vs datasheet
- [ ] Verificar polaridade de díodos e condensadores
- [ ] Antena ESP32 sem obstruções
- [ ] Furos de montagem (M3, 3.2mm)
- [ ] Silkscreen legível e correto
- [ ] Fiducials para SMT assembly
- [ ] Testpoints para debug

---

## 6. Ordem de Fabrico

### 6.1 Opções de Fabricante

| Fabricante | PCB 5pcs | Assembly | Lead Time | Notas |
|---|---|---|---|---|
| **JLCPCB** | $2-5 | $8+ setup | 5-7 dias | ⭐ Mais económico |
| **PCBWay** | $5-10 | $10+ setup | 5-7 dias | Boa qualidade |
| **ALLPCB** | $5-8 | Sim | 5-7 dias | Alternativa |
| **OSH Park** | $10+ | Não | 12+ dias | Made in USA |
| **Seeed Fusion** | $5-10 | Sim | 7-10 dias | Bom para protos |

### 6.2 Ficheiros para Encomendar

```
Para PCB:
├── Gerbers/
│   ├── project-F_Cu.gtl       (Top copper)
│   ├── project-B_Cu.gbl       (Bottom copper)
│   ├── project-F_Mask.gts     (Top solder mask)
│   ├── project-B_Mask.gbs     (Bottom solder mask)
│   ├── project-F_SilkS.gto    (Top silkscreen)
│   ├── project-B_SilkS.gbo    (Bottom silkscreen)
│   ├── project-Edge_Cuts.gm1  (Board outline)
│   └── project.drl            (Drill file)
│
Para Assembly (SMT):
├── BOM.csv                    (Bill of Materials)
└── CPL.csv                    (Component Placement List)
```

### 6.3 BOM USB-C Power (Resumo)

> **Referência:** BOM completo em [POWER_SUPPLY_v2.md](./POWER_SUPPLY_v2.md) secção 7

#### Estratégia A: 5V Direto (€1.82 total power + proteção)

| Ref | Componente | Especificação | Package | Qty | Preço | LCSC |
|-----|---|---|---|-----|---|---|
| J1 | USB-C Receptacle | 16-pin, USB 2.0 | SMD | 1 | €0.40 | C165948 |
| R_CC1, R_CC2 | Resistor 5.1kΩ | 1% 0.1W | 0402 | 2 | €0.01 | C25905 |
| F1 | PTC Fuse | 3A hold, 6A trip | 1812 | 1 | €0.15 | C369159 |
| D1 | TVS SMBJ5.0A | 5V 600W (VBUS) | SMB | 1 | €0.20 | C123799 |
| D2 | TVS D3V3XA4B10LP | 4-ch ESD (D+/D-/CC) | UDFN2510 | 1 | €0.25 | C2827654 |
| C_BULK | Capacitor | 470µF 16V electrolítico | Φ10mm | 1 | €0.15 | C134768 |
| U3 | AP2112K-3.3 | LDO 3.3V 600mA | SOT-23-5 | 1 | €0.15 | C51118 |
| J2 | Screw Terminal | 2-pin 5.0mm 10A | THT | 1 | €0.10 | C474881 |
| LED1, LED2 | LED Verde | 0805 ~2V 20mA | 0805 | 2 | €0.04 | C2297 |
| R_LED1, R_LED2 | Resistor | 1kΩ 1% | 0402 | 2 | €0.02 | C11702 |

#### Estratégia B: Alta Tensão + Buck (€3.45 total power + proteção)

| Ref | Componente | Especificação | Package | Qty | Preço | LCSC |
|-----|---|---|---|-----|---|---|
| J1 | USB-C Receptacle | 16-pin, USB 2.0 | SMD | 1 | €0.40 | C165948 |
| U_PD | IP2721 | PD Controller 5-20V | DFN-10 | 1 | €0.35 | C2889848 |
| R_SET | Resistor | 20kΩ (para 12V) | 0402 | 1 | €0.01 | - |
| U_BUCK | MP1584EN | Buck 3A module | Module | 1 | €0.80 | Módulo |
| F1 | PTC Fuse | 3A hold | 1812 | 1 | €0.15 | C369159 |
| D1 | TVS SMBJ24A | 24V (VBUS HV) | SMB | 1 | €0.25 | C114152 |
| D2 | TVS D3V3XA4B10LP | 4-ch ESD (D+/D-/CC) | UDFN2510 | 1 | €0.25 | C2827654 |
| C_BUCK_IN | Capacitor | 100µF 35V electrolítico | Φ8mm | 1 | €0.15 | C249490 |
| C_BULK | Capacitor | 470µF 10V electrolítico | Φ10mm | 1 | €0.15 | C134768 |
| U3 | AP2112K-3.3 | LDO 3.3V 600mA | SOT-23-5 | 1 | €0.15 | C51118 |
| J2 | Screw Terminal | 2-pin 5.0mm 10A | THT | 1 | €0.10 | C474881 |
| Q_REV | Si2301CDS | P-MOSFET inversão | SOT-23 | 1 | €0.10 | C10487 |
| LED1, LED2 | LED Verde | 0805 ~2V 20mA | 0805 | 2 | €0.04 | C2297 |
| R_LED1, R_LED2 | Resistor | 1kΩ 1% | 0402 | 2 | €0.02 | C11702 |

---

## 7. Estimativa de Custos

### 7.1 Protótipo (5 PCBs)

| Item | Custo |
|---|---|
| PCB fabricação (5 pcs) | €5 |
| SMT assembly (opcional) | €15 |
| Componentes (5 sets) | €100 |
| Shipping | €15-30 |
| **Total** | **€135-150** |

### 7.2 Produção (100 pcs)

| Item | Custo Unit. | Total |
|---|---|---|
| PCB | €0.50 | €50 |
| SMT assembly | €3.00 | €300 |
| Componentes | €8.00 | €800 |
| Shipping | - | €50 |
| **Total** | **€12/unidade** | **€1,200** |

---

## 8. Próximos Passos

1. **Semana 1:** Instalar KiCad 9 + bibliotecas
2. **Semana 2:** Desenhar esquemático completo
3. **Semana 3:** Layout PCB + DRC/ERC
4. **Semana 4:** Revisão + encomendar protótipos
5. **Semana 5-6:** Receber e testar protótipos
6. **Semana 7:** Iterar se necessário

---

*Documento criado: Dezembro 2025*
*Última atualização: Janeiro 2026*
*Versão: 2.3*

**Changelog v2.3 (Jan 2026):**
- **Secção 1.1: Adicionada** Alternativa RTC PCF8563T (Preferred Extended)
  - PCF8563T (C7563) é **Preferred Extended** = sem taxa de carregamento JLCPCB!
  - Tabela comparativa DS3231SN vs PCF8563T (preço, precisão, package, taxa)
  - Poupança total: ~€2 (componente) + $3 (taxa) = ~€5/lote
  - Nota sobre diferença de package (SOIC-16W vs SOIC-8)
- **Secção 2.7: Adicionada** Circuito alternativo PCF8563T
  - Esquema completo com pinout SOIC-8
  - Comparação detalhada de especificações
  - Códigos LCSC para alternativa (inclui cristal externo C32346)
  - Nota: corrente backup ainda menor (0.25µA vs 0.84µA)

**Changelog v2.2 (Jan 2026):**
- **Secção 1.1: Atualizada** com códigos LCSC para RTC module completo
  - DS3231SN (C722469), 4.7kΩ pull-ups (C25900), 100nF bypass (C307331), CR2032 holder (C70377)
  - Nota sobre TCXO integrado e pull-up interno do ~RST
- **Secção 2.7: Adicionada** Circuito RTC DS3231SN completo
  - Esquema de ligações com pull-ups I2C
  - Pinout SOIC-16W detalhado
  - Ligações por placa (ESP32 Dev vs Matrix Portal S3)
  - Especificações e notas importantes (~RST não precisa pull-up externo)
- Renumeração de secções: 2.7→2.8 (Inrush), 2.8→2.9→2.10 (Terminais), 2.9→2.10→2.11 (Level Shifter)

**Changelog v2.1 (Jan 2026):**
- **Secção 1.8: Adicionada** Buzzer e Audio para startup sound retro estilo NES/GameBoy
  - MLT-5030 piezo passivo (LCSC C95297) com driver 2N2222
  - BOM completo: BZ1, Q2, R11, D4
  - Alternativas: PKM13EPYH4000 (Murata), CMT-5023S-SMT (CUI)
- **Secção 2.6: Adicionada** Circuito Buzzer completo com driver transistor NPN
  - GPIO 18 (escolhido porque GPIO 6-11 são flash SPI)
  - Exemplo código PWM com melodias retro
  - Técnicas: Pulse waves, arpeggios, pitch bend, vibrato
  - Layout tips PCB e configuração captive portal
- Renumeração de secções: 1.8→1.9 (Conectores), 2.6→2.7 (Inrush), 2.7→2.8 (Terminais), 2.8→2.9 (Level Shifter)

**Changelog v2.0 (Dez 2025):**
- Secção 1.2: Atualizada com USB-C Power Delivery (Estratégias A e B), AP2112K, PD controller IP2721, Buck converter MP1584EN, terminais de parafuso
- Secção 1.3: Atualizada com proteção ESD USB-C completa (D3V3XA4B10LP para D+/D-/CC1/CC2), proteção VBUS (SMBJ5.0A/SMBJ24A), proteção terminais (Si2301CDS)
- Secção 2.3: Adicionada proteção USB-C detalhada com circuito completo
- Secção 2.7: Adicionada proteção inrush current com NTC thermistor e P-MOSFET soft-start
- Secção 2.8: Adicionada proteção inversão polaridade nos terminais de parafuso
- Secção 3: Atualizado esquema de blocos com duas estratégias (A: 5V Direto, B: Alta Tensão + Buck)
- Secção 6.3: Adicionado BOM resumo para USB-C Power (Estratégias A e B)
- Referências cruzadas com POWER_SUPPLY_v2.md

**Changelog v1.1 (Dez 2025):**
- Adicionada secção 1.11 (Level Shifters) e 2.9 (Circuito Level Shifter) baseado em Adafruit MatrixPortal S3

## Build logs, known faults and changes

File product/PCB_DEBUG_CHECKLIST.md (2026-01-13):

# PCB Debug Checklist - Primeiro Teste

Checklist para verificar se um PCB está funcional ao receber do fornecedor (JLCPCB, PCBWay, etc.)

---

## Ferramentas Necessárias

- Multímetro digital
- Cabo USB-C
- Computador com terminal série (PuTTY, screen, minicom, Arduino IDE)

---

## Passo 1: Inspecção Visual (sem ligar)

| Verificação | OK |
|---|:--:|
| Sem pontes de solda visíveis | ☐ |
| Componentes na orientação correcta (polaridade ICs, LEDs, díodos) | ☐ |
| Todos os componentes presentes | ☐ |
| Soldas brilhantes e côncavas (não foscas ou em bola) | ☐ |
| PCB sem riscos ou danos visíveis | ☐ |

---

## Passo 2: Teste de Continuidade (sem ligar)

> ⚠️ **PCB desligado!** Multímetro em modo continuidade (beep) ou resistência (Ω)

| Teste | Esperado | Resultado |
|---|---|:---:|
| VBUS ↔ GND | ABERTO (>1MΩ, não apita) | ☐ |
| 5V ↔ GND | ABERTO (>1MΩ, não apita) | ☐ |
| 3V3 ↔ GND | ABERTO (>1MΩ, não apita) | ☐ |

> 🔴 **Se algum apitar = CURTO!** Não ligar. Procurar ponte de solda ou componente defeituoso.

---

## Passo 3: Teste de Alimentação (ligar USB)

> Ligar a um carregador USB básico (não ao computador) para primeiro teste

| Medição | Esperado | Resultado |
|---|---|:---:|
| Rail VBUS/5V | 4.9V - 5.1V | ☐ ___V |
| Saída LDO (3V3) | 3.2V - 3.4V | ☐ ___V |
| Pino 3V3 do ESP32 | 3.2V - 3.4V | ☐ ___V |
| Consumo em idle | < 100mA | ☐ |

> 🔴 **Se não há 3.3V:** Problema no LDO, curto no rail 3V3, ou ESP32 em curto.
>
> 🔴 **Se consumo > 500mA:** Curto-circuito algures. Desligar imediatamente.

---

## Passo 4: Reconhecimento USB (ligar ao PC)

| Sistema | Comando/Verificação |
|---|---|
| **macOS** | `ls /dev/cu.usb*` |
| **Linux** | `ls /dev/ttyUSB*` ou `ls /dev/ttyACM*` |
| **Windows** | Gestor de Dispositivos → Portas (COM & LPT) |

| Verificação | OK |
|---|:--:|
| Porta série aparece (ex: `/dev/cu.usbserial-XXX` ou `COM3`) | ☐ |
| Identificada como "CH340" ou similar | ☐ |

> 🔴 **Se não aparece:**
> - CH340C mal soldado
> - Problema nas linhas D+/D-
> - Driver CH340 não instalado (Windows)

---

## Passo 5: ESP32 Responde

1. Abrir terminal série:
   ```bash
   # macOS/Linux
   screen /dev/cu.usbserial-XXX 115200

   # Ou usar Arduino IDE → Serial Monitor → 115200 baud
   ```

2. Premir botão **EN** (reset)

3. Verificar output do bootloader:

```
rst:0x1 (POWERON_RESET),boot:0x13 (SPI_FAST_FLASH_BOOT)
configsip: 0, SPIWP:0xee
clk_drv:0x00,q_drv:0x00,d_drv:0x00,cs0_drv:0x00,hd_drv:0x00,wp_drv:0x00
mode:DIO, clock div:1
load:0x3fff0030,len:XXX
...
```

| Verificação | OK |
|---|:--:|
| Bootloader responde após reset | ☐ |
| Sem mensagens de erro ou crash loops | ☐ |

> 🔴 **Se não responde:**
> - ESP32 mal soldado
> - Problema no cristal/oscilador
> - Flash corrompida (raro em módulos novos)

---

## Passo 6: Teste de Programação

1. Premir e segurar **BOOT**
2. Premir e soltar **EN** (mantendo BOOT)
3. Soltar **BOOT**
4. Upload de código de teste:

```cpp
// Blink test
void setup() {
  Serial.begin(115200);
  pinMode(2, OUTPUT);  // LED interno (se existir)
}

void loop() {
  Serial.println("Alive!");
  digitalWrite(2, HIGH);
  delay(500);
  digitalWrite(2, LOW);
  delay(500);
}
```

| Verificação | OK |
|---|:--:|
| Upload completa sem erros | ☐ |
| "Alive!" aparece no terminal | ☐ |
| LED pisca (se aplicável) | ☐ |

---

## Resumo Rápido

| Fase | Teste | Ferramenta | OK = |
|---|---|---|---|
| 1 | Visual | Olhos/lupa | Sem defeitos visíveis |
| 2 | Curtos | Multímetro | Não apita |
| 3 | Tensões | Multímetro | 5V e 3.3V correctos |
| 4 | USB | PC | Porta série aparece |
| 5 | Bootloader | Terminal | ESP32 responde |
| 6 | Programar | IDE | Upload OK |

---

## Se Falhar

| Sintoma | Causa Provável | Acção |
|---|---|---|
| Curto VBUS↔GND | Ponte solda, TVS em curto | Inspeccionar, remover TVS |
| Sem 3.3V | LDO defeituoso ou curto | Verificar LDO, medir consumo |
| USB não reconhecido | CH340C, D+/D- | Re-soldar CH340C |
| ESP32 não responde | Soldadura, alimentação | Verificar 3.3V no ESP32 |
| Upload falha | Auto-reset, BOOT/EN | Usar método manual de boot |

---

## Notas

- Primeiro teste sempre com carregador USB descartável (não MacBook!)
- Ter sempre DRC = 0 antes de fabricar
- Visualizar 3D no KiCad antes de encomendar
- Guardar este checklist junto com o projecto

---

*Criado: Janeiro 2026*
*Baseado em: Debug do clockv2 PCB*

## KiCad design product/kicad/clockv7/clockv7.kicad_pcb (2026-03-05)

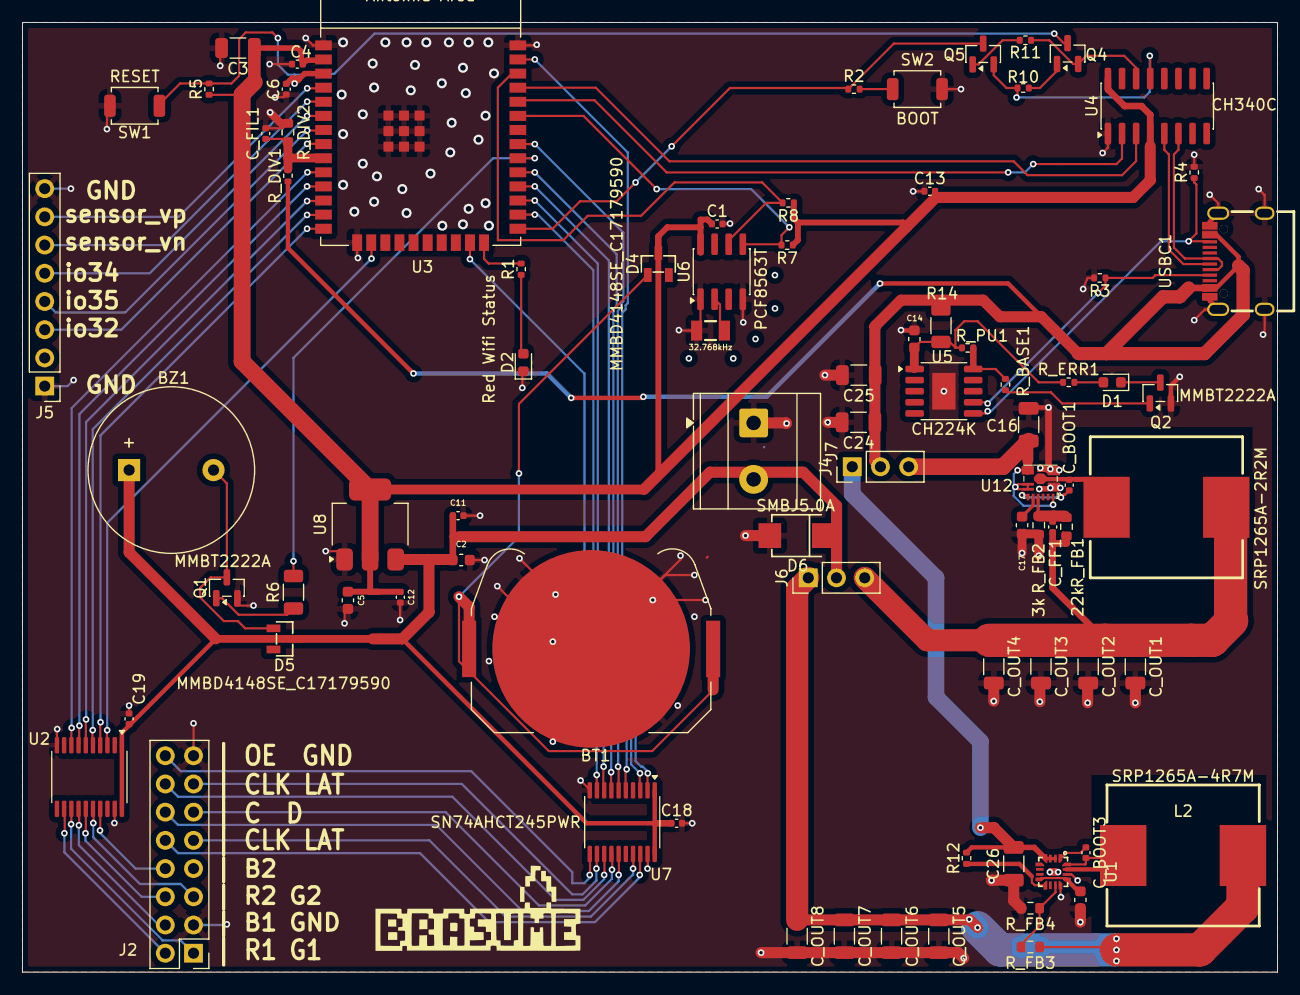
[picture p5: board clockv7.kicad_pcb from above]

Board: 2 copper layers, 113.0 x 85.5 mm, 82 parts (0 on the bottom side), 76 nets.

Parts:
BT1: Battery_Cell; BatteryHolder_Keystone_3034_1x20mm
BZ1: Buzzer; Buzzer_14x9.5RM7.6
C1, C4, C6, C11, C12, C13, C18, C19: 100nF(50V); C_0402_1005Metric
C2: 10uF; C_0603_1608Metric
C3: 22uF(10V); C_1206_3216Metric
C5: 22uF; C_0603_1608Metric
C14, C17, C27: 1uF; C_0603_1608Metric
C16, C26: 10uF; C_1206_3216Metric
C24, C25: 22uF(25V); C_1206_3216Metric
C_BOOT1, C_BOOT3: 100nF(50V); C_0402_1005Metric
C_FF1: 22pF 50V; C_0402_1005Metric
C_FIL1: 100nF(50V); C_0402_1005Metric
C_OUT1, C_OUT2, C_OUT3, C_OUT4, C_OUT5, C_OUT6, C_OUT7, C_OUT8: 22uF(25V); C_1206_3216Metric
D1: LED_ERR; LED_0603_1608Metric
D2: Red Wifi Status; LED_0603_1608Metric
D4, D5: MMBD4148SE_C17179590; SOT-23-3_L2.9-W1.3-P0.95-LS2.4-BR
D6: SMBJ5.0A; SMB_L4.6-W3.6-LS5.4-RD
J2: GPIO +5V; PinHeader_2x08_P2.54mm_Vertical
J4, J6: Conn_01x03; PinHeader_1x03_P2.54mm_Vertical
J5: GPIO +3V3; PinHeader_1x08_P2.54mm_Vertical
J7: 3.5mm; TerminalBlock_Phoenix_MKDS-3-2-5.08_1x02_P5.08mm_Horizontal
L1: SRP1265A-2R2M; IND-SMD_L13.5-W12.5
L2: SRP1265A-4R7M; IND-SMD_L13.5-W12.5
Q1, Q2, Q4, Q5: MMBT2222A; SOT-23
R1: 330R; R_0402_1005Metric
R2: 100R; R_0402_1005Metric
R3, R4: 5.1k; R_0402_1005Metric
R5, R10, R11: 10k; R_0402_1005Metric
R6, R14: 1K; R_1206_3216Metric
R7, R8: 4.7k; R_0402_1005Metric
R12: 47k; R_0402_1005Metric
R_BASE1: 10k; R_0402_1005Metric
R_DIV1: 47k; R_0402_1005Metric
R_DIV2: 5.6k; R_0603_1608Metric
R_ERR1: 330R; R_0402_1005Metric
R_FB1, R_FB3: 22k; R_0603_1608Metric
R_FB2, R_FB4: 3k; R_0603_1608Metric
R_PU1: 10k; R_0402_1005Metric
SW1: RESET; SW_SPST_TS-1088-xR025
SW2: BOOT; SW_SPST_TS-1088-xR025
U1: SY8388ARHC; QFN-16_L2.5-W2.5-P0.45-TL-EP0.6
U2, U7: SN74AHCT245PWR; TSSOP-20_4.4x6.5mm_P0.65mm
U3: ESP32-WROOM-32EN8 (8MB); ESP32-WROOM-32E
U4: CH340C; SOIC-16_3.9x9.9mm_P1.27mm
U5: CH224K; SSOP-10-1EP_3.9x4.9mm_P1mm_EP2.1x3.3mm
U6: PCF8563T; SOIC-8_3.9x4.9mm_P1.27mm
U8: AMS1117-3.3; SOT-223-3_TabPin2
U12: SY8368AQQC; QFN-12_L3.0-W3.0-P0.45-TL-EP
USBC1: TYPE-C-31-M-12; USB-C_SMD-TYPE-C-31-M-12_1
Y1: 32.768kHz; Crystal_SMD_3.2x1.5mm

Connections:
5V_BUCK1: C_FF1.1, C_OUT1.1, C_OUT2.1, C_OUT3.1, C_OUT4.1, J6.3, L1.2, R_FB1.1
5V_BUCK2: C_OUT5.1, C_OUT6.1, C_OUT7.1, C_OUT8.1, J6.1, L2.2, R_FB3.1
5V_OUT: BZ1.1 (+), C2.1, C11.1, C18.1, C19.2, D5.3, D6.1 (K), J6.2, J7.2, U2.1 (DIR), U2.20 (VCC), U7.1 (DIR), U7.20 (VCC), U8.3 (VI)
20V_BUCK1: C16.1, J4.3, U12.4 (IN), U12.5 (IN), U12.6 (IN), U12.12 (EN)
20V_BUCK2: C26.2, J4.1, R12.2, U1.2 (IN), U1.3 (IN), U1.4 (IN)
20V_OUT: C24.1, C25.1, J4.2, R14.2, R_DIV1.1, USBC1.A4B9 (VBUS), USBC1.B4A9 (VBUS)
+3V3: C1.1, C3.1, C4.1, C5.1, C12.1, C13.2, D4.3, R5.1, R7.1, R8.1, U3.2 (VDD), U4.4 (V3), U4.16 (VCC), U6.8 (VDD), U8.2 (VO)
A: U3.37 (IO23), U7.2 (A1)
A_HUB75: J2.10, U7.18 (B1)
B: U3.31 (IO19), U7.3 (A2)
B1: U2.6 (A5), U3.12 (IO27)
B1_HUB75: J2.4, U2.14 (B5)
B2: U2.3 (A2), U3.16 (IO13)
B2_HUB75: J2.8, U2.17 (B2)
BOOT: Q5.3 (C), R2.1, U3.25 (IO0)
BUZZER: R6.2, U3.30 (IO18)
B_HUB75: J2.9, U7.17 (B2)
C: U3.29 (IO5), U7.5 (A4)
CC1: R3.1, U5.7 (CC1), USBC1.A5 (CC1)
CC2: R4.1, U5.6 (CC2), USBC1.B5 (CC2)
CLK: U3.27 (IO16), U7.7 (A6)
CLK_HUB75: J2.14, U7.13 (B6)
C_HUB75: J2.12, U7.15 (B4)
D: U3.28 (IO17), U7.6 (A5)
D+: U4.5 (UD+), USBC1.A6 (DP1), USBC1.B6 (DP2)
D-: U4.6 (UD-), USBC1.A7 (DN1), USBC1.B7 (DN2)
DTR: Q5.2 (E), R10.1, U4.13 (~DTR)
D_HUB75: J2.11, U7.14 (B5)
EN: C6.2, Q4.3 (C), R5.2, SW1.1 (A), U3.3 (EN)
FB1: C_FF1.2, R_FB1.2, R_FB2.1, U12.9 (FB)
FB2: R_FB3.2, R_FB4.1, U1.11 (FB)
G1: U2.7 (A6), U3.11 (IO26)
G1_HUB75: J2.1, U2.13 (B6)
G2: U2.4 (A3), U3.14 (IO12)
G2_HUB75: J2.5, U2.16 (B3)
GND: BT1.2 (-), C1.2, C2.2, C3.2, C4.2, C5.2, C6.1, C11.2, C12.2, C13.1, C14.2, C16.2, C17.2, C18.2, C19.1, C24.2, C25.2, C26.1, C27.1, C_FIL1.2, C_OUT1.2, C_OUT2.2, C_OUT3.2, C_OUT4.2, C_OUT5.2, C_OUT6.2, C_OUT7.2, C_OUT8.2, D2.1 (K), D6.2 (A), J2.3, J2.15, J5.1, J5.8, J7.1, Q1.2 (E), Q2.2 (E), R3.2, R4.2, R_DIV2.1, R_FB2.2, R_FB4.2, SW1.2 (B), SW2.2 (B), U1.12 (BYP), U1.14 (GND), U1.17 (GND), U2.10 (GND), U2.19 (~OE), U3.1 (GND), U3.15 (GND), U3.38 (GND), U3.39 (GND), U4.1 (GND), U5.11 (GND), U6.1 (OSCI), U6.4 (VSS), U7.10 (GND), U7.19 (~OE), U8.1 (GND), U12.1 (GND), U12.3 (GND), USBC1.1 (EH), USBC1.2 (EH), USBC1.3 (EH), USBC1.4 (EH), USBC1.A1B12 (GND), USBC1.B1A12 (GND), Y1.1
L1: C_BOOT1.2, L1.1, U12.2 (LX)
L2: C_BOOT3.2, L2.1, U1.15 (LX), U1.16 (LX)
LAT: U3.26 (IO4), U7.8 (A7)
LAT_HUB75: J2.13, U7.12 (B7)
unnamed: BT1.1 (+), D4.1
unnamed: BZ1.2 (-), D5.1, Q1.3 (C)
unnamed: D1.2 (A), R_ERR1.2
unnamed: D1.1 (K), Q2.3 (C)
unnamed: D2.2 (A), R1.1
unnamed: J5.3, U3.8 (IO32)
unnamed: J5.4, U3.7 (IO35)
unnamed: J5.5, U3.6 (IO34)
unnamed: J5.6, U3.5 (SENSOR_VN)
unnamed: J5.7, U3.4 (SENSOR_VP)
unnamed: Q1.1 (B), R6.1
unnamed: Q2.1 (B), R_BASE1.2
unnamed: Q4.1 (B), R10.2
unnamed: Q5.1 (B), R11.2
unnamed: R2.2, SW2.1 (A)
unnamed: C_BOOT3.1, U1.1 (BS)
unnamed: R12.1, U1.9 (EN)
unnamed: C27.2, U1.8 (MODE), U1.13 (VCC)
unnamed: R1.2, U3.24 (IO2)
unnamed: R_BASE1.1, R_PU1.2, U5.10 (PG)
unnamed: C14.1, R14.1, R_ERR1.1, R_PU1.1, U5.1 (VDD)
unnamed: U6.2 (OSCO), Y1.2
unnamed: C_BOOT1.1, U12.7 (BS)
unnamed: C17.1, U12.8 (VCC)
OE: U3.23 (IO15), U7.9 (A8)
OE_HUB75: J2.16, U7.11 (B8)
R1: U2.8 (A7), U3.10 (IO25)
R1_HUB75: J2.2, U2.12 (B7)
R2: U2.5 (A4), U3.13 (IO14)
R2_HUB75: J2.6, U2.15 (B4)
RTS: Q4.2 (E), R11.1, U4.14 (~RTS)
RX: U3.35 (TXD0/IO1), U4.3 (RXD)
SCA: R7.2, U3.33 (IO21), U6.5 (SDA)
SCL: R8.2, U3.36 (IO22), U6.6 (SCL)
TX: U3.34 (RXD0/IO3), U4.2 (TXD)
VBUS_SENSE: C_FIL1.1, R_DIV1.2, R_DIV2.2, U3.9 (IO33)

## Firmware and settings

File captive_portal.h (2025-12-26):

#ifndef CAPTIVE_PORTAL_H
#define CAPTIVE_PORTAL_H

#include <Arduino.h>
#include <WiFi.h>
#include <ESPAsyncWebServer.h>
#include <AsyncTCP.h>
#include <DNSServer.h>
#include <Preferences.h>
#include <Dusk2Dawn.h>

// ============= CONFIGURACAO CAPTIVE PORTAL =============
#define AP_SSID "CircadianClock"
#define AP_PASS ""  // Aberta para facilitar acesso
#define SETUP_TIMEOUT 300000  // 5 minutos sem atividade
#define BUTTON_LONG_PRESS_MS 5000  // 5 segundos para entrar em setup

// Flag de debug - quando 1, permite WiFi vazio (usa credenciais de wifi_credentials.h)
#define DEBUG_MODE 1

// Valores padrao de localizacao
#define DEFAULT_LATITUDE 41.5362
#define DEFAULT_LONGITUDE -8.7813
#define DEFAULT_TIMEZONE 0
#define DEFAULT_SOLAR_OFFSET 0

// ============= ESTRUTURAS =============
struct WiFiCredentials {
  String ssid;
  String password;
};

// ============= VARIAVEIS EXTERNAS =============
// Estas variaveis sao definidas em captive_portal.cpp
extern WiFiCredentials wifiNetworks[2];
extern int NUM_WIFI_NETWORKS;

extern DNSServer dnsServer;
extern AsyncWebServer webServer;
extern bool configMode;
extern unsigned long configModeStart;

extern float configLatitude;
extern float configLongitude;
extern int configTimezone;
extern int configBrightness;
extern int configSolarOffset;  // Offset solar em horas (-12 a +12)

extern Dusk2Dawn* solarCalc;

// ============= FUNCOES =============

/**
 * Inicializa o calculador solar com as coordenadas configuradas
 */
void initSolarCalc();

/**
 * Verifica se ha configuracao WiFi guardada no NVS
 * @return true se existe configuracao, false caso contrario
 */
bool hasStoredConfig();

/**
 * Carrega configuracao do NVS para as variaveis globais
 */
void loadConfig();

/**
 * Inicia o Captive Portal (Access Point + Web Server + DNS)
 * @param display Ponteiro para o display (para mostrar feedback visual)
 */
void startCaptivePortal(void* display);

/**
 * Configura o web server com as rotas do captive portal
 */
void setupCaptiveWebServer();

/**
 * Handler para redirecionar pedidos para a pagina principal
 */
void handleCaptiveRedirect(AsyncWebServerRequest *request);

/**
 * Gera o HTML da pagina de configuracao
 * @return String com o HTML completo
 */
String getConfigPage();

/**
 * Gera o HTML da pagina de sucesso
 * @return String com o HTML completo
 */
String getSuccessPage();

/**
 * Processa o captive portal no loop (DNS requests + timeout)
 * @return true se ainda em modo config, false se timeout
 */
bool processCaptivePortal();

/**
 * Prepara o sistema para reiniciar de forma segura
 * Limpa o display (evita gibberish), desliga WiFi/mesh e reinicia
 * @param showOK se true, mostra "OK" em amber antes de reiniciar (feedback de sucesso)
 * Definida em clock.ino
 */
extern void prepareForRestart(bool showOK = false);

/**
 * Mostra animacao de preview do brilho no painel LED
 * Faz fade in/out com luz vermelha para demonstrar o brilho configurado
 * @param brightness valor de brilho (10-255)
 * Definida em clock.ino
 */
extern void previewBrightness(int brightness);

#endif // CAPTIVE_PORTAL_H

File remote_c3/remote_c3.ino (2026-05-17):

// =====================================================================
// Proto Circadian Clock - Remote Control (ESP32-C3)
// =====================================================================
// Sketch independente que se faz passar por mais um Proto Circadian
// Clock na rede mesh ESP-NOW.
//
//   * Short press: cicla modo (AUTO_SOLAR -> THERAPY_RED -> OFF -> ...)
//   * Long press em AUTO: avanca o relogio (devagar -> rapido, acelera
//     enquanto pressionado). Ao soltar, o offset final fica aplicado.
//     OLED mostra HH:MM simulado em tempo real.
//   * Long press em THERAPY_RED: cicla brightness para cima; ao chegar
//     ao topo, faz wrap para o minimo. Ao soltar, fica no valor actual.
//
// O protocolo (magic / versao / layout SyncSettings) tem de bater certo
// com clock.ino. Se mudares um, muda o outro.
// =====================================================================

#include <Arduino.h>
#include <WiFi.h>
#include <esp_now.h>
#include <esp_wifi.h>
#include <Wire.h>
#include <U8g2lib.h>

// ===================== HARDWARE PINS =====================
#define BUTTON0_PIN 9
#define LED_IOB_PIN 8     // LED on-board, activo LOW
#define OLED_SDA    5
#define OLED_SCL    6

// ===================== PROTOCOLO MESH =====================
// Tem de bater certo com clock.ino
#define MESH_CHANNEL  1
#define SYNC_MAGIC    0x50434C4B   // "PCLK"
#define SYNC_VERSION  1

#define DISCOVERY_INTERVAL_MS 30000

#define SYNC_FLAG_BRIGHTNESS    0x01
#define SYNC_FLAG_TIME_OFFSET   0x02
#define SYNC_FLAG_EPOCH         0x04

enum MeshMsgType : uint8_t {
  MSG_DISCOVERY = 0x01,
  MSG_SETTINGS  = 0x02,
  MSG_REQUEST   = 0x03,
  MSG_ACK       = 0x04
};

enum Mode : uint8_t {
  AUTO_SOLAR  = 0,
  THERAPY_RED = 1,
  MODE_OFF    = 2
};

struct __attribute__((packed)) SyncSettings {
  float    latitude;
  float    longitude;
  int8_t   timezoneOffset;
  int8_t   solarOffsetHours;
  uint8_t  mode;
  uint8_t  flags;
  uint8_t  brightness;
  int16_t  timeOffsetMin;
  uint32_t epoch;
};

struct __attribute__((packed)) MeshMessage {
  uint32_t magic;
  uint8_t  version;
  uint8_t  msgType;
  uint8_t  senderId[6];
  uint32_t firstBootTime;
  uint16_t msgId;
  union {
    SyncSettings settings;
    uint16_t     ackMsgId;
  } payload;
};

// ===================== LONG PRESS / UI =====================
#define LONG_PRESS_MS         500
#define DEBOUNCE_MS           30
#define BCAST_MIN_GAP_MS      100

// Brightness (THERAPY_RED): step + min/max + tick rate.
// Em RED queremos uma alteracao bem lenta para o utilizador ter controlo
// preciso (o painel filtra com um ramp suave por cima disto).
#define BRIGHT_STEP           6
#define BRIGHT_MIN            20
#define BRIGHT_MAX            240
#define BRIGHT_TICK_MS        260

// ===================== ESTADO =====================
static uint8_t  broadcastAddress[] = {0xFF,0xFF,0xFF,0xFF,0xFF,0xFF};
static uint8_t  deviceId[6];
// firstBootTime artificialmente ALTO: o C3 nunca deve ser eleito master.
static uint32_t myFirstBootTime = 0xFFFFFF00UL;
static uint16_t nextMsgId       = 0;

static Mode     currentMode     = AUTO_SOLAR;
static uint32_t lastDiscoveryMs = 0;
static uint32_t lastTxMs        = 0;
static uint32_t txCount         = 0;
static uint32_t rxCount         = 0;
static bool     lastSendOk      = true;

// Relogio cacheado do painel (para mostrar HH:MM no OLED).
static uint32_t cachedEpoch     = 0;
static uint32_t cachedEpochRxMs = 0;

// Preview controlado pelo long press
static int16_t  previewOffsetMin = 0;     // delta aplicado em AUTO
static uint8_t  previewBrightness = 128;  // valor cycled em RED

// LED feedback nao bloqueante
static bool     ledBlinking    = false;
static uint32_t ledBlinkUntil  = 0;

// Maquina de estados do botao
static bool     btnDown          = false;
static uint32_t btnDownAt        = 0;
static bool     longPressActive  = false;
static uint32_t nextLongTickAt   = 0;
static uint32_t lastBcastAt      = 0;
static bool     longPressDirty   = false;  // valor mudou desde ultimo broadcast?

// OLED 0.42" (72x40), rodado 180
U8G2_SSD1306_72X40_ER_F_HW_I2C u8g2(U8G2_R2, U8X8_PIN_NONE);

// ===================== HELPERS =====================
static const char* modeName(Mode m) {
  switch (m) {
    case AUTO_SOLAR:  return "AUTO";
    case THERAPY_RED: return "RED";
    case MODE_OFF:    return "OFF";
  }
  return "?";
}

static Mode nextMode(Mode m) {
  return (Mode)((uint8_t)(m + 1) % 3);
}

static void fillMessage(MeshMessage& msg, MeshMsgType type) {
  msg.magic         = SYNC_MAGIC;
  msg.version       = SYNC_VERSION;
  msg.msgType       = (uint8_t)type;
  memcpy(msg.senderId, deviceId, 6);
  msg.firstBootTime = myFirstBootTime;
  msg.msgId         = nextMsgId++;
  memset(&msg.payload, 0, sizeof(msg.payload));
}

// Calcula HH:MM "actual segundo o painel" (epoch cacheado + tempo decorrido
// desde a recepcao). Devolve true se temos relogio cacheado.
static bool computePanelHHMM(int16_t addMinutes, int& outH, int& outM) {
  if (cachedEpoch == 0) return false;
  uint32_t elapsed = (millis() - cachedEpochRxMs) / 1000UL;
  int32_t epochAdj = (int32_t)cachedEpoch + (int32_t)elapsed + (int32_t)addMinutes * 60;
  // Normalizar para "hora do dia" — assume UTC; o painel aplica o seu TZ.
  uint32_t secOfDay = ((uint32_t)epochAdj % 86400UL + 86400UL) % 86400UL;
  outH = (int)(secOfDay / 3600U);
  outM = (int)((secOfDay % 3600U) / 60U);
  return true;
}

// ===================== OLED =====================
static void drawIdleScreen() {
  u8g2.clearBuffer();
  u8g2.setFont(u8g2_font_5x8_tf);
  u8g2.drawStr(0, 7, "PCLK Remote");

  u8g2.setFont(u8g2_font_7x13B_tf);
  char line[16];
  snprintf(line, sizeof(line), "Mode:%s", modeName(currentMode));
  u8g2.drawStr(0, 22, line);

  u8g2.setFont(u8g2_font_5x8_tf);
  snprintf(line, sizeof(line), "T%lu R%lu",
           (unsigned long)txCount, (unsigned long)rxCount);
  u8g2.drawStr(0, 32, line);
  u8g2.drawStr(0, 40, lastSendOk ? "TX:OK" : "TX:FAIL");

  u8g2.sendBuffer();
}

static void drawAutoLongPressScreen() {
  u8g2.clearBuffer();
  u8g2.setFont(u8g2_font_5x8_tf);
  u8g2.drawStr(0, 7, "AUTO advance");

  // Relogio simulado em destaque
  u8g2.setFont(u8g2_font_logisoso16_tn);
  int h, m;
  char clk[8];
  if (computePanelHHMM(previewOffsetMin, h, m)) {
    snprintf(clk, sizeof(clk), "%02d:%02d", h, m);
  } else {
    snprintf(clk, sizeof(clk), "--:--");
  }
  u8g2.drawStr(0, 27, clk);

  // Offset aplicado
  u8g2.setFont(u8g2_font_5x8_tf);
  char off[16];
  int absMin = previewOffsetMin < 0 ? -previewOffsetMin : previewOffsetMin;
  snprintf(off, sizeof(off), "%c%02d:%02d",
           previewOffsetMin < 0 ? '-' : '+',
           absMin / 60, absMin % 60);
  u8g2.drawStr(0, 40, off);

  u8g2.sendBuffer();
}

static void drawRedLongPressScreen() {
  u8g2.clearBuffer();
  u8g2.setFont(u8g2_font_5x8_tf);
  u8g2.drawStr(0, 7, "RED bright");

  u8g2.setFont(u8g2_font_logisoso16_tn);
  char val[8];
  snprintf(val, sizeof(val), "%3d", (int)previewBrightness);
  u8g2.drawStr(0, 27, val);

  u8g2.setFont(u8g2_font_5x8_tf);
  char pct[16];
  snprintf(pct, sizeof(pct), "%d%%", (previewBrightness * 100) / 255);
  u8g2.drawStr(0, 40, pct);

  u8g2.sendBuffer();
}

static void drawScreen() {
  if (longPressActive) {
    if (currentMode == AUTO_SOLAR)       drawAutoLongPressScreen();
    else if (currentMode == THERAPY_RED) drawRedLongPressScreen();
    else                                  drawIdleScreen();
  } else {
    drawIdleScreen();
  }
}

// ===================== ESP-NOW CALLBACKS =====================
static void onDataSent(const uint8_t* mac, esp_now_send_status_t status) {
  (void)mac;
  lastSendOk = (status == ESP_NOW_SEND_SUCCESS);
}

static void onDataRecv(const uint8_t* mac, const uint8_t* data, int len) {
  (void)mac;
  if (len < (int)sizeof(MeshMessage)) return;
  MeshMessage msg;
  memcpy(&msg, data, sizeof(msg));
  if (msg.magic != SYNC_MAGIC || msg.version != SYNC_VERSION) return;

  rxCount++;

  if (msg.msgType == MSG_SETTINGS) {
    if (msg.payload.settings.mode < 3) {
      Mode incoming = (Mode)msg.payload.settings.mode;
      if (incoming != currentMode) {
        currentMode = incoming;
      }
    }
    // Durante long press nao deixamos o master sobrescrever o nosso preview
    // local (poderia ser uma versao mais antiga, antes do nosso ultimo step).
    bool autoLockOut = (longPressActive && currentMode == AUTO_SOLAR);
    bool redLockOut  = (longPressActive && currentMode == THERAPY_RED);
    if ((msg.payload.settings.flags & SYNC_FLAG_TIME_OFFSET) && !autoLockOut) {
      previewOffsetMin = msg.payload.settings.timeOffsetMin;
    }
    if ((msg.payload.settings.flags & SYNC_FLAG_BRIGHTNESS) && !redLockOut) {
      previewBrightness = msg.payload.settings.brightness;
    }
    if (msg.payload.settings.flags & SYNC_FLAG_EPOCH) {
      cachedEpoch     = msg.payload.settings.epoch;
      cachedEpochRxMs = millis();
    }
    if (!longPressActive) drawScreen();
  }
}

// ===================== ENVIO =====================
static void sendModeChange(Mode newMode) {
  MeshMessage msg;
  fillMessage(msg, MSG_SETTINGS);
  msg.payload.settings.mode = (uint8_t)newMode;
  esp_err_t r = esp_now_send(broadcastAddress, (uint8_t*)&msg, sizeof(msg));
  if (r == ESP_OK) { txCount++; lastTxMs = millis(); } else { lastSendOk = false; }
}

static void sendTimeOffset(int16_t offsetMin) {
  MeshMessage msg;
  fillMessage(msg, MSG_SETTINGS);
  msg.payload.settings.mode          = (uint8_t)currentMode;
  msg.payload.settings.flags         = SYNC_FLAG_TIME_OFFSET;
  msg.payload.settings.timeOffsetMin = offsetMin;
  esp_err_t r = esp_now_send(broadcastAddress, (uint8_t*)&msg, sizeof(msg));
  if (r == ESP_OK) { txCount++; lastTxMs = millis(); } else { lastSendOk = false; }
}

static void sendBrightness(uint8_t brightness) {
  MeshMessage msg;
  fillMessage(msg, MSG_SETTINGS);
  msg.payload.settings.mode       = (uint8_t)currentMode;
  msg.payload.settings.flags      = SYNC_FLAG_BRIGHTNESS;
  msg.payload.settings.brightness = brightness;
  esp_err_t r = esp_now_send(broadcastAddress, (uint8_t*)&msg, sizeof(msg));
  if (r == ESP_OK) { txCount++; lastTxMs = millis(); } else { lastSendOk = false; }
}

static void sendDiscovery() {
  MeshMessage msg;
  fillMessage(msg, MSG_DISCOVERY);
  esp_err_t r = esp_now_send(broadcastAddress, (uint8_t*)&msg, sizeof(msg));
  if (r == ESP_OK) { txCount++; lastTxMs = millis(); } else { lastSendOk = false; }
}

// ===================== ACELERACAO =====================
// Curva de aceleracao para AUTO long press: quanto mais tempo pressionado,
// maior o step e mais curto o tick.
static void autoStepSchedule(uint32_t heldMs, int& stepMin, uint32_t& tickMs) {
  uint32_t in = (heldMs > LONG_PRESS_MS) ? heldMs - LONG_PRESS_MS : 0;
  if      (in < 1000)  { stepMin = 1;  tickMs = 200; }   //   5 min/s
  else if (in < 2000)  { stepMin = 5;  tickMs = 150; }   //  33 min/s
  else if (in < 3500)  { stepMin = 15; tickMs = 100; }   // 150 min/s
  else                 { stepMin = 60; tickMs = 80;  }   // 750 min/s (~12h/min)
}

// ===================== LONG PRESS HANDLERS =====================
static void onLongPressStart() {
  longPressActive = true;
  nextLongTickAt  = millis();
  longPressDirty  = true;
  // Inicializar valor previewBrightness no valor actual conhecido
  // (mantido via recepcao de SETTINGS); se nunca vimos, fica no default 128.
}

static void onLongPressTick() {
  uint32_t now = millis();
  if ((int32_t)(now - nextLongTickAt) < 0) return;

  if (currentMode == AUTO_SOLAR) {
    uint32_t held = now - btnDownAt;
    int stepMin;
    uint32_t tickMs;
    autoStepSchedule(held, stepMin, tickMs);

    int32_t v = (int32_t)previewOffsetMin + stepMin;
    if (v >  12 * 60) v -= 24 * 60;       // wrap em ciclo de 24h
    if (v < -12 * 60) v += 24 * 60;
    previewOffsetMin = (int16_t)v;
    nextLongTickAt   = now + tickMs;
    longPressDirty   = true;
  }
  else if (currentMode == THERAPY_RED) {
    int v = (int)previewBrightness + BRIGHT_STEP;
    if (v > BRIGHT_MAX) v = BRIGHT_MIN;   // wrap para minimo
    previewBrightness = (uint8_t)v;
    nextLongTickAt   = now + BRIGHT_TICK_MS;
    longPressDirty   = true;
  }
  else {
    // OFF: nada a fazer
    nextLongTickAt = now + 200;
  }
}

static void onLongPressRelease() {
  // Aplicacao final (garante que o ultimo valor chega ao painel mesmo
  // que tenha sido bloqueado pelo throttle de broadcast).
  if (currentMode == AUTO_SOLAR) {
    sendTimeOffset(previewOffsetMin);
    Serial.printf("[REMOTE] AUTO offset final: %+d min\n", previewOffsetMin);
  } else if (currentMode == THERAPY_RED) {
    sendBrightness(previewBrightness);
    Serial.printf("[REMOTE] RED bright final: %u\n", previewBrightness);
  }
  longPressActive = false;
  longPressDirty  = false;
}

static void maybeBroadcastDuringLongPress() {
  if (!longPressDirty) return;
  uint32_t now = millis();
  if (now - lastBcastAt < BCAST_MIN_GAP_MS) return;
  lastBcastAt = now;

  if (currentMode == AUTO_SOLAR)       sendTimeOffset(previewOffsetMin);
  else if (currentMode == THERAPY_RED) sendBrightness(previewBrightness);
  longPressDirty = false;
}

// ===================== INIT =====================
static bool setupEspNow() {
  WiFi.mode(WIFI_STA);
  esp_wifi_set_promiscuous(true);
  esp_wifi_set_channel(MESH_CHANNEL, WIFI_SECOND_CHAN_NONE);
  esp_wifi_set_promiscuous(false);

  esp_read_mac(deviceId, ESP_MAC_WIFI_STA);

  if (esp_now_init() != ESP_OK) return false;
  esp_now_register_send_cb(onDataSent);
  esp_now_register_recv_cb(onDataRecv);

  esp_now_peer_info_t peer{};
  memcpy(peer.peer_addr, broadcastAddress, 6);
  peer.channel = MESH_CHANNEL;
  peer.encrypt = false;
  esp_now_del_peer(broadcastAddress);
  if (esp_now_add_peer(&peer) != ESP_OK) return false;
  return true;
}

void setup() {
  Serial.begin(115200);
  delay(50);

  pinMode(LED_IOB_PIN, OUTPUT);
  digitalWrite(LED_IOB_PIN, HIGH);

  pinMode(BUTTON0_PIN, INPUT_PULLUP);

  Wire.begin(OLED_SDA, OLED_SCL);
  u8g2.begin();

  bool ok = setupEspNow();
  Serial.printf("[REMOTE] ESP-NOW %s, MAC %02X:%02X:%02X:%02X:%02X:%02X\n",
                ok ? "OK" : "FAIL",
                deviceId[0], deviceId[1], deviceId[2],
                deviceId[3], deviceId[4], deviceId[5]);

  if (ok) sendDiscovery();
  lastDiscoveryMs = millis();
  drawScreen();
}

// ===================== LOOP =====================
void loop() {
  uint32_t now = millis();

  // Fim do blink do LED
  if (ledBlinking && (int32_t)(now - ledBlinkUntil) >= 0) {
    ledBlinking = false;
    digitalWrite(LED_IOB_PIN, HIGH);
  }

  // Polled debounce + state machine do botao
  static uint32_t lastEdgeAt = 0;
  bool raw = (digitalRead(BUTTON0_PIN) == LOW);
  if (raw != btnDown && (now - lastEdgeAt) > DEBOUNCE_MS) {
    lastEdgeAt = now;
    if (raw) {
      // Press
      btnDown   = true;
      btnDownAt = now;
    } else {
      // Release
      btnDown = false;
      if (longPressActive) {
        onLongPressRelease();
        drawScreen();
      } else {
        // Short press => cicla modo
        currentMode = nextMode(currentMode);
        sendModeChange(currentMode);
        // Pisca LED 200ms para feedback
        ledBlinking   = true;
        ledBlinkUntil = now + 200;
        digitalWrite(LED_IOB_PIN, LOW);
        Serial.printf("[REMOTE] short -> %s\n", modeName(currentMode));
        drawScreen();
      }
    }
  }

  // Long press: deteccao + ticks
  if (btnDown && !longPressActive && (now - btnDownAt) >= LONG_PRESS_MS) {
    onLongPressStart();
    Serial.printf("[REMOTE] long start (%s)\n", modeName(currentMode));
    drawScreen();
  }
  if (btnDown && longPressActive) {
    onLongPressTick();
    maybeBroadcastDuringLongPress();
    // Redesenhar OLED ~30Hz para o relogio nao parecer congelado.
    static uint32_t lastDrawMs = 0;
    if (now - lastDrawMs >= 33) {
      lastDrawMs = now;
      drawScreen();
    }
  }

  // Discovery periodico
  if (now - lastDiscoveryMs >= DISCOVERY_INTERVAL_MS) {
    lastDiscoveryMs = now;
    sendDiscovery();
  }
}

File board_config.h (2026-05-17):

/**
 * ============================================================
 * BOARD CONFIGURATION - Compilação Condicional
 * ============================================================
 *
 * Define a placa alvo antes de incluir este ficheiro:
 *
 *   #define BOARD_MATRIXPORTAL_S3 1   // Adafruit Matrix Portal S3
 *   #define BOARD_MATRIXPORTAL_S3 0   // ESP32 Dev Module genérico
 *
 * Ou define via platformio.ini / Arduino IDE:
 *   -DBOARD_MATRIXPORTAL_S3=1
 *
 * ============================================================
 */

#ifndef BOARD_CONFIG_H
#define BOARD_CONFIG_H

// ============================================================
// SELEÇÃO DE PLACA (alterar aqui ou via build flags)
// ============================================================
// NOTA: vamos abandonar o Matrix Portal S3. Toda a produção e
// desenvolvimento ativo a partir daqui é no ESP32 Dev Module
// (BOARD_MATRIXPORTAL_S3 = 0). O caminho S3 fica no código apenas
// como referência histórica e pode ser removido em qualquer momento
// sem aviso. Não dependas dele para features novas.
#ifndef BOARD_MATRIXPORTAL_S3
  #define BOARD_MATRIXPORTAL_S3 0  // 0 = ESP32 Dev Module (default), 1 = Matrix Portal S3 (DEPRECATED)
#endif

// ============================================================
// VALIDAÇÃO E INFO
// ============================================================
#if BOARD_MATRIXPORTAL_S3
  #define BOARD_NAME "Adafruit Matrix Portal S3"
  #define BOARD_MCU  "ESP32-S3"
#else
  #define BOARD_NAME "ESP32 Dev Module"
  #define BOARD_MCU  "ESP32"
#endif

// ============================================================
// PINOUT HUB75 (Display LED Matrix)
// ============================================================
#if BOARD_MATRIXPORTAL_S3
  // Matrix Portal S3 - Pinos fixos na PCB
  // Ref: https://learn.adafruit.com/adafruit-matrixportal-s3/pinouts
  #define R1_PIN  42
  #define G1_PIN  41
  #define B1_PIN  40
  #define R2_PIN  38
  #define G2_PIN  39
  #define B2_PIN  37
  #define A_PIN   45
  #define B_PIN   36
  #define C_PIN   48
  #define D_PIN   35
  #define E_PIN   21   // Para matrizes 64x64 (jumper na PCB)
  #define LAT_PIN 47
  #define OE_PIN  14
  #define CLK_PIN 2
#else
  // ESP32 Dev Module - Pinout original do projeto
  #define R1_PIN  25
  #define G1_PIN  26
  #define B1_PIN  27
  #define R2_PIN  14
  #define G2_PIN  12
  #define B2_PIN  13
  #define A_PIN   23
  #define B_PIN   19
  #define C_PIN   5
  #define D_PIN   17
  #define E_PIN   -1   // Não usado em painéis 32x16
  #define LAT_PIN 4
  #define OE_PIN  15
  #define CLK_PIN 16
#endif

// ============================================================
// PINOUT I2C (RTC DS3231 e sensores)
// ============================================================
#if BOARD_MATRIXPORTAL_S3
  // Matrix Portal S3 - STEMMA QT connector
  // Ref: pins_arduino.h do ESP32-S3
  // NOTA: O acelerómetro LIS3DH integrado usa endereço 0x19
  #define I2C_SDA_PIN 16
  #define I2C_SCL_PIN 17

  // Endereço do acelerómetro integrado (reservado)
  #define LIS3DH_I2C_ADDR 0x19
#else
  // ESP32 Dev Module - Pinos I2C padrão
  #define I2C_SDA_PIN 21
  #define I2C_SCL_PIN 22
#endif

// ============================================================
// BOTÕES
// ============================================================
#if BOARD_MATRIXPORTAL_S3
  // Matrix Portal S3 - 2 botões dedicados (sem pull-up interno!)
  #define BUTTON_PIN      6   // Botão UP (principal para mudar modo)
  #define BUTTON_UP_PIN   6   // Alias
  #define BUTTON_DOWN_PIN 7   // Botão DOWN (funcionalidade extra)
  #define BUTTON_COUNT    2
  #define BUTTON_ACTIVE_LOW true
  #define BUTTON_NEEDS_PULLUP true  // Sem resistência de pull-up na PCB
#else
  // ESP32 Dev Module - Botão BOOT
  #define BUTTON_PIN      0   // GPIO0 (BOOT button)
  #define BUTTON_COUNT    1
  #define BUTTON_ACTIVE_LOW true
  #define BUTTON_NEEDS_PULLUP true
#endif

// ============================================================
// NEOPIXEL / LED DE STATUS
// ============================================================
#if BOARD_MATRIXPORTAL_S3
  // Matrix Portal S3 - NeoPixel RGB integrado
  #define HAS_NEOPIXEL      true
  #define NEOPIXEL_PIN      4
  #define NEOPIXEL_COUNT    1
  #define NEOPIXEL_TYPE     (NEO_GRB + NEO_KHZ800)  // WS2812B

  // LED D13 também disponível
  #define LED_BUILTIN_PIN   13
  #define HAS_LED_BUILTIN   true
#else
  // ESP32 Dev Module - Apenas LED azul (se disponível)
  #define HAS_NEOPIXEL      false
  #define NEOPIXEL_PIN      -1

  // LED integrado (varia por modelo de placa)
  #define LED_BUILTIN_PIN   2   // Comum em ESP32 DevKit
  #define HAS_LED_BUILTIN   true
#endif
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

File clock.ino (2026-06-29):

#include <P10_32x16_QuarterScan.h> //https://github.com/filipe3x/P10_32x16_QuarterScan
#include <RTClib.h>
#include <WiFi.h>
#include <esp_now.h>
#include <esp_wifi.h>
#include <Preferences.h>
#include <Dusk2Dawn.h>
#include <driver/adc.h>       // adc1_get_raw, adc1_config_width, adc1_config_channel_atten
#include <esp_adc_cal.h>      // Calibração ADC do ESP32 (corrige não-linearidade abaixo de ~0.8V)
#include "board_config.h"     // Configuração de placa (DEVE vir antes dos outros headers)
#include "captive_portal.h"   // Modulo do captive portal
#include "auto_solar.h"       // Modulo de calculo solar
#include "sound.h"            // Motor chiptune LSDJ-inspirado

// ============= PINOUT =============
// Agora definido em board_config.h com compilação condicional
// Para alterar a placa, editar BOARD_MATRIXPORTAL_S3 em board_config.h
// ou passar -DBOARD_MATRIXPORTAL_S3=1 como build flag

// ============= DISPLAY =============
MatrixPanel_I2S_DMA *dma_display = nullptr;
P10_32x16_QuarterScan *display = nullptr;

// ============= CONFIGURACAO RTC =============
RTC_DS3231 rtc;
bool rtcAvailable = false;

// ============= CONFIGURACAO WIFI MULTI-SSID =============
const int WIFI_TIMEOUT_MS = 10000;  // 10s por rede
const int WIFI_RETRY_PER_NETWORK = 2;  // Tentar cada rede 2x

// ============= STATUS DO SISTEMA =============
enum SystemStatus {
  STATUS_RTC_WIFI_NTP,      // 🟢 VERDE - Perfeito
  STATUS_WIFI_NTP,          // 🔵 AZUL - Bom
  STATUS_RTC_WIFI,          // 🟡 AMARELO - OK
  STATUS_RTC_ONLY,          // 🟣 ROXO - Funcional
  STATUS_WIFI_ONLY,         // 🟠 LARANJA - Limitado
  STATUS_OFFLINE            // 🔴 VERMELHO - Crítico
};

SystemStatus currentStatus = STATUS_OFFLINE;

// ============= LOCALIZACAO =============
// Configuracoes dinamicas em captive_portal.h: configLatitude, configLongitude, configTimezone, configSolarOffset
// Usar referencias para as variaveis do modulo captive_portal
#define LATITUDE configLatitude
#define LONGITUDE configLongitude
#define TIMEZONE_OFFSET configTimezone
#define SOLAR_OFFSET_HOURS configSolarOffset

// ============= DEVICE ID UNICO =============
// O ESP32 tem um eFuse de 64 bits unico de fabrica
// Usamos 6 bytes (48 bits) como ID principal
// Combinamos com um hash do MAC BT como fallback para garantir unicidade
uint8_t deviceId[6];
char deviceIdStr[18];  // "XX:XX:XX:XX:XX:XX\0"
Preferences preferences;

// ============= MESH SYNC (ESP-NOW) =============
// Estrutura para sincronizacao entre dispositivos Proto Circadian Clock
#define MESH_CHANNEL 1
#define SYNC_MAGIC 0x50434C4B  // "PCLK" - Proto CLock
#define SYNC_VERSION 1
#define BROADCAST_INTERVAL_MS 30000  // Broadcast a cada 30s (quando ativo)
#define ACK_TIMEOUT_MS 500
#define MAX_PEERS 10

// Configuracao do modo hibrido (economia de energia)
#define MESH_SCAN_INTERVAL_MS 60000   // Scan a cada 60s quando sozinho
#define MESH_SCAN_DURATION_MS 3000    // 3s de escuta durante scan normal
#define MESH_INITIAL_SCAN_MS 65000    // 65s no primeiro scan (> 1 ciclo completo)
#define MESH_IDLE_TIMEOUT_MS 300000   // 5 min sem peers = desligar mesh

// ============= VBUS SENSING =============
#define VBUS_SENSE_PIN     33             // IO33 / GPIO33 (ADC1_CH5 no ESP32)
#define VBUS_SENSE_CHANNEL ADC1_CHANNEL_5 // GPIO33 = ADC1_CH5 no ESP32 clássico
#define ERROR_LED_PIN      2
#define VDIV_RATIO         ((47.0f + 5.6f) / 5.6f)  // 9.393
#define VBUS_20V_MIN       17.0f   // Limiar: 19.7V real → margem para 15V fallback
#define VBUS_LOG_INTERVAL_MS  30000  // Log a cada 30s

static esp_adc_cal_characteristics_t adc_chars;  // Curva de calibração calculada no setup()

// Estados do mesh (maquina de estados hibrida)
enum MeshState {
  MESH_OFF,       // WiFi desligado, a poupar energia
  MESH_SCANNING,  // A procurar peers (WiFi ON temporario)
  MESH_ACTIVE     // Peers encontrados, mesh sempre ativo
};

MeshState meshState = MESH_OFF;
unsigned long lastScanTime = 0;
unsigned long lastPeerActivity = 0;
bool isFirstScan = true;  // Primeiro scan e mais longo

// Endereco broadcast ESP-NOW
uint8_t broadcastAddress[] = {0xFF, 0xFF, 0xFF, 0xFF, 0xFF, 0xFF};

// Tipos de mensagem
enum MeshMsgType {
  MSG_DISCOVERY = 0x01,    // Anuncio de presenca
  MSG_SETTINGS = 0x02,     // Broadcast de definicoes (do master)
  MSG_REQUEST = 0x03,      // Pedido de definicoes (de um slave)
  MSG_ACK = 0x04           // Confirmacao de recepcao
};

// Flags de campos opcionais carregados em SyncSettings (extensoes do remoto C3)
#define SYNC_FLAG_BRIGHTNESS    0x01
#define SYNC_FLAG_TIME_OFFSET   0x02
#define SYNC_FLAG_EPOCH         0x04

// Estrutura de definicoes sincronizaveis
struct __attribute__((packed)) SyncSettings {
  float latitude;
  float longitude;
  int8_t timezoneOffset;
  int8_t solarOffsetHours;
  uint8_t mode;            // AUTO_SOLAR, THERAPY_RED, OFF
  uint8_t flags;           // SYNC_FLAG_* (campos validos abaixo)
  uint8_t brightness;      // 0-255 (se SYNC_FLAG_BRIGHTNESS)
  int16_t timeOffsetMin;   // delta de minutos para solar (se SYNC_FLAG_TIME_OFFSET)
  uint32_t epoch;          // unix time do remetente (se SYNC_FLAG_EPOCH)
};

// Offset de tempo aplicado pelo remoto (long press em AUTO no comando C3)
static int16_t remoteTimeOffsetMin = 0;

// Ramps nao-bloqueantes para suavizar comandos vindos do remoto.
//
// Brightness:  step de 2 a cada 15ms => ~133 u/s. Cobre um jump de 6
// unidades (passo do C3) em 45ms, e 0->255 em ~2s.
// Time offset: step de 1 minuto a cada 25ms => 40 min/s. Cobre um jump
// de 60 min (passo maximo do C3) em 1.5s.
#define BRIGHTNESS_RAMP_STEP         2
#define BRIGHTNESS_RAMP_INTERVAL_MS  15
#define AUTO_OFFSET_RAMP_STEP        1
#define AUTO_OFFSET_RAMP_INTERVAL_MS 25

static int16_t brightnessRampTarget = -1;          // -1 => sem ramp pendente
static unsigned long brightnessRampLastMs = 0;
static int16_t timeOffsetRampTarget = 0;           // valor desejado de offset
static unsigned long timeOffsetRampLastMs = 0;

// Estrutura de mensagem ESP-NOW
struct __attribute__((packed)) MeshMessage {
  uint32_t magic;          // Identificador PCLK
  uint8_t version;         // Versao do protocolo
  uint8_t msgType;         // Tipo de mensagem
  uint8_t senderId[6];     // ID do remetente
  uint32_t firstBootTime;  // Timestamp da primeira instalacao (segundos desde 2020)
  uint16_t msgId;          // ID da mensagem para ACKs
  union {
    SyncSettings settings; // Para MSG_SETTINGS
    uint16_t ackMsgId;     // Para MSG_ACK - ID da mensagem confirmada
  } payload;
};

// Estado do mesh
bool meshEnabled = false;
bool isMaster = false;
uint32_t myFirstBootTime = 0;
uint16_t nextMsgId = 0;
unsigned long lastBroadcast = 0;

// Tabela de peers conhecidos
struct PeerInfo {
  uint8_t id[6];
  uint32_t firstBootTime;
  unsigned long lastSeen;
  bool active;
};
PeerInfo knownPeers[MAX_PEERS];
int numPeers = 0;

// Fila de ACKs pendentes
struct PendingAck {
  uint16_t msgId;
  uint8_t targetId[6];
  unsigned long sentTime;
  bool waiting;
};
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

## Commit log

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2025-12-26 Add instant mode sync and collision-free ACKs
    - Broadcast mode change immediately on button press (before animation)
    - Any device can trigger mode sync (not just master)
    - ACKs use slot-based backoff to prevent collision storms
    - Receivers apply mode instantly without animation for fast feedback
    - Add MeshSync.md documentation explaining the protocol
    [clock.ino]
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2025-12-26 Add initial long scan (65s) to guarantee peer discovery
    Problem: If two devices scan at different phases, they might never
    overlap and never discover each other.
    Solution: First scan after boot is 65s (longer than the 60s interval),
    guaranteeing it will catch at least one full cycle from any other device.
    - Add MESH_INITIAL_SCAN_MS = 65000 (65 seconds)
    - Add isFirstScan flag to track first boot scan
    - Send discovery every 10s during initial scan
    - Subsequent scans remain 3s for power efficiency
    - Update MeshSync.md with scan timing documentation
    [clock.ino]
2025-12-26 Update documentation with mesh sync details
    - Add Mesh Sync section to Claude.md with key features
    - Update dependencies list with esp_now, esp_wifi, Preferences
    - Add mesh limitation note (same WiFi channel required)
    - Update MeshSync.md to reflect hybrid mode implementation
    - Fix power consumption summary (24mA alone, 95mA with peers)
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2025-12-26 Add comprehensive auto_solar module documentation
    Document the solar gradient calculation algorithms with:
    - NOAA solar position algorithm with mathematical formulas
    - Tanner Helland color temperature to RGB conversion
    - Elevation-to-color mapping based on astronomical definitions
    - Scientific references for circadian impact
    - Future improvement proposals including:
    - Long press brightness adjustment
    - Atmospheric correction
    - Melanopic lux curves
    - Age compensation
    - Jet lag mode
2025-12-26 Fix ESP-NOW callback signature for ESP32 Arduino 2.0.x
    The esp_now_recv_info_t struct only exists in ESP32 Arduino 3.x
    (ESP-IDF 5.x). The 2.0.x versions use the older callback signature
    with const uint8_t *mac_addr directly.
    Changed onDataRecv from:
    void onDataRecv(const esp_now_recv_info_t *info, ...)
    To:
    void onDataRecv(const uint8_t *mac_addr, ...)
    [clock.ino]
2025-12-26 Add version requirements and authors to README
    - Document ESP32 Arduino 2.0.x requirement (tested with 2.0.14)
    - Explain why 3.x is not supported (HUB75 library incompatibility with ESP-IDF 5.x I2S/DMA APIs)
    - Add version column to libraries table
    - Add Authors section with contributors
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2025-12-26 Improve WiFi symbol design on setup screen
    Replace WiFi arcs with mobile network-style signal bars (ascending
    left to right) and add "Wifi" label in amber next to the bars.
    [clock.ino]
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2025-12-26 Replace GPS button with city dropdown and translate UI to English
    - Translate entire captive portal interface from Portuguese to English
    - Replace non-functional GPS button (requires HTTPS) with city dropdown
    - Add 40+ cities organized by country/region for easy location selection
    - Include Portuguese cities: Lisbon, Cascais, Porto, Braga, Esposende, Coimbra, Faro
    - Keep lat/lon fields editable for manual coordinate entry
    - Cities auto-populate coordinates when selected
    - Translate success page to English
    [captive_portal.cpp]
2025-12-26 Add safe restart function to prevent display gibberish on reboot
    - Add prepareForRestart() function that clears display before restart
    - Shows graceful "OK" animation with fade in/out after config save
    - Fades out display brightness to zero before ESP.restart()
    - Stops mesh/WiFi cleanly before reboot
    - Replaces all direct ESP.restart() calls with prepareForRestart()
    This prevents the random pixel gibberish at max brightness that
    occurred during abrupt resets after captive portal configuration.
    [captive_portal.cpp, captive_portal.h, clock.ino]
2025-12-26 Fix compilation errors in prepareForRestart()
    - Remove duplicate default argument (keep only in header)
    - Replace getBrightness() with configBrightness variable
    [clock.ino]
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2025-12-26 Add comprehensive PCB design guide with protection circuits
    - Complete BOM with 40+ components
    - Protection circuits: reverse polarity, overcurrent, ESD, overvoltage
    - Software recommendations (KiCad 8 preferred)
    - Layout guidelines for ESP32 antenna and power
    - Manufacturing specs and cost estimates
2025-12-26 Fix scroll issue when using brightness slider on mobile
    [captive_portal.cpp]
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2025-12-27 Improve brightness validation and adopt configBrightness in red therapy
    - Add constrain(10, 255) validation on /save endpoint to prevent
    invalid brightness values from being stored in NVS
    - Use configBrightness in displayTherapyRed() instead of hardcoded 100,
    capped at 240 to prevent visual discomfort and excessive 5V consumption
    [captive_portal.cpp, clock.ino]
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2025-12-28 Add USB-UART bridge and auto-reset circuit documentation
    - Add section 1.11 with CH340C USB-UART bridge details
    - Document UMH3N dual transistor for simplified auto-reset
    - Include complete pinout diagrams and wiring
    - Explain DTR/RTS sequence for automatic firmware upload
2025-12-29 Add USB-C power delivery design for Circadian Clock v2
    Introduces a new power supply architecture based on the Adafruit Matrix
    Portal S3 design and Raspberry Pi 5 power model. The document covers:
    - Two strategies: Direct 5V/5A and High Voltage (9-20V) + Buck converter
    - Analysis of USB PD 5V/5A availability challenges
    - Software workarounds (brightness limiting, dynamic content adjustment)
    - Hardware workarounds (bulk capacitors, soft-start circuits)
    - Screw terminal design for panel power distribution
    - PD controller options (CYPD3177, IP2721, FUSB302B)
    - Complete BOM for both strategies
    - Firmware code for automatic power profile detection
    The goal is to simplify the PCB by using extern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
2025-12-29 Update POWER_SUPPLY_v2.md based on MatrixPortal S3 schematic analysis
    - Replace AMS1117 with AP2112K-3.3 (better dropout, enable pin, used by Adafruit)
    - Add power indicator LEDs section (5V and 3.3V status LEDs)
    - Add BOM for 3.3V regulator and LEDs
    - Add reference to MatrixPortal S3 schematic analysis findings
    - Confirm MatrixPortal S3 uses simple 5V passthrough (no PD controller)
    - Update version to 2.1
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2025-12-30 Update PCB design guide with USB-C power and protection from POWER_SUPPLY_v2
    - Add USB-C Power Delivery architecture (Strategy A: 5V direct, Strategy B: High voltage + Buck)
    - Update section 1.2 with AP2112K LDO, IP2721 PD controller, MP1584EN buck converter
    - Add comprehensive USB-C protection in section 1.3 (D3V3XA4B10LP for D+/D-/CC, SMBJ5.0A for VBUS)
    - Add screw terminal reverse polarity protection with Si2301CDS P-MOSFET
    - Add inrush current limiting section 2.6 (NTC thermistor and P-MOSFET soft-start)
    - Add terminal protection section 2.7
    - Update block diagrams section 3 with both power strategies
    - Add USB-C Power BOM summary in section 6.3
    - Cross-reference with POWER_SUPPLY_v2.md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
2026-01-01 Add buzzer/startup sound feature to documentation
    Features added:
    - MLT-5030 piezo buzzer support for 8-bit chiptune sounds
    - Retro NES/GameBoy style audio capabilities
    - Configurable via captive portal (enable/disable)
    - Future alarm/notification sound support
    Documentation updates:
    - README.md: Added buzzer to features, hardware requirements, and wiring
    - PCB_DESIGN_GUIDE.md: Complete BOM, circuit design, and implementation details
    Technical specs:
    - GPIO 10 with PWM support
    - 2N2222 NPN driver transistor
    - 1N4148 flyback protection diode
    - Supports pulse waves, arpeggios, pitch bends, vibrato
2026-01-01 Fix buzzer GPIO from 10 to 18 (ESP32 flash SPI conflict)
    Issue: GPIO 10 is internally used by ESP32-WROOM-32E flash SPI
    and is not available for external use.
    Solution: Changed to GPIO 18 which is:
    - Free and available
    - Supports PWM via LEDC
    - Not a strapping pin
    - No special internal functions
    Changes:
    - Updated all references from GPIO 10 to GPIO 18
    - Added note explaining GPIO 6-11 are reserved for flash SPI
    - Updated circuit diagrams and code examples
2026-01-01 Update PCB_DESIGN_GUIDE.md to version 1.2 with buzzer changelog
    - Updated version from 1.1 to 1.2
    - Updated last update date to January 2026
    - Added comprehensive changelog entry for buzzer feature:
    - Section 1.8: Buzzer e Audio (MLT-5030)
    - Section 2.6: Complete circuit with code examples
    - GPIO 18 assignment
    - Retro chiptune capabilities
    - Captive portal configuration
    Version history now tracks all major additions.
    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
2026-01-01 Merge buzzer feature with USB-C power protection (v2.0 → v2.1)
    Consolidated changes from claude/update-pcb-power-protection-MTaqD
    with buzzer/startup sound feature.
    New in v2.1:
    - Section 1.8: Buzzer and Audio (MLT-5030 with 2N2222 driver)
    - GPIO 18 (GPIO 6-11 unavailable - flash SPI)
    - Complete BOM: BZ1, Q2, R11, D4
    - LCSC code: C95297
    - Alternatives: PKM13EPYH4000, CMT-5023S-SMT
    - Section 2.6: Complete buzzer circuit with NPN driver
    - PWM code examples with retro chiptune melodies
    - Techniques: Pulse waves, arpeggios, pitch bend, vibrato
    - PCB layout tips
    - Renumbered sections for consistency:
    - 1.8→1.9 (Connectors)
    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
2026-01-01 Create separate v2.1 file and revert PCB_DESIGN_GUIDE to v2.0
    - Created product/PCB_DESIGN_GUIDE_v2.1.md with buzzer feature (complete version)
    - Reverted product/PCB_DESIGN_GUIDE.md to v2.0 (USB-C power, no buzzer)
    - v2.1 preserves all buzzer documentation for future reference
    - v2.0 maintains clean USB-C power protection baseline
2026-01-01 Update PCB_DESIGN_GUIDE to v2.1 and remove separate v2.1 file
    Consolidates the v2.1 content (buzzer/audio section) into the main
    PCB_DESIGN_GUIDE.md file, removing the separate v2.1 file.
2026-01-02 Add component alternatives guide for JLCPCB stock issues
    Document alternatives for 5 unavailable/extended parts:
    - BZ1: CMT-7525 → MLT-5030 (C95297)
    - D2: YLED0805R → C2286 red LED
    - F1: JK-NSMD050 → SMD1206P050TF/15 (C106264)
    - J2: CRITICAL BOM ERROR - wrong part type (MOSFET vs header)
    - U6: AP2112K → ME6211C33M5G-N (C82942)
    All recommended parts are JLCPCB basic/available stock.
2026-01-02 Fix J2 pin header LCSC part number
    C3408481 was a resistor - corrected to C68234 (BOOMELE 2x8 2.54mm header)
2026-01-02 Update buzzer alternatives - MLT-5030 out of stock
    - MLT-5030 (C95297) marked as OOS
    - Added passive buzzer alternatives: HYG9605C, KLJ-1102, GPC12075YB-5V
    - Warning: TMB12A05 is ACTIVE buzzer (incompatible with PWM driver)
    - Updated recommendation to HYG9605C (C438342)
2026-01-02 Fix screw terminal LCSC part number
    C430646 was wrong (5-pin DORABO) - corrected to C474881 (KF301-5.0-2P 2-pin)
    Updated: COMPONENT_ALTERNATIVES.md, PCB_DESIGN_GUIDE.md, POWER_SUPPLY_v2.md
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2026-01-02 Add verified BOM with footprint dimensions and fixes
    New file: BOM_VERIFIED.md with exhaustive component list
    Critical issues found:
    - C3: Footprint 0805 but component is 1206 (MISMATCH)
    - D2: Footprint 0402 but component is 0603 (MISMATCH)
    - J1: Wrong LCSC C49261569 (Hanxia) → C3020560 (GCT USB4105)
    All 24 components verified with dimensions and LCSC codes.
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2026-01-02 Update RTC documentation with correct RST pin info
    - BOM_VERIFIED.md: Add RTC components section with LCSC codes
    (DS3231SN, 4.7kΩ pull-ups, 100nF bypass, CR2032 holder)
    - PCB_DESIGN_GUIDE.md: Add section 2.7 with complete RTC circuit
    - Correct pinout and schematic
    - Note: ~RST has internal 50kΩ pull-up (no external needed)
    - GPIO mappings for ESP32 Dev and Matrix Portal S3
    - RTC_MODULE_BOM.md: Fix RST pin documentation
    - RST pin 4: NC (internal pull-up)
    - INT/SQW pin 3: NC for normal use
    - Added important notes section
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2026-01-03 Replace BZ1 buzzer: GPC12075YB-5V (C252948) → TMB12A05 (C96093)
    JLCPCB reported C252948 out of stock and footprint mismatch.
    TMB12A05 is a drop-in replacement with matching specs:
    - Same Ø12mm diameter
    - Same 7.6mm pin pitch
    - Same 5V active buzzer type
    - THT package matches Buzzer_12x9.5RM7.6 footprint
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2026-01-03 Fix PCF8563 cost analysis: external crystal is Extended (+$3)
    The 32.768kHz crystal (C32346) required by PCF8563T is also
    Extended, which negates the $0 Preferred fee advantage.
    Corrected analysis:
    - DS3231SN: $2.37 component + $3 fee = $5.37/lot
    - PCF8563T + Crystal: $0.45 component + $3 fee = $3.45/lot
    - Real savings: ~$2/lot (not $5 as initially estimated)
    Updated recommendation:
    - Prototypes: Keep DS3231SN (simpler, no footprint change needed)
    - Production (>50 units): Consider PCF8563T for component cost savings
2026-01-03 Correct RTC analysis: Crystal C32346 is BASIC (not Extended)
    Major cost correction:
    - Crystal Q13FC13500004 (C32346) is BASIC = $0 fee
    - PCF8563T is Preferred Extended = $0 fee
    - Combined: $0 Extended fees!
    Updated cost analysis:
    - PCF8563T + Crystal: $0.45 component + $0 fee = $0.45/lot
    - Real savings: ~$5/lot (not $2 as previously stated)
    For 50 lots: $250 savings!
    Strong recommendation to switch to PCF8563T + Crystal
    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
2026-01-06 Update PSU v3: Replace CH224K with IP2721 + AO3400A
    - IP2721 (C603176): PD trigger with SEL pin for voltage config
    - AO3400A (C20917): N-MOSFET for power-path control via VBUSG
    - SRV05-4 (C558418): 4-channel ESD protection (Basic stock)
    - SMAJ24A-13-F (C134973): 24V TVS for VBUS (Basic stock)
    - Automatic fallback: 20V → 15V → 12V → 9V → 5V
    - Total cost ~€4.00, most components in Basic stock
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2026-01-13 Add PCB debug checklist for new boards
    Checklist to verify PCB functionality when receiving from manufacturer:
    - Visual inspection
    - Continuity tests (shorts detection)
    - Power rail verification
    - USB recognition
    - ESP32 bootloader response
    - Programming test
    Based on lessons learned from clockv2 PCB debugging.
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2026-01-14 Fix inconsistencies in POWER_SUPPLY_v3.md
    - IP2721 package: SOP-16 → TSSOP-16 (correct)
    - Replace CH224K references with IP2721 (was wrong IC)
    - Fix VIN connection description (after MOSFET, not VBUS)
    - Update PTC Fuse to C2982291 (3A/30V, 2920 package)
    - Update datasheet references to IP2721
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2026-01-14 Update PSU docs with J_MODE 3-pin jumper for bypass
    - Replace J_BYPASS (2-pin) with J_MODE (1x3) for mode selection
    - Document bypass limitations (Buck dropout with 5V input)
    - Add detailed J_MODE wiring and operation modes
    - Update KiCad guide with new jumper connections
    - Clarify IP2721 behavior with basic USB 5V chargers
2026-01-14 Redesign J_MODE for clean 5V bypass without Buck dropout
    - Pino 1: F1 saída (bypass direto)
    - Pino 2: 5V cargas (saída comum)
    - Pino 3: Buck VOUT (saída regulada)
    This elegant configuration provides:
    - Normal mode (2-3): Buck VOUT → cargas, F1 isolated
    - Bypass mode (1-2): F1 → cargas directly, Buck has no input (VOUT=0V)
    - Clean 5V in bypass without Buck dropout!
    Added safety warning for incorrect jumper usage with PD sources.
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2026-01-15 Fix L1 inductor LCSC code: C7187315 (CXP0630-2R2M-AG)
    - Previous C132462 was wrong (it's a connector, not inductor!)
    - New inductor: DMBJ CXP0630-2R2M-AG, 2.2µH, 10A
    - Package: 6.6x7mm molded
    - Stock: Extended (not Basic as previously stated)
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2026-01-15 Update BOM with correct LCSC codes for feedback resistors
    - R_FB1: 22kΩ 0603 → C31850 (Basic)
    - R_FB2: 3kΩ 0603 → C4211 (Basic)
    - Add C_VCC 1µF for internal LDO bypass
    - Add 12-pin IC pinout reference table
    - Update footprint to R_0603_1608Metric
    - VOUT = 0.6V × (1 + 22/3) = 5.00V exact
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2026-01-16 Fix critical PSU feedback resistor values in documentation
    CRITICAL: Previous values (R_FB1=16.2kΩ, R_FB2=3.01kΩ) were mathematically
    incorrect and would produce 3.83V instead of 5V. The KiCad schematic has
    the correct values.
    Corrections made:
    - R_FB1: 16.2kΩ → 22kΩ (LCSC C31850)
    - R_FB2: 3.01kΩ → 3kΩ (LCSC C4211)
    - Calculation: 0.6V × (1 + 22/3) = 5.0V ✓
    Additional updates:
    - L1 inductor: Updated to Bourns SRP1265A-2R2M (C2831487) as per KiCad
    - Q1 MOSFET: Added note about AO3400A/AO3404A compatibility
    - Added changelog section to track documentation versions
2026-01-16 Update component references to match KiCad schematic
    Changed component designators in documentation to match actual KiCad refs:
    - U1 → U10 (IP2721 PD Trigger)
    - U2 → U12 (SY8368AQQC Buck)
    - Q1 → Q3 (AO3404A MOSFET)
    - D1/D2 → D3/D4 (TVS protection)
    - J2 → J3 (Barrier Terminal)
    - Added J6 (J_MODE selector)
    Updated BOM tables with correct LCSC codes:
    - J1: C3020560 (GCT USB4105-GF-A)
    - D3: C20615788 (H7VN10B TVS)
    - D4: C113620 (SMBJ5.0A)
    - C_OUT: C52306 (25V rated)
2026-01-16 Add easyeda2kicad footprint library configuration
    Create fp-lib-table and easyeda2kicad.pretty folder to resolve
    missing footprints for SY8368AQQC (C207642) and SRP1265A-2R2M (C2831487).
    User needs to run easyeda2kicad commands to generate the .kicad_mod files.
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2026-03-03 Add VBUS 20V sensing and error LED to clock.ino
    - readVbusVoltage(): 16-sample average via ADC pin 9, ratio 9.393
    - checkVbusStatus(bootCheck): controls ERROR_LED (pin 2), logs to Serial
    - setup(): initialise pin, run boot check with detailed banner
    - loop(): periodic log every 30s (VBUS_LOG_INTERVAL_MS)
    - Threshold VBUS_20V_MIN=17.0V accounts for real-world 19.7V reading
    Serial output at boot:
    ┌─── VBUS STATUS ───────────────────┐
    │ Tensão medida : 19.7 V │
    │ Threshold 20V : 17.0 V │
    │ Estado : ✅ 20V PD OK │
    └────────────────────────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
    [clock.ino]
2026-03-03 Fix VBUS_SENSE_PIN: GPIO33 (IO33/ADC1_CH5), not GPIO9
    PCB connects voltage divider to IO33 as documented in POWER_SUPPLY_v3.md.
    GPIO9 was incorrect — caused 0V readings.
    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
    [clock.ino]
2026-03-03 fix(vbus): corrigir não-linearidade ADC do ESP32E com esp_adc_cal
    O ADC do ESP32 subestima tensões abaixo de ~0.8V em ~150mV de offset.
    Com o divisor 47k/5.6k, VBUS=5V produz ~0.53V no GPIO33 — nessa zona
    o erro amplificado pelo VDIV×9.4 resulta em ~1.4V (5V aparecia como 3.5V).
    A constante 3.1f também era incorrecta para ESP32E (full-scale ~3.9V com DB_11).
    Incorpora as correções do commit eb6c298 (branch add-vbus-sensing-5GkUn)
    re-aplicadas sobre o HEAD atual (evita conflito de merge).
    Alterações:
    - Adicionar <driver/adc.h> + <esp_adc_cal.h>
    - VBUS_SENSE_CHANNEL ADC1_CHANNEL_5 e adc_chars globais
    - readVbusVoltage(): adc1_get_raw + esp_adc_cal_raw_to_voltage (em mV)
    em vez de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
    [clock.ino]
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2026-03-05 docs(psu): bulletproof v4.1 — worst-case analysis, fix TVS D6, align BOM↔KiCad
    - Add worst-case VOUT analysis: ±2.8% (4.86–5.14V) with 1% FB resistors
    - Add SY8388ARHC protection specs (UVLO, OVP, OCP, OTP thresholds)
    - Add thermal analysis, ripple calculation, capacitor derating analysis
    - Fix D6 TVS value in KiCad: SMBJ5.0A → SMBJ24CA (24V, LCSC C19077558)
    - Fix TVS package: SMA → SMB (DO-214AA) matching KiCad footprint
    - Fix caps LCSC: C52306 (1210) → C12891 (1206) matching KiCad reality
    - Fix switching frequency: 500kHz → 600kHz per SY8388A datasheet
    - Add KiCad↔docs discrepancy table for reference designators
    - Update BOM_VERIFIED.md PSU section to align with all correc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
    [psu.kicad_sch]
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2026-03-05 feat(click-wheel): H3 optical IR sensor support + direction invert flag
    Adapta a lógica da click wheel para sensor óptico reflectivo/forked (H3):
    - ENCODER_INVERT_DIR em board_config.h: inverte CW/CCW sem re-soldar
    (útil se disco montado pelo avesso ou cores invertidas)
    - encoderISR: adiciona suporte ao flag com #if compile-time (zero overhead)
    - Comentário documenta polaridade do sinal com pull-up para sensor óptico:
    Dente (reflecte IR) → fototransístor conduz → GPIO LOW
    Gap (absorve IR) → fototransístor ao corte → GPIO HIGH
    Eléctrica idêntica ao EC11 mecânico → mesma ISR para H1/H2/H3
    https://claude.ai/code/session_01644xRqWMmbEneAhxNGnpGa
    [board_config.h, clock.ino]
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2026-03-09 feat(sound): motor chiptune LSDJ-inspirado para ESP32 + piezo passivo
    Implementa motor de áudio chiptune completo sem chips externos:
    - LEDC PWM (square wave) + timer ISR a 512 Hz como Game Boy frame sequencer
    - Sequenciador Song → Chain → Pattern → Step (estrutura LSDJ)
    - Arpeggio por time-division para polifonia simulada num único buzzer
    - LFSR 15-bit (idêntico ao Game Boy CH4) para canal de noise/percussão
    - Efeitos: vibrato, portamento, envelope de volume, duty cycle variável
    - Melodia de arranque pentatónica + alarme circadiano em 3 fases
    - Song de demonstração "Circadian" com melodia, baixo e percussão
    - BUZZER_PIN adicionado ao board_config.h (GPIO18 no clockv7 PCB)
    Pi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
    [board_config.h, clock.ino, sound.cpp]
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2026-03-12 Add click wheel support (encoder + center button) for brightness and mode control
    Replaces BOOT button with a rotary encoder + center button combo:
    - Rotation controls brightness (simple step-based, no momentum)
    - Center button press reuses existing handleButton() logic (short press = mode, long press = config)
    - Guarded by CLICK_WHEEL_ENABLED flag (easy to toggle back to BOOT button)
    - ESP32: GPIO32/35/34, Matrix Portal S3: GPIO9/10/11
    https://claude.ai/code/session_01BLfotpFbp7pGKfWjcLfbA3
    [board_config.h, clock.ino]
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2026-03-28 revert(click-wheel): remove código do firmware, consolidar decisões em CLICK_WHEEL.md
    Reverte alterações a clock.ino e board_config.h dos 3 commits anteriores.
    Pinout final (GPIO34/35/39), evolução de design e código de referência
    movidos para TODOs na documentação product/CLICK_WHEEL.md.
    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
    [board_config.h, clock.ino]
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2026-05-17 Add long-press behaviour to ESP32-C3 remote (time advance + brightness)
    Extends the mesh SyncSettings struct with flags + brightness + signed
    minute offset + master epoch (was 5 reserved bytes; now 19-byte struct).
    clock.ino applies remote brightness via setSafeBrightness() and adds a
    remoteTimeOffsetMin that is folded into displayAutoSolar(); the master
    broadcasts its own configBrightness/remoteTimeOffsetMin/epoch in
    sendSettings() so the C3 (and any new peer) inherit the live state.
    The C3 sketch now has a debounced press state machine:
    - Short press: cycles AUTO -> RED -> OFF (unchanged).
    - Long press in AUTO: accelerating clock advance (1->5->15->60 min per
    tick). Throttled broadcasts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
    [clock.ino, remote_c3.ino]
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2026-05-17 Default BOARD_MATRIXPORTAL_S3 to 0 and mark S3 as deprecated
    The Matrix Portal S3 path is no longer the target; development and
    production happen on the ESP32 Dev Module. Keeping the conditional
    branches in the source as historical reference, but flipping the
    default so a fresh checkout builds for the real board out of the box.
    [board_config.h]
2026-06-29 fix: RTC guarda hora standard (sem DST) para precisão solar internacional
    - syncWithNTP() agora define RTC = UTC + configTimezone (standard time)
    - displayAutoSolar() usa configTimezone diretamente (offset constante)
    - printSolarInfo() passa isDST=false ao Dusk2Dawn (coerente com RTC)
    - Remove função getPortugalDSTOffset() (demasiado específica)
    - Funciona em qualquer país: o offset RTC→UTC é sempre configTimezone
    [clock.ino]

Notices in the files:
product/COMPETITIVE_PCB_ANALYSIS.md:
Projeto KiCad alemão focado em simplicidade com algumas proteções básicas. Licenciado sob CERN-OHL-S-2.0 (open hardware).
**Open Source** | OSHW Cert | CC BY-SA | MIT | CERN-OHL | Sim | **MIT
